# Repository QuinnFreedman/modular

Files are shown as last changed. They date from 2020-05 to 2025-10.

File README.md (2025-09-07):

This project is an attempt to make Eurorack modular synthesis affordable and accessible to everyone.

This repository contains open source software and hardware schematics for Eurorack modules which are designed to be assembled easily and cheaply without any technical knowledge. Every module should be able to be assembled for around $20 in about an hour of work, even with limited experience.

To get started, check out some of the links below. Or get in touch! Send me a message at <a href="mailto:freemodular@gmail.com">freemodular@gmail.com</a>. Follow my <a href="https://www.reddit.com/user/FreeModular/submitted/">reddit</a>, <a href="https://freemodular.etsy.com/">Etsy shop</a>, or <a href="https://github.com/QuinnFreedman/modular">GitHub</a>.

**Happy travels on your modular journey!**




<a style="display:none" href="https://freemodular.org">Go to the website to see more</a>

<h2 style="display:none">Links</h2>
<ul class="fm-index-links-container">
  <li>
    <a href="https://freemodular.org/docs/about-eurorack" class="fm-hidden-link fm-index-link">
      About Eurorack
    </a>
  </li>
  <li>
    <a href="https://freemodular.org/docs/assembly" class="fm-hidden-link fm-index-link">
      Assembly Instructions
    </a>
  </li>
  <li>
    <a href="https://freemodular.org/docs/components" class="fm-hidden-link fm-index-link">
      Get Components
    </a>
  </li>
  <li>
    <a href="https://freemodular.org/docs/peripherals" class="fm-hidden-link fm-index-link">
      Accessories
    </a>
  </li>
  <li>
    <a href="https://freemodular.org/docs/appendixn" class="fm-hidden-link fm-index-link">
      Other Resources
    </a>
  </li>
  <li>
    <a href="https://freemodular.org/docs/license" class="fm-hidden-link fm-index-link">
      License
    </a>
  </li>
</ul>

<h2 style="display:none">Modules</h2>
<ul style="display:none">
  <li><a href="https://freemodular.org/modules/Clock">Clock</a></li>
  <li><a href="https://freemodular.org/modules/Envelope">Envelope</a></li>
  <li><a href="https://freemodular.org/modules/RNG">RNG</a></li>
  <li><a href="https://freemodular.org/modules/OffsetAtten">Offset/Atten</a></li>
  <li><a href="https://freemodular.org/modules/Mixer">Mixer</a></li>
  <li><a href="https://freemodular.org/modules/Output">Output</a></li>
  <li><a href="https://freemodular.org/modules/Drift">Drift</a></li>
  <li><a href="https://freemodular.org/modules/Boost">Boost</a></li>
</ul>

{% include_relative docs/modules.md %}

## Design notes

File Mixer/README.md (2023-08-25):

# Mixer

A simple 5-channel mixer for audio or CV.

mixer faceplate

## Manual

The top 4 channels are passed to the mixer via a mute switch and an attenuator knob. The 5th channel has a mute switch but no volume knob.

The volume knobs go from basically 0v (totally off) to nearly 100% volume (this mixer cannot provide any gain boost). In reality, the inputs are not buffered before they are attenuated so the volume may depend very slightly on the output impedance of the modules feeding into the mixer. Also, some potentiometers can't actually go all the way to zero so if you want the sound to be completely muted just use the switch, which will totally disconnect the signal.

The output *is* buffered, so this is an active (not passive) mixer.

Based on the [1163 Mini Mixer](https://www.lookmumnocomputer.com/projects#/1163-mini-mixer) by Look Mum No Computer.

### Daisy Chaining

Any number of mixer modules can be daisy chained together using the "chain in" and "chain out" connectors on the back. Make sure to keep the orentation (i.e. connect the top output to the top input and the bottom to the bottom). When chained together, the normalled output of one mixer is treated as a 6th input to the other. This means that when no patch cable is connected to the output of the first mixer, it's output is routed to the next mixer. When a jack is plugged into the output of the first mixer, it is removed from the seccond mix.

## Assembly 

### Components

See [components page](https://github.com/QuinnFreedman/modular/wiki/Components) for more info.

| Reference | Part | Value | Comment |
|---|---|---|--|
| R1-R9 | Resitor | 100kΩ | Any value is fine for these, as long as they are all the same. *Technically* R6 should be 99kΩ, but the difference wouldn't be noticable. |
| R10 | Resitor | 1kΩ | Output Impedence |
| R11 | Resitor | 470Ω | This controlls the LED brightness. Higher resistance value will make the LED dimmer. You might want to experement with a wide range of values up to 10k to dial in the right brightness for your LEDs. |
| RV1-RV4 | Potentiometer  | B100kΩ | Any value should work for these |
| J1-J6 | Jack Socket | PJ301M-12 |  |
| J7 | Power header | IDC male 2x8 |  |
| J8, J9 | Jumper headers | | **(Optional)** Chain multiple modules together by connecting OUT to IN. |
| U1 | Op-amp | TL072 |  |
| D1 | LED | 3mm | Optionally, you could use a bi-directional LED here. Using a normal LED as shown in the design, with anode on top, will only illuminate when the mixer is outputting a positive voltage. |
| C1, C2 | Capacitor | 100nf | **(Optional)** Power filtering |
| C3, C4 | Capacitor | 100nf | **(Optional)** Amp stabilization |
| C5, C6 | Capacitor | 10uf | **(Optional)** Power filtering |

### Instructions

See [general assembly instructions](https://github.com/QuinnFreedman/modular/wiki/Assembly).

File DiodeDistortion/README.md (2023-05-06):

# Diode Distortion
Super simple analog voltage-controlled distortion.



## Manual

This module distorts audio by soft-clipping it using a pair of diodes. It can also be used to smoothly clip control voltages if you build it without AC-coupling.

* **A** - Distortion amount
* **B** - CV input. Summed with Distortion knob position but may be non-linear.
* **C** - Signal input
* **D** - Signal output

## Assembly

### Components

See [components page](https://github.com/QuinnFreedman/modular/wiki/Components) for more info.

| Reference | Part | Value | Comment |
|---|---|---|--|
| R1-R3 | Resistor | 100kΩ |  |
| R4-R7 | Resistor | 10kΩ |  |
| R8,R9 | Resistor | 1kΩ |  |
| RV1 | Potentiometer | 100kΩ | If you don't have a 100k pot, just scale R2, R4, and R5 proportionally. |
| C1 | 1uF | Capacitor | Part of the AC-coupling. A lower value is also fine if that's all you have. |
| C2,C3 | 100pF | Capacitor | Stabilizing capacitor for amps. **Optional** |
| C4,C5 | 10uF | Capacitor | Power filtering capacitors. **Optional** |
| C6 | 100nF | Capacitor | Power filtering capacitor. **Optional** |
| D1,D2 | Diode | 1n4148 | Any diode with forward voltage <1v would probably work here, although the effect might be different. |
| U1 | Op-amp | TL074 |  |
| U2 | Opto-isolator | NSL-32 | This allows the control voltage to modify the distortion. If you don't have this exact part, any vactrol should be fine here. Or, you can make one by taping an LED to a light-dependent resistor. If you don't care about CV, you can also just leave this out. |
| J1-J3 | Jack socket | PJ301M-12 |  |
| J4 | Pin header | 2x5 |  |

### Instructions

See [general assembly instructions](https://github.com/QuinnFreedman/modular/wiki/Assembly).

#### AC-coupling 

The default design is AC-coupled, meaning it will ignore any constant offset voltage in an audio signal. But, it means it's not suitable for manipulating CV signals. If you want to use this module to clip CV signals (or if you want to be able to deliberately tweak it by adding an ofset to your audio) just **leave out R1 and replace C1 with a bit of wire**.

#### CV control

If you don't care about CV control, this module can be even simpler. Just leave out R9, R2, U3, and J3.

#### Schematic

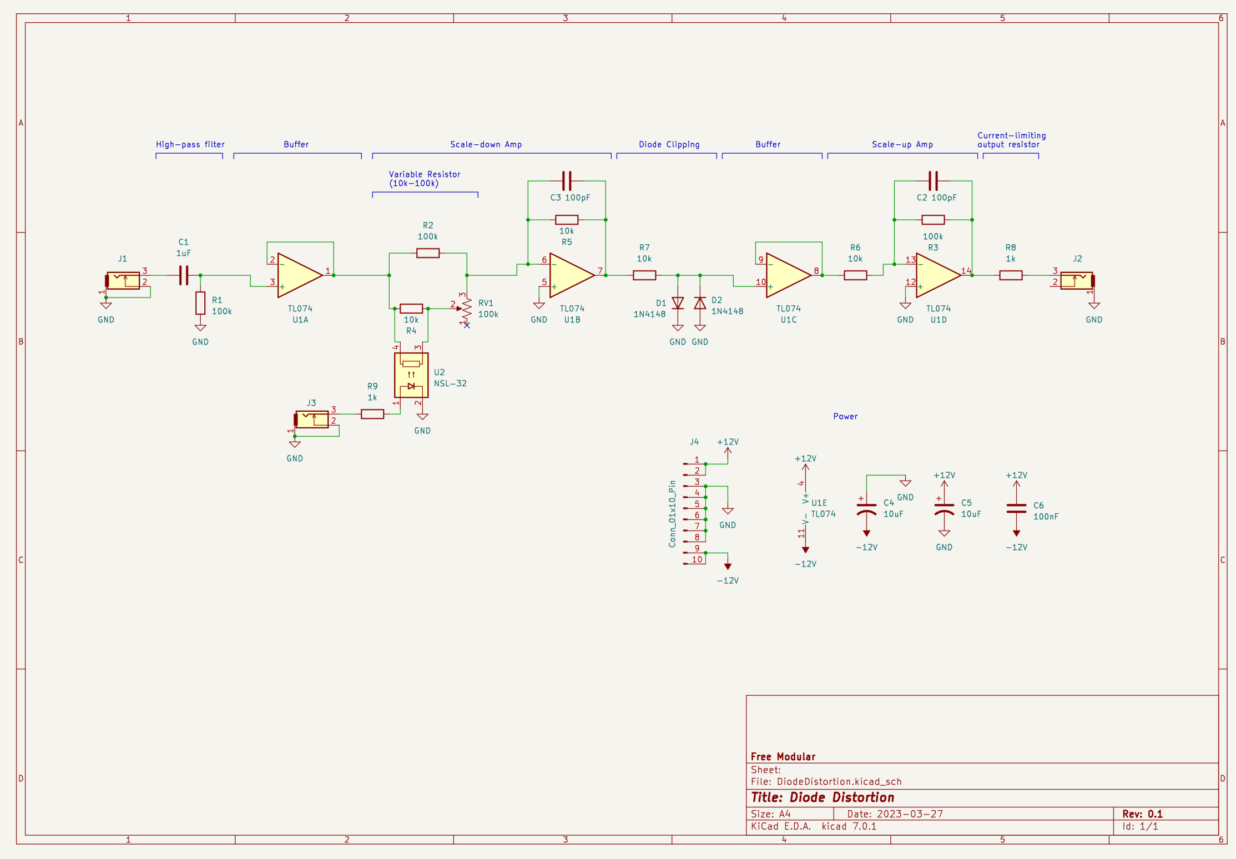
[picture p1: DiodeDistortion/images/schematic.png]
schematic


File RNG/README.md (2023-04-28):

# RNG

RNG stands for Random Number Generator. The ability to generate random control voltages is essential to creating generative music. However, purely random values can be noisy and chaotic. RNG lets you blend between looping old values and mutating them into new, random ones in a probabalistic way. It is inspired by Music Thing Modular's [Turing Machine](https://musicthing.co.uk/pages/turing.html) but with a lot of added functionality. In addition to outputting stepped random and/or looping values, RNG lets you blend between two channels of triggers/gates based on those values.

### Example uses

* Random melodies: Set Chaos to a low value and set the length to a small power of 2. Then, patch the output into a quantizer and use it as a pitch CV to generate looping but randomly generating melodies, synced with a clock.
* Drum multiplexer: Plug a drum trigger into Clock and patch A and B to trigger two different drum sounds. Then, when a drum trigger comes in it will be randomly sent to one channel or the other. This can be totally random or looping.
* Probabilistic sequencer: same as above but leave one output unconnected. This allows a sequencer without built in probability functionality to have some randomness.
* Random clock divider: Patch a steady clock into **Clock** and patch **B** out as the new clock with a high bias. This way, the clock pulses will occasionally not register, allowing two sequences to fall out of phase for syncopated polyrythms.
* Hook multiple RNGs together. Use the probabilistic clock from one of them to advance a random CV sequence from the other.

## Manual

RNG Faceplate

**(A) LEDs**. A row of LEDs across the top show the current sequence being played. Brighter LEDs correspond to higher values. The middle LED is the value currently being played.

**(B) Chaos**: Controls how much randomness in injected into the sequence. At zero (all the way left) the sequence is locked in a loop and no randomness is added. All the way to the right, each value played is completely random. In the middle, values will be played from the saved loop but with a chance of mutating each time they are played.

**(C) Length**: A rotary encoder that allows you to control the length of the sequence. When you turn the knob, the length of the sequence will be displayed in binary on the top row of LEDs. Hold the knob down to quickly skip between powers of twos. If set to a negative number (indicated with a HIGH value on the far left bit) then the sequence will "yoyo," playing alternatingly forward and backward.

### Left Side

Stepped voltage mode. This half of the module outputs a stepped random voltage 

**(D) Range**: The range/spread of the random voltages output. This is a digital scaling that is applied before the signal is output. This means that theoretically if you turned the range way down and then boosted it way back up with a VCA, you could get some digital artifacts. But, it also means that via firmware updates this could be reconfigured to effect the range or distribution of new values that are created instead of scaling the output.

**(E) Bi/unipolar**: Determines whether the values are unipolar (0 to +10v) or bipolar (-10v to +10v)

**(F) Clock** (input): Whenever HIGH, the values are advanced by one, a new value from the loop is played (and maybe mutated).

**(G) CV** (input): Control voltage to control the Chaos parameter. There are two configurable modes. It can either act as a direct CV (i.e. higher values = more randomness) or as a lock gate so it has no effect when LOW and then locks the sequence in place and prevents any mutation when HIGH.

**(H) Out** (output): Stepped random voltage output.

### Right Side

Binary choice mode. This side of the module randomly chooses between two output trigger/gates based on the value of the left side.

**(I) Bias**: The probability of outputting to channel A vs B. In practice, this input is interpreted as a threshold value. Whenever an output would be generated that is above the threshold, channel A is triggered. When it is below, channel B is triggered.

**(J) Trigger/Gate**: Chooses whether the A/B outputs should be triggers (a short voltage spike with every new clock pulse) or gates (remain steadily high until the output channel is changed). THe duration of the triggers is configurable in the firmware.

**(K) Bias** (input): Addative CV control for the Bias knob

**(L/M) A** & **B** (output): Two channels of gate/trigger output. A corresponding LED lights up when each gate is open.

## Assembly

See [general assembly instructions](https://github.com/QuinnFreedman/modular/wiki/Assembly).

### Components

See [components page](https://github.com/QuinnFreedman/modular/wiki/Components) for more info.

| Reference | PCB | Part | Value | Comment |
|---|---|---|---|--|
| R1,R2 | Front | Resistor | 100kΩ |  |
| R3,R4 | Front | Resistor | 1kΩ |  |
| R5-R8 | Front | Resistor | ~1kΩ | These resistors control the brightness of the four bottom LEDs. Their value might depend on which LEDs you use. Increasing their value will decrease the brightness. |
| R9,R11-R13,R16| Back  | Resistor | 100kΩ |  |
| R10 | Back  | Resistor | ~1kΩ | This resistor controls the brightness of all 7 top LEDs. Higher value = dimmer light |
| R14,R15 | Back  | Resistor | 50kΩ |  |
| R17 | Back  | Resistor | 470Ω |  |
| RV1-RV3 | Front | Potentiometer  | 50kΩ Linear| The value of these potentiometers doesn't really matter. `R14` and `R2` just need to be scaled to match `RV2`. So, for example, if `RV2` is 100kΩ, then `R2` should be 200kΩ and `R14` should be 100kΩ. |
| SW1 | Front | Rotary Encoder | CTY1100 or similar |  |
| SW2,SW3 | Front | Switch | TAIWAY 200CWMSP1T3B4M2 | Any SPDT switch would work here. I use [TAIWAY 200-series](https://www.taiway.com/resource/annexes/product_items/74/856052d1ea82867d7e77babb534d1633.pdf) "sub-miniature" switches because they fit behind the faceplate. The pin pitch on the PCB is 0.1in.|
| D1-D11 | Front | LED | 3mm |  |
| J1-J6 | Front | Jack | PJ301M-12  |  |
| J7-J10 | Both  | Stacking pin headers | 1x6, 1x7, 1x8, 2x3 | Cut headers to size. You can just use two rows of headers for the 2x3. You can get matching male/female pairs for a detachable connection (recommended) or just use male headers for a soldered connection. |
| J11 | Back  | Power connector| IDC male 2x8 shrouded | Or, use two rows of male pin headers |
| C1-C4 | Back  | Capacitor | 100nF | C2-C4 are optional noise-reducing bypass capacitors |
| C5-C7 | Back  | Capacitor | 10uF | Optional noise-reduction |
| U1 | Back  | LED controller | TLC5940NT  |  |
| U2 | Back  | DAC | MCP4922 |  |
| U3 | Back  | Op-amp | MCP6002 |  |
| U4 | Back  | Op-amp | TL074 |  |
| U5 | Back  | Voltage regulator | LM4040BCZ-5 (5v) |  |
| A1 | Back  | Arduino nano | v3.0 |  |

## Requirements

Arduino IDE 1.8.10 

|Library | Author | Version |
|---|---|---|
| [SPI][1] | Arduino | |
| [TLC5940][2] | Paul Stoffregen | 1.1.1 |

[1]: https://www.arduino.cc/en/reference/SPI
[2]: https://github.com/PaulStoffregen/Tlc5940

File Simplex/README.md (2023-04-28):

# Simplex

Simplex generates two channels of smooth random voltage based on the simplex noise* algorithm. Simplex noise produces values that are alway in motion but never change abruptly and never repeat. It's great for adding some subtle, organic parameter moodulation to your patch or for generating random melodies and arpeggios.

Simplex Faceplate

## Manual

### (A) Speed

Controls how quickly both channels move through time. This is like the frequency on an LFO except that the output will never repeat. A higher speed value means that the noise will varry more sharply.

### (B) Texture

Controls how "smooth" or "rough" the noise is for both channels. Texture works by adding more layers of noise with higher frequency and lower amplitude -- essentailly like overtones or harmonics in audio. If you just want "basic" smooth noise, put texture all the way to the left. If you want to have some large fluctuations over a very slow time scale while still having some quick organic jitter on top, move it towards the right. Here is a graph of output values with texture low (left) and high (right).

|Simplex noise with texture off | Simplex noise with texture high |
|---|---|
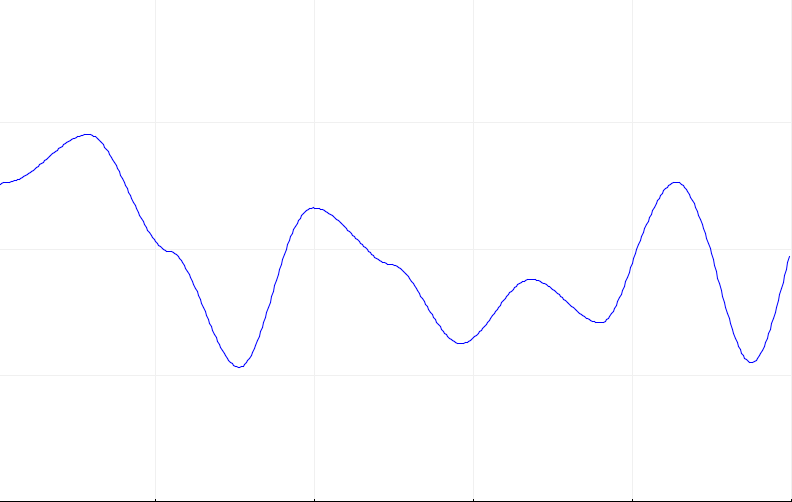
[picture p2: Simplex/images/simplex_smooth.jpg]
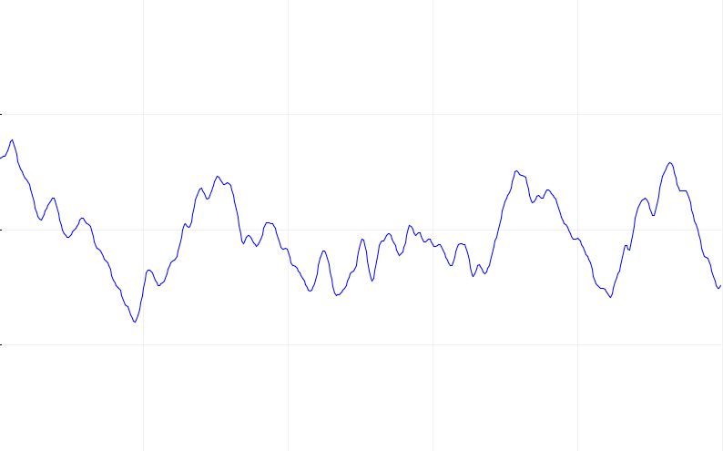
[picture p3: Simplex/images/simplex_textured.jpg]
| | 

### (C) Amplitude

Attenuates the range of output channel A. (Channel B is fixed).

### (D) Speed CV [input]

CV control for speed (both channels). 0-5v. Input is added to the speed potentiomeer value, capped at 5v.

### (E) Texture CV [input]

CV control for texture (both channels). 0-5v. Input is added to the texture potentiomeer value, capped at 5v.

### (F) & (G) Outputs

There are two output channels. Both channels will have the same speed and texture, but will be completely separate from each other.

* **A**: Channel A. -10v - +10v, attenuated by **Amplitude (C)**
* **B**: Channel B. 0-5v

## LFO Mode

This same hardware can be loaded with different firmware to function as a dual LFO. To do so, just open `config.h` and replace the line `#define FIRMWARE_MODE FIRMWARE_MODE_SIMPLEX` with `#define FIRMWARE_MODE FIRMWARE_MODE_LFO`. In LFO mode, the module has two very simple independently rate-controlled triangle LFOs. They DO NOT tract V/Oct and don't have many fancy features like tempo sync, etc. If there is a demand, I might add some of those features. For now, it's a great way to get some extra functionality out of this PCB if you had to buy multiples.

In LFO mode, the controls are as follows:

### (A) Speed A

Control of the speed of the left channel (channel A)

### (B) Speed B

Control of the speed of the right channel (channel B)

### (C) Amplitude

By default, this attenuates the range of output channel A. (Channel B is fixed). If you prefer, this can be configured to control the waveform of channel A instead. See `config.h` for configuration options.

### (D) & (E) Speed CV [input]

CV control for speed for both channels. 0-5v. Input is added to the respective speed potentiomeer value, capped at 5v. These are linear and do not track v/oct.

### (F) & (G) Outputs

There are two triangle LFO output channels, **A**, and **B**. 

* **A**: Channel A. -10v - +10v, attenuated by **Amplitude (C)**
* **B**: Channel B. 0-5v

## Assembly

### Components

See [components page](https://github.com/QuinnFreedman/modular/wiki/Components) for more info.

#### Front PCB

| Reference | Part | Value | Comment |
|---|---|---|--|
| R1,R2 | Resistor | 1kΩ |  |
| R3,R4 | Resistor | 5.1kΩ | Control LED brightness. Higher values makes the lights dimmer |
| RV1-RV3 | Potentiometer  | 50kΩ linear| Value does not matter. Any value is fine here |
| D1,D2 | LED | 3mm |  |
| J1-J4 | Jack | PJ301M-12  |  |
| J5-J6 | Stacking pin headers | 1x7, 1x3 |  |

#### Front PCB

| Reference | Part | Value | Comment |
|---|---|---|--|
| R1-R5 | Resistor | 10kΩ | The value doesn't relaly matter as long as they are all the same |
| U1 | Op-amp | TL072 |  |
| U2 | Op-amp | MCP6002 |  |
| U3 | DAC | MCP4922 |  |
| A1 | Arduino Nano | v3.0 |  |
| J5-J6 | Stacking pin headers | 1x7, 1x3 |  |
| J1 | Power connector| IDC male 2x8 shrouded | Or, use two rows of male pin headers |
| C1,C2 | Capacitor | 100nF | **Optional** noise-reducing power-filtering capacitors |
| C3-C5 | Capacitor | 10uF | **Optional** noise-reducing power-filtering capacitors |

### Instructions

See [general assembly instructions](https://github.com/QuinnFreedman/modular/wiki/Assembly).

The capacitors are intended to remove noise from the power supply. But, with my power supply, I was not able to even measure a difference. You can just leave them out if you want, or put in multiple capacitors of different values in parallel if you want to experement.

The long jumper wire in the PCB design is to connect the signal to the left LED. If you want the 2 LEDs to be identical, connect it with a wire as shown in the Fritzing PCB view, from J1 to J3. If you want to use a bipolar LED for the left channel (so it will be a different color when the output is negative), instead connect the bottom jumper wire terminal with the top of the 1k resistor right next to it (J2 to J3). You will probably also want to replace the adjacent 220Ohm resistor with something approx 2x larger since the voltage will be [-10v,+10v] instead of [0,+5v].

The stacking headers that hold the 3 layers together are not evenly spaced. You may want to additionally use some standoffs in provided the holes to keep the panels from coming apart when you push on them. Make sure the standoffs aren't too tall or they could separate the headers so the don't make a good contact.

## Requirements

Arduino IDE 1.8.10 

|Library | Author | Version |
|---|---|---|
| [SPI][1] | Arduino  | |

[1]: https://www.arduino.cc/en/reference/SPI

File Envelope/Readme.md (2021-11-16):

# Envelope

A simple but powerful envelope generator with 4 modes. Can be used as a linear ADSR or exponential AD, looping or not.



# Manual

### (A) Mode Select Button

This button lets you cycle between the four modes. While pressing the button, the LEDs will illuminate to indicate which mode is selected.

### (B) LEDs

While selecting modes, the LEDs will show the active mode:
1. **(yellow)** ADSR mode
2. **(blue)** AARR mode
3. **(red)** AARR Loop mode
4. **(green)** TRAP mode

Once a mode is selected, the LEDs will show which phase the envelope is in. At any given time, the LEDs are illuminated corrosponding to the knobs/inputs that control the current phase in the current mode.

### (C) Knobs & CV input

There are 4 knobs, each with CV control from 0-5v. They control different parameters of the envelope. Their function changes based on the mode of operation. See the diagrams below for more. They are colored (1) Yellow, (2) Blue, (3) Red, (4) Green.

| Knob | ADSR | AARR | AARR Loop | TRAP Loop |
| --- | --- | --- | --- | --- |
| (1) Yellow | Attack time | Attack time | Attack time | Attack time |
| (2) Blue | Decay time | Attack rate | Attack rate | Sustain *time*  |
| (3) Red | Sustain *value* | Release time | Release time | Release time |
| (4) Green  | Release time | Release rate | Release rate | Delay time |

### (D) Gate [input]

In a non-looping mode, the gate is the the main way you interact with the envelope. When the gate is HIGH, the envelope will start to open up and will stay open (high) until the gate is set LOW. If the gate is only triggered breifly, the attack can be interupted so the envelope may never open fully.

In a looping mode, by default, the gate will stop the envelope looping as long as it is HIGH. The firmware can also be configured to *only* loop while the gate is high instead.

### (E) Ping (aka retrigger) [input]

This is a trigger input. When it recieves a trigger, it will cause the envelope to open. If the gate is closed, sending a trigger will just cause the envelope to fully open and then close again. If the gate is on, sending a trigger to ping will keep the envelope open, but will "re-trigger" it. For example, if the envelope was in a Sustain phase, re-trigger will briefly set the envelope back to 100% and then it will decay back to the Sustain level.

### (F) Out [output]

The main output. Outputs analog values between 0-5v.

### (G) Inv [output]

Outputs an inverted version of the main out, but transposed to also be between 0-5v. I.e. INV will he HIGH when OUT is LOW and LOW when OUT is HIGH. This is useful for sidechaining and other ducking.

# Modes

## ADSR mode

<p align="center" width="100%">
    ADSR graph
</p>

ADSR is a "standard" linear envelope mode with attack, decay, sustain, and release controlled by the 4 inputs, respectively.

## AARR mode

<p align="center" width="100%">
    AARR graph
</p>

AARR (or A,A',R,R') mode gives up control of the decay and sustain. Instead, knobs (2) and (4) are used to control the exponential rate of the attack & release. These controls can go through zero, so both attack and decay can be either exponential or logarithmic.

## AARR Loop mode

<p align="center" width="100%">
    AARR graph
</p>

AARR Loop is exactly like AARR mode except that it loops continuously. It goes back and forth between Attack and Release (no sustain), so it is always rising or falling.

## TRAP Loop mode

<p align="center" width="100%">
    TRAP graph
</p>

This mode could be called ASRD for Attack/Sustain/Release/Delay, but I call it TRAP for "trapezoid" to remove confusion. This mode is another looping mode where you can control how long the envelope stays HIGH and LOW between Attack/Decay in the loop. This lets you create a pulse-width modulated square wave or saw wave, or any other simple waveform.

# Assembly

### Components

See [components page](https://github.com/QuinnFreedman/modular/wiki/Components) for more info.

#### Front PCB

| Reference | Part | Value | Comment |
| --- | ---- | ----- | --- |
| R1-R8 | Resistor | 100kΩ | |
| RV1-RV4 | Potentiometer | B10kΩ | Other values would probably be fine here. |
| D1-D4 | LED | | |
| J1-J8 | Jack socket | PJ301M-12 | |
| S1 | Button | | You can use any panel-mount OFF-(ON) style push button here as long as it fits. There is breakaway section of the PCB to make room for the button. The two pins of the button will need to be soldered two the two holes marked "S1" via a bit of insulated wire. It does not matter which lead of the button connects to which hole as long as the button will connect the two points together when pressed. |
| J9-J10 | Pin headers | | Male/female pin headers to connect the front and back PCB boards |

#### Back PCB

| Reference | Part | Value | Comment |
| --- | ---- | ----- | --- |
| R1-R8 | Resistor | 100kΩ | |
| R9,R10 | Resistor | 1kΩ | Controls output impedance |
| R11-R14 | Resistor | 10kΩ | |
| R15 | Resistor | 470Ω | Goes with the voltage reference shunt. A different value might be more optimal and/or power efficient |
| Q1,Q2 | NPN Transistor | 2N3904 | |
| U1 | Op-amp | MCP6004 | |
| U2 | DAC | MCP4922 | |
| U3 | Shunt voltage ref | LM4040LP-5 | |
| C1-C4 | Capacitor | 10nF | **(Optional)** Help potentially reduce noise & feedback in input CV circuitry |
| C5 | Capacitor | 100nF | Goes with the voltage reference shunt |
| C6 | Capacitor | 100nF | **(Optional)** Bypass capacitor to reduce noise in the power supply |
| C7 | Capacitor | 10nF | **(Optional)** Bypass capacitor to reduce noise in the power supply |
| J9-J10 | Pin headers | | Male/female pin headers to connect the front and back PCB boards |
| J1 | Pin headers | | 2x8 shrouded male Eurorack power connector |
| J2 | Solder points | | Optional points to solder on connections for extra features |

### Instructions

See [general assembly instructions](https://github.com/QuinnFreedman/modular/wiki/Assembly).

### Customization & Hidden Features

There are a lot of configurable options in the `config.h` file. Edit them before uploading the firmware to chenge the behavior of the module. There are also two unused pins on the Arduino (A4 and A5) which can be set to perform other functions like end-of-rise and end-of-fall triggers if you want to make an expander or add some more inputs to the faceplate.

#### `ANALOG_READ_MAX_VALUE` and `ANALOG_READ_MIN_VALUE`

When the Arduino reads an analog value, it will get a number between 0 and 1024. However, the potentiometers might not go all the way from exactly 0 volts to exactly 5 volts. If you want to be able to totally max out a parameter (like setting the sustain at actually 100%) you can set these parameters to adjust what range the Arduino will expect. For example, if you set `ANALOG_READ_MIN_VALUE = 15`, then any raw value &le;15 will be considdered 0 volts.

#### `ATTACK_MAX_DURATION_MICROS`, `ATTACK_MIN_DURATION_MICROS`, etc...

When detecting a maximum or minimum voltage (as given by the parameters above), these parameters dictate what value that should corrospond to in the envelope.

By default, all of the times can be turned down all the way to zero, which means that the envelope will skip that segment entirely. But, this means that if you set all the knobs to zero the envelope will skip every stage and essentially not work. Setting the minimum values to even just 1 microseccond will force the envelope to actually run through that stage as fast as it can, which will probably get you the fastest LFO. Or, set it to a higher minimum if you always want a little slew in your envelope.

#### `EXP_RATE_SCALE`

How extreme the max log/exp curve is. Default: 4 Must be &gt; 0. The formula for the exponential curve is given by:



Where `t` is time, `k` is knob position, and `r` is `EXP_RATE_SCALE`.

#### `LOOP_WHEN_GATE_OFF`

If `true`, then the looping modes will loop when the GATE input is LOW and will pause/not loop when the GATE is HIGH. If `false`, the opposite is ture. Looping on GATE HIGH probably makes more sense in a vacuum, but GATE is normalled LOW (for the non-looping modes) which makes looping on HIGH inconvenient.

#### `LOOP_HARD_SYNC_ON_PING`

If `true`, recieving a "ping"/"retrigger" pulse while in a looping mode will cause a hard sync (i.e. go back to the beginning of the loop). If `false`, this trigger will cause the LFO to go smoothly into attack mode.

### AUX Pins

There are two unused pins on the arduino (A4 and A5) that can be configured to perform a number of features.

#### EOR and EOF triggers

If these modes are enabled, the Arduino will send short triggers to the two aux pins at the end of the rise and fall of the envelope. EOR will always trigger right after the attack phase ends (or would end if attack time is zero). EOF will trigger at the end of the release. in ADSR mode, if sustain is zero, then this means that EOF will trigger when the gate is turned off, which might be after the envelope has gone to zero.

#### Gate passthrough (`GATE_PASSTHROUGH_ENABLED true`)

When enabled, the aux pin will be triggered as long as the input gate is HIGH. This is output after the gate signal has been processed by the computer, so it may be a few milisecconds delayed from the GATE input and is pretty much a totally separate circuit. This can be useful for an LED indicator.

#### LED mode indicator (`LED_MODE_INDICATOR_ENABLED true`)

When enabled, the aux win will be held HIGH whenever the LEDs are displaying the mode (instead of the phase). This could be used to add an indicator LED or light-up button if it is confusing what state the display is in.

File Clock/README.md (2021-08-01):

# Clock

A clock module sends rythmic voltage pulses at different subdevisions or multiples of a given tempo. If you want to have any kind a syncronous tempo to your music, use a clock to drive all your other modules and keep them in sync. You can use a clock output to step a sequencer or plug it directly into gate and trigger inputs.

This clock module is loosly inspired by ALM's [Pamela's NEW Workout](https://busycircuits.com/alm017/) but it is much simpler (and thus super easy to build). It has 8 channels of clocked gates, with per-channel control of clock division, pulse width, phase shift, and swing. The outputs can only be gates (high or low) -- there are no other LFO shapes or patterns available, which cuts down on parts. There are no CV inputs by default, but they could easily be added by an expander.

## Manual


### (A) OLDED Screen

Displays menu with configurable screensaver animation

### (B) Encoder

Navigates the menu. Turn to move up/down. Click to select an item. Long-hold (.5 secconds) to enter or exit a sub-menu.

### (C) Outputs.

8 digital gate output channels (0-5v).

### Menu

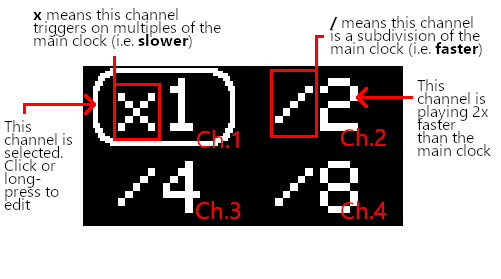
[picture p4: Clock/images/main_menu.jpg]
main menu


Scroll to move between the differnt channels and the global BPM. Click to edit the BPM or clock division. Click again to go back to navigating.

Hold the button down for .5 secconds to get an extended menu for any channel. This menu lets you edit more propperties of the channel. Long press again to get out.

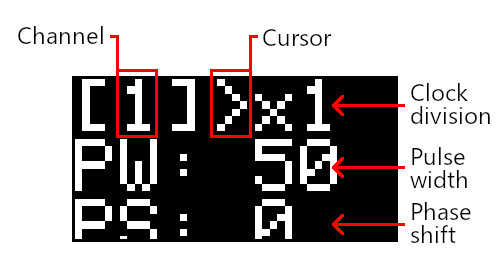
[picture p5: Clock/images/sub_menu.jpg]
sub menu


| Property | Abberviation | Details |
|---|---|---|
| Division | | The clock division sets the frequency of the channel. A value of `xN` will hit on every Nth beat of the refference clock. A value of `/N` will run N times for every cycle of the main clock. If this notation is counterintuitive to you, you can change it in configuration. This value only increments in powers of two in the main menu, but you can set odd values in the details menu.
| Pulse Width | PW | Controls how long the gate will be on. By default, each channel has a pulse width of 50 which means that it will be on for half of each cycle. If you just want a short trigger, lower this value.
| Phase Shift | PS | Controls how in/out of phase the channel is. A value of 0 means that the channel will open its gate on the exact multiple of the master clock. A positive value means it will open a little late, and a negative value will open early. The value is a percentage of *this channel*'s period, so a value of 50 will be fully out of phase or "inverted". This means that two channels with the same PS value but different clock divisions won't be in sync with eachother..
| Swing | SW | Swing is like phase shift but it only effects *every other* cycle of the channel. A channel with swing will be non-uniform. If swing is too high and pulse width isn't reduced the gate opening for the odd beats can run right into the one for the even beats, which might make it look like the clock time was just doubled. Similarly, negative swing can stretch the gate. Negative swing is disabled by default for this reason (enable it in configuration).

## Assembly

Here is a video walking you through the assembly process:

| YouTube video (http://www.youtube.com/watch?v=Xvwd0_08juQ "Video Title") |
|:----------------:|
|**Clock module assembly guide**|

See [general assembly instructions](https://github.com/QuinnFreedman/modular/wiki/Assembly).

### Components

See [components page](https://github.com/QuinnFreedman/modular/wiki/Components) for more info.

* 16 Resistors (see below for values)
* 8 Jacks
* 8 LEDs
* 1 I2C 128x64 OLED display ([Available here](https://www.amazon.com/IZOKEE-Display-SSD1306-Raspberry-White-IIC/dp/B076PDVFQD/))
* 1 Rotary encoder
* 1 Arduino Nano

### Orientation

Position the Arduino with the USB port facing downward (match the square solder pads on the Arduino to the square pad on the PCB).

Insert the LEDs with the short legs (cathodes) facing the flat side of the circles in the PCB silkscreen (aka downward when the module is mounted in the rack).

Put in the screen "upside down" with the pins at the bottom.

Put all the components on the side of each PCB with the sikscreen markings. The copper traces of the two boards should face each other.

### Resistor values

The resistors in this module can be basically any value you want. The vertical resitors (R9-R16) control the brightness of the LEDs. They can be as low as 220 Ohms for a very bright LED to 10k for a very dim one. The best value might depend on the LEDs you have.

The horizontal resistors (R1-R8) control the output imedance. This essentially slows down the flow of electricity out of the Arduino to protect it from getting overloaded if the outputs are ever connected to ground. From what I understand, `1k` is the closest to a "standard" output impedance for Eurorack, but especially for gate signals it really doesn't matter. Feel free to use whatever resistors you used for the LEDs.

### The screen

There are many OLED displays that could work with this module. Just make sure the one you get connects via I²C instead of Serial (4 wires instead of many). The one I got ([here](https://www.amazon.com/IZOKEE-Display-SSD1306-Raspberry-White-IIC/dp/B076PDVFQD/)) is .96" but you could easily fit a larger one if you re-design the faceplate slightly.

Make sure that the pins of your screen are in the same order as the labels printed on the PCB. If not, you may need to attach it with wires instead of a header so you can twist them around to make the right connections.

The screen will need to sit up above the PCB. If you are using a header, it may be easiest to bolt it to the faceplate first and then solder it on to the PCB at the right height.

The screen you buy will also have an I²C address that lets the Arduino communicate with the screen. Mine was `0x3C`. Check the manufacturer info to find your address. Enter it in at the very bottom of the `config.h` file.

## Extra features

There are a lot of configurable options defined in `config.h`. Edit it with Arduino IDE (or any other text editor). They should be self-explanitory based on their comments.

In addition there are a couple features that the hardware and software supports that I couln't find room for in the PCB or faceplate. You could put them in an expander module or put them instead of something else.

These features must be enabled in configuration.

### Pause button

Connecting pin D6 on the Arduino to GROUND will pause or un-pause the clock. Attatch a momentary push button to the output for D6 and attatch the other end to GROUND.

When the module is paused, D7 will be set HIGH (5v). You can use this to turn on an LED, a CV gate output, or both. If you prefer, you can configre it to be HIGH when the module is **not** paused. In either case, make sure to add a resistor to the output.

### Sync (follow mode) input and/or tap tempo

When you connect the D8 pin to 5v multiple times, the clock's tempo will be set to the durration between those triggers. This can be used to make a tap-tempo button and/or an input to follow an external clock (or both!).

In both cases, you will need to tie D8 to GROUND via a pulldown resistor (~10k).

#### Follow mode

If you are attatcing an external input to the module, you will need some mechanism to ensure that the voltage never goes outside of 0-5v. A transistor or opto-isolator (vactrol) should work.

#### Tap tempo

If you are just implementing a tap tempo button and don't want to solder on a pulldown resistor, you can set the pin mode of D8 ot `INPUT_PULLUP` in `setup()` in Clock.ino. Then, use a button to connect the pin to GROUND instead.

## Requirements

Arduino IDE 1.8.10 

|Library | Author | Version |
|---|---|---|
| [Adafruit SSD1306][1] | Adafruit | 2.2.0 |
| [Adafruit GFX][2] | Adafruit | 1.7.5 |

[1]: https://github.com/adafruit/Adafruit_SSD1306
[2]: https://github.com/adafruit/Adafruit-GFX-Library

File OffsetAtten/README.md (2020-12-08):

# Offset/Attenuvert

OA Faceplate

O/A is a small, analog utility module to manipulate the magnitude and level of a CV signal. For example, if you had an LFO going between (-5v - +5v), you could manipulate it to be between (+5v and +7v).

There are two identical halves, each with an offset knob and an attenvert knob.

### (A) Offset

Offset adds or subtracts an amount from the signal, from -10v to +10v.

For a CV signal, this will control the level of the signal.

For an audio signal, this will likely have no effect unless you push it far enough to clip at the edge of Eurorack's +/-10v range. In some cases, you could add a small amount to an audio signal to change how it is processed by an effect, like a wavefolder.

### (B) Attenuvert

"Attenuvert" is a mix of attenuate and invert. All the way right, the signal is passed through unaffected. At 12 o'clock, the signal is completely muted. All the way to the left, the signal is output at full volume but inverted.

### (C) Input

Audio or CV input

### (D) Output

Outputs the attenverted signal. LED indicates the level of the output signal.

## Assembly

### Components

See [components page](https://github.com/QuinnFreedman/modular/wiki/Components) for more info.

* Resistors
  * 10x 10kohm (or any value as long as they all match -- 1k is fine)
  * 2x 1kohm (controls output impedance)
  * 2x 470ohm (controls LED brightness -- I would actually reccomend something more like 1k-1.4k for dimmer LEDs)
* 4 Potentiometers (any value)
* 4 Jacks
* 2 Bi-directional LEDs (or regular LEDs if you can't find any)
* 1 TL074
* 2 10uF capacitors (optional)
* 1 100nf capacitor (optional)
* m/f stacking headers and 1 2x5 shrouded header.
    * You can also use a 2x8 shrouded header and cut off the top 6 pins.
* small standoff screws (optional)

### Instructions

See [general assembly instructions](https://github.com/QuinnFreedman/modular/wiki/Assembly).

The 100nf capacitor is meant to go on the back side of the panel, on the opposite side of the TL074.

Bidirectional or bipolar LEDs will show a different color when the output is negative or positive. If you put in regualr LEDs, they will only light up when the output is positive.

The stacking headers are only one one side of the module, so for stability you might want to use some small standoff screws to connect the other side of the two PCBs together. Their height should be approximately equal to the height of the stacking headers. There are a few hols in the PCB for this. Make sure that the screws don't touch the metal of the potentiometers or anthing else conductive. You could use plastic washers or bend some of the potentometer housings to avoid this, or only use one or two of the holes.

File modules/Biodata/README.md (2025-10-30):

<div class="fm-readme-container">
<div class="fm-row">



<div class="fm-readme-text">

<h1>Biodata</h1>

<p>Listen to plants! Generate pitch CV, gates, and raw waveforms from any biological signal. Using TENS cables (with clips or pads), Biodata listens to plants, fungi, people, or even other electronics. Based on the fluctuating electrical resistance between the probes as the subject moves or photosynthesizes, Biodata will generate quantized pitch CV and gates, as well as a raw waveform and smooth CV.</p>

<h2>Resources</h2>

<ul>
  <li><a href="https://quinnfreedman.github.io/fm-artifacts/Biodata/biodata_manual.pdf">Manual</a></li>
  <li><a href="https://quinnfreedman.github.io/modular/modules/Biodata/docs/assembly_instructions">Assembly instructions and BOM</a></li>
  <li>Interactive BOM: <a href="https://quinnfreedman.github.io/fm-artifacts/Biodata/biodata_front_pcb_interactive_bom.html">front panel</a>, <a href="https://quinnfreedman.github.io/fm-artifacts/Biodata/biodata_back_pcb_interactive_bom.html">back panel</a></li>
  <li><a href="https://quinnfreedman.github.io/fm-artifacts/Biodata/biodata_faceplate.svg">Faceplate stencil SVG</a></li>
  <li>GERBER files:
    <ul>
      <li>Faceplate: <a href="https://quinnfreedman.github.io/fm-artifacts/Biodata/biodata_faceplate_jlcpcb.zip">JLCPCB</a>, <a href="https://quinnfreedman.github.io/fm-artifacts/Biodata/biodata_faceplate_pcbway.zip">PCBway</a></li>
      <li>Front panel: <a href="https://quinnfreedman.github.io/fm-artifacts/Biodata/biodata_pcb_front_jlcpcb.zip">JLCPCB</a>, <a href="https://quinnfreedman.github.io/fm-artifacts/Biodata/biodata_pcb_front_pcbway.zip">PCBway</a></li>
      <li>Back panel: <a href="https://quinnfreedman.github.io/fm-artifacts/Biodata/biodata_pcb_back_jlcpcb.zip">JLCPCB</a>, <a href="https://quinnfreedman.github.io/fm-artifacts/Biodata/biodata_pcb_back_pcbway.zip">PCBway</a></li>
    </ul>
  </li>
  <li><a href="https://freemodular.org/modules/Biodata/fm_biodata_tayda_bom.csv">Tayda quick-order CSV</a> (incomplete)</li>
  <li><a href="https://quinnfreedman.github.io/fm-artifacts/Biodata/fm-biodata.hex">Firmware HEX</a></li>
  <li><a href="https://github.com/QuinnFreedman/modular/tree/main/modules/Biodata">Source code</a></li>
  <li><a href="https://quinnfreedman.github.io/fm-artifacts/Biodata/biodata_schematic.pdf">Schematic</a></li>
</ul>

</div>
</div>

<h2>Details</h2>

<b>DIY difficulty:</b> Easy<br>
<b>HP:</b> 6<br>
<b>Power usage:</b>
<table class="fm-current-table">
  <tr>
    <th></th>
    <th>Typical current</th>
    <th>Absolute maximum current</th>
  </tr>
  <tr>
    <td>+5V</td>
    <td>65mA</td>
    <td>75mA</td>
  </tr>
  <tr>
    <td>+12V</td>
    <td>4mA</td>
    <td>24mA</td>
  </tr>
  <tr>
    <td>-12V</td>
    <td>4mA</td>
    <td>5mA</td>
  </tr>
</table>

</div>

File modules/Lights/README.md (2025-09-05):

<div class="fm-readme-container">
<div class="fm-row">



<div class="fm-readme-text">

<h1>Lights</h1>

<p>Lights allows you to control almost any kind of LED strip or smart LED matrix from your Eurorack case (WS2811, WS2812B, or PWM). Lights has 2 LED outputs: one for addressable LED strips that can plat various animations and visualizations, and one for solid-color RGB strips, like room lighting.</p>

<p>Lights lets you power those strips from an external power supply, so you don't overload your Eurorack power supply, while keeping the signals <b>totally electrically isolated</b> so there is no risk of groud loops, or adding digital noise to your power bus.</p>

<h2>Coming soon</h2>

<p>This module will be available in the next few months. Want to get notified when it releases? <a href="https://mailchi.mp/7a63ae8831d2/get-updated">sign up here</a>. You will get one email when a new module goes live <b>and no other emails.</b></p>

</div>
</div>

</div>

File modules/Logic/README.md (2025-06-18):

<div class="fm-readme-container">
<div class="fm-row">



<div class="fm-readme-text">

<h1>ALU</h1>

<p>A multi-purpose utility module for performing various mathematical functions with voltage.</p>

<p>ALU (named for the <b>arithmetic logic unit</b> of a CPU) has two independent parts: a logic section capable of computing AND, OR, NOR, and XOR on two input gates, and an arithmetic section that can compute the sum, difference, maximum, and absolute value of two analog input signals.</p>

<h2>Resources</h2>

<ul>
  <li><a href="https://quinnfreedman.github.io/fm-artifacts/Logic/logic_manual.pdf">Manual</a></li>
  <li><a href="https://quinnfreedman.github.io/modular/modules/Logic/docs/assembly_instructions">Assembly instructions and BOM</a></li>
  <li>Interactive BOM: <a href="https://quinnfreedman.github.io/fm-artifacts/Logic/logic_pcb_front_interactive_bom.html">front panel</a>, <a href="https://quinnfreedman.github.io/fm-artifacts/Logic/logic_pcb_back_interactive_bom.html">back panel</a></li>
  <li><a href="https://quinnfreedman.github.io/fm-artifacts/Logic/logic_faceplate.svg">Faceplate stencil SVG</a></li>
  <li>GERBER files:
    <ul>
      <li>Faceplate: <a href="https://quinnfreedman.github.io/fm-artifacts/Logic/logic_faceplate_jlcpcb.zip">JLCPCB</a>, <a href="https://quinnfreedman.github.io/fm-artifacts/Logic/logic_faceplate_pcbway.zip">PCBway</a></li>
      <li>Front panel: <a href="https://quinnfreedman.github.io/fm-artifacts/Logic/logic_pcb_front_jlcpcb.zip">JLCPCB</a>, <a href="https://quinnfreedman.github.io/fm-artifacts/Logic/logic_pcb_front_pcbway.zip">PCBway</a></li>
      <li>Back panel: <a href="https://quinnfreedman.github.io/fm-artifacts/Logic/logic_pcb_back_jlcpcb.zip">JLCPCB</a>, <a href="https://quinnfreedman.github.io/fm-artifacts/Logic/logic_pcb_back_pcbway.zip">PCBway</a></li>
    </ul>
  </li>
  <li><a href="https://github.com/QuinnFreedman/modular/tree/main/modules/Logic">Source files</a></li>
  <li><a href="https://quinnfreedman.github.io/fm-artifacts/Logic/logic_schematic.pdf">Schematic</a></li>
</ul>

</div>
</div>

<h2>Details</h2>

<b>DIY difficulty:</b> Hard (many surface mount components, but not too small)<br>
<b>HP:</b> 4<br>
<b>Power usage:</b>
<table class="fm-current-table">
  <tr>
    <th></th>
    <th>Typical current</th>
    <th>Maximum current</th>
  </tr>
  <tr>
    <td>+5V</td>
    <td>NC</td>
    <td>-</td>
  </tr>
  <tr>
    <td>+12V</td>
    <td>&lt;10mA</td>
    <td>20mA</td>
  </tr>
  <tr>
    <td>-12V</td>
    <td>&lt;10mA</td>
    <td>20mA</td>
  </tr>
</table>

<a class="fm-etsy-link" href="https://www.etsy.com/listing/4321705342">
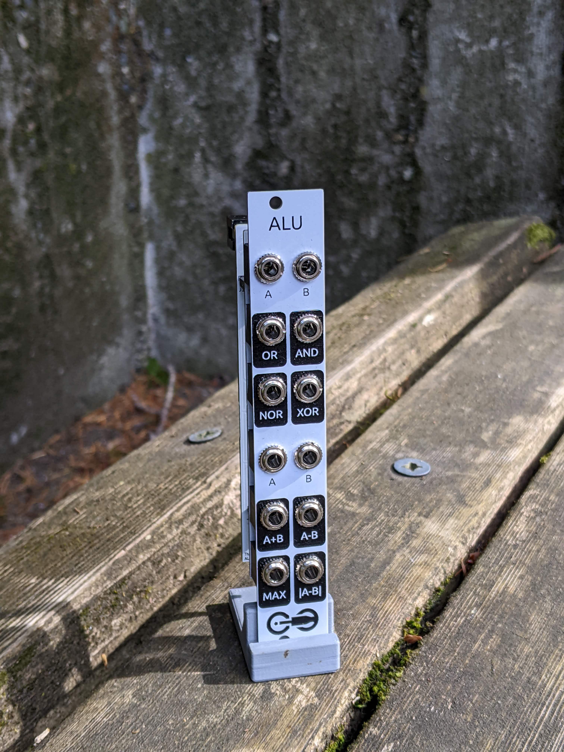
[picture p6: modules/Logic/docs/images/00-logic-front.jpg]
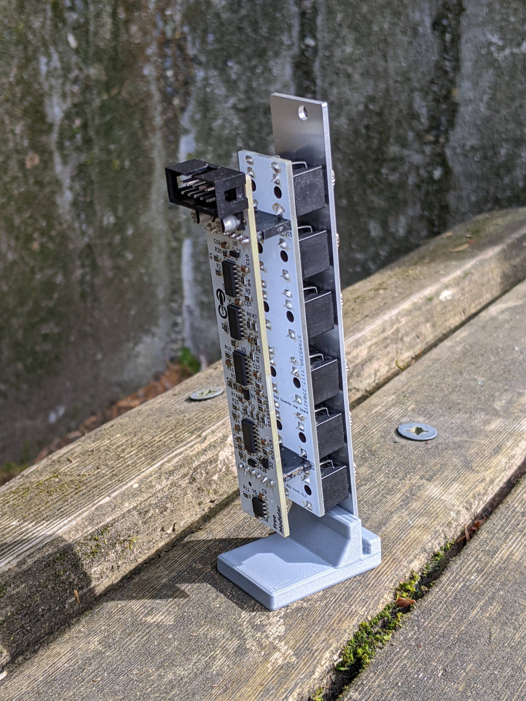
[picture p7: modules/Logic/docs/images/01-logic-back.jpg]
  
  <h3>Available on Etsy</h3>
  <p>You can buy PCBs, full kits, or hand-assembled modules directly from me on Etsy</p>
</a>

</div>

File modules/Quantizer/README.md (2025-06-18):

<div class="fm-readme-container">
<div class="fm-row">



<div class="fm-readme-text">

<h1>Quantizer</h1>

<p>A 2-channel quantizer to round v/oct pitch signals to a musical scale.</p>

<p>The two channels can be totally independent or linked together. Each channel has adjustable transposition, delay, and portamento, with sample-and-hold, track-and-hold, or continuous quantization. Quantization scales can be set note-by-note, and also saved and recalled from persistent storage.</p>

<h2>Resources</h2>

<ul>
  <li><a href="https://quinnfreedman.github.io/fm-artifacts/Quantizer/quantizer_manual.pdf">Manual</a></li>
  <li><a href="https://quinnfreedman.github.io/modular/modules/Quantizer/docs/assembly_instructions">Assembly instructions and BOM</a></li>
  <li>Interactive BOM: <a href="https://quinnfreedman.github.io/fm-artifacts/Quantizer/quantizer_front_pcb_interactive_bom.html">front panel</a>, <a href="https://quinnfreedman.github.io/fm-artifacts/Quantizer/quantizer_back_pcb_interactive_bom.html">back panel</a></li>
  <li><a href="https://quinnfreedman.github.io/fm-artifacts/Quantizer/quantizer_faceplate.svg">Faceplate stencil SVG</a></li>
  <li>GERBER files:
    <ul>
      <li>Faceplate: <a href="https://quinnfreedman.github.io/fm-artifacts/Quantizer/quantizer_faceplate_jlcpcb.zip">JLCPCB</a>, <a href="https://quinnfreedman.github.io/fm-artifacts/Quantizer/quantizer_faceplate_pcbway.zip">PCBway</a></li>
      <li>Front panel: <a href="https://quinnfreedman.github.io/fm-artifacts/Quantizer/quantizer_pcb_front_jlcpcb.zip">JLCPCB</a>, <a href="https://quinnfreedman.github.io/fm-artifacts/Quantizer/quantizer_pcb_front_pcbway.zip">PCBway</a></li>
      <li>Back panel: <a href="https://quinnfreedman.github.io/fm-artifacts/Quantizer/quantizer_pcb_back_jlcpcb.zip">JLCPCB</a>, <a href="https://quinnfreedman.github.io/fm-artifacts/Quantizer/quantizer_pcb_back_pcbway.zip">PCBway</a></li>
    </ul>
  </li>
  <li><a href="https://freemodular.org/modules/Quantizer/fm_quantizer_tayda_bom.csv">Tayda quick-order CSV</a> (incomplete)</li>
  <li><a href="https://quinnfreedman.github.io/fm-artifacts/Quantizer/fm-quantizer.hex">Firmware HEX</a></li>
  <li><a href="https://github.com/QuinnFreedman/modular/tree/main/modules/Quantizer">Source code</a></li>
  <li><a href="https://quinnfreedman.github.io/fm-artifacts/Quantizer/quantizer_schematic.pdf">Schematic</a></li>
</ul>

</div>
</div>

<h2>Details</h2>

<b>DIY difficulty:</b> Hard (One HTSSOP surface-mount part w/ ~.5mm pin pitch; everything else is easy)<br>
<b>HP:</b> 10<br>
<b>Power usage:</b>
<table class="fm-current-table">
  <tr>
    <th></th>
    <th>Maximum current</th>
  </tr>
  <tr>
    <td>+5V</td>
    <td>90mA</td>
  </tr>
  <tr>
    <td>+12V</td>
    <td>20mA</td>
  </tr>
  <tr>
    <td>-12V</td>
    <td>20mA</td>
  </tr>
</table>

<a class="fm-etsy-link" href="https://www.etsy.com/listing/4321694908">
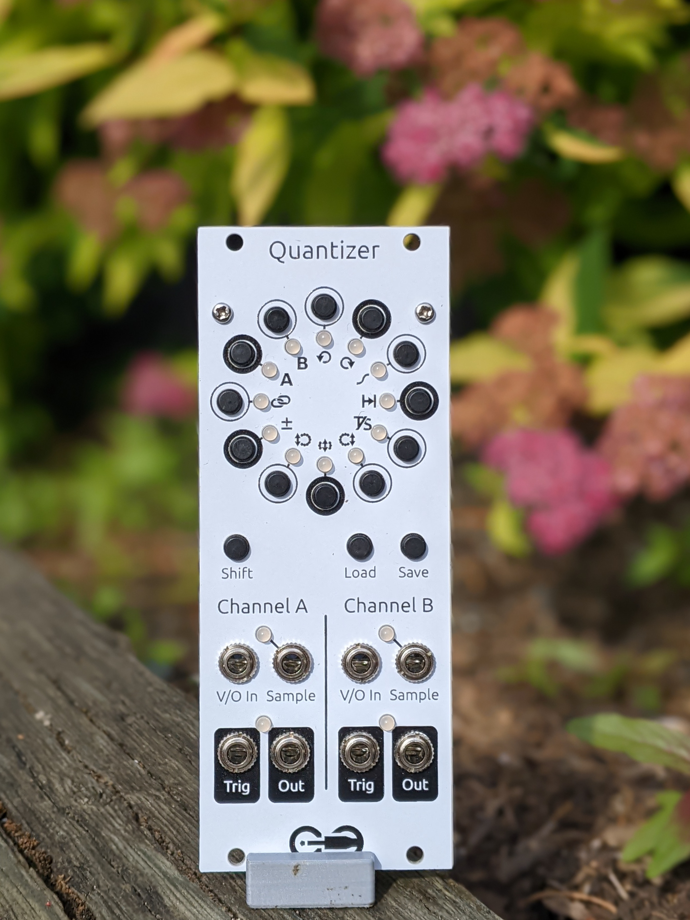
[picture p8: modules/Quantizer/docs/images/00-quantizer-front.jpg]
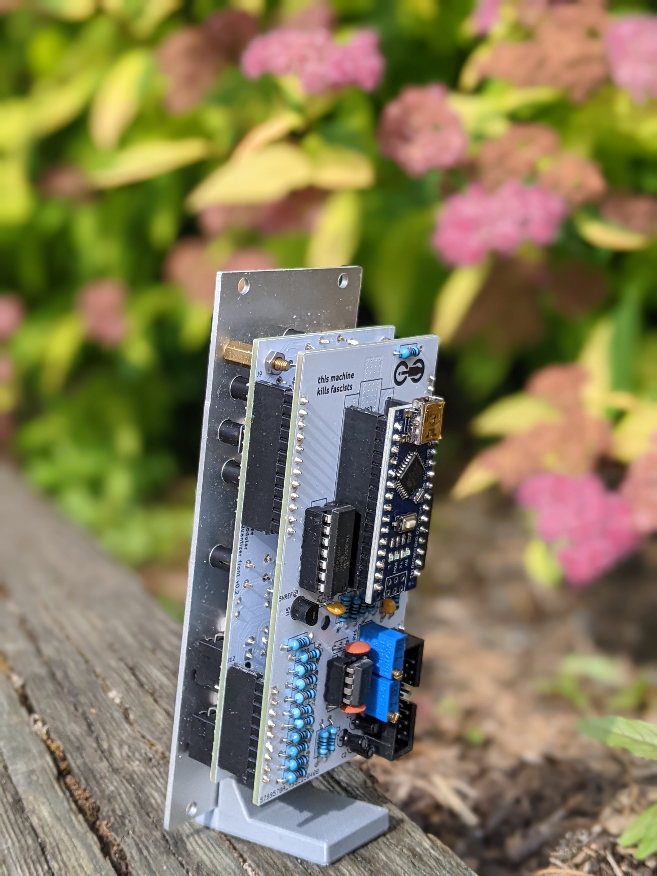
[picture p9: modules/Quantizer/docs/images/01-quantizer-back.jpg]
  
  <h3>Available on Etsy</h3>
  <p>You can buy PCBs, full kits, or hand-assembled modules directly from me on Etsy</p>
</a>

</div>

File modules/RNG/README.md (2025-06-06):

<div class="fm-readme-container">
<div class="fm-row">



<div class="fm-readme-text">

<h1>RNG</h1>

<p>If you want to make any kind of generative music, you probably want some source of randomness to keep the sound fresh and evolving. But, pure random noise can sound too chaotic and unmusical.</p>

<p>The RNG (Random Number Generator) solves this problem. It keeps a buffer of CV values that it steps through in a loop. But, every time it outputs a value, it has a change to replace that value with a new random one.</p>

<p>This module is clearly inspired by the MTM Turing Machine, but it works differently. Using a digital instead of all-hardware design allows the RNG to be more flexible with more buffer lengths and a discrete analog value for each step instead of constructing the value out of shift registers.</p>

<h2>Resources</h2>

<ul>
  <li><a href="https://quinnfreedman.github.io/fm-artifacts/RNG/rng_manual.pdf">Manual</a></li>
  <li><a href="https://quinnfreedman.github.io/modular/modules/RNG/docs/assembly_instructions">Assembly instructions and BOM</a></li>
  <li>Interactive BOM: <a href="https://quinnfreedman.github.io/fm-artifacts/RNG/rng_pcb_front_interactive_bom.html">front panel</a>, <a href="https://quinnfreedman.github.io/fm-artifacts/RNG/rng_pcb_back_interactive_bom.html">back panel</a></li>
  <li><a href="https://quinnfreedman.github.io/fm-artifacts/RNG/rng_faceplate.svg">Faceplate stencil SVG</a></li>
  <li>GERBER files:
    <ul>
      <li>Faceplate: <a href="https://quinnfreedman.github.io/fm-artifacts/RNG/rng_faceplate_jlcpcb.zip">JLCPCB</a>, <a href="https://quinnfreedman.github.io/fm-artifacts/RNG/rng_faceplate_pcbway.zip">PCBway</a></li>
      <li>Front panel: <a href="https://quinnfreedman.github.io/fm-artifacts/RNG/rng_pcb_front_jlcpcb.zip">JLCPCB</a>, <a href="https://quinnfreedman.github.io/fm-artifacts/RNG/rng_pcb_front_pcbway.zip">PCBway</a></li>
      <li>Back panel: <a href="https://quinnfreedman.github.io/fm-artifacts/RNG/rng_pcb_back_jlcpcb.zip">JLCPCB</a>, <a href="https://quinnfreedman.github.io/fm-artifacts/RNG/rng_pcb_back_pcbway.zip">PCBway</a></li>
    </ul>
  </li>
  <li>(Most) parts on Tayda: <a href="https://www.taydaelectronics.com/savecartpro/index/savenewquote/qid/02840666568">cart link</a>, <a href="https://freemodular.org/modules/RNG/fm_rng_tayda_bom.csv">quick-order CSV</a></li>
  <li><a href="https://quinnfreedman.github.io/fm-artifacts/RNG/fm-rng.hex">Firmware HEX</a></li>
  <li><a href="https://github.com/QuinnFreedman/modular/tree/main/modules/RNG">Source code</a></li>
  <li>Schematic: <a href="https://quinnfreedman.github.io/fm-artifacts/RNG/rng_pcb_front_schematic.pdf">front panel</a>, <a href="https://quinnfreedman.github.io/fm-artifacts/RNG/rng_pcb_back_schematic.pdf">back panel</a></li>
</ul>

</div>
</div>

<h2>Details</h2>

<b>DIY difficulty:</b> Hard (this module requires a little bit of surface-mount soldering, unless you pay more for a discontinued part. See <a href="docs/assembly_instructions">assembly instructions</a>)<br>
<b>HP:</b> 10<br>
<b>Power usage:</b>
<table class="fm-current-table">
  <tr>
    <th></th>
    <th>Typical</th>
    <th>Maximum</th>
  </tr>
  <tr>
    <td>+5V</td>
    <td>28mA</td>
    <td>33mA</td>
  </tr>
  <tr>
    <td>+12V</td>
    <td>4mA</td>
    <td>8mA</td>
  </tr>
  <tr>
    <td>-12V</td>
    <td>4mA</td>
    <td>8mA</td>
  </tr>
</table>

<a class="fm-etsy-link" href="https://www.etsy.com/listing/1804953907">
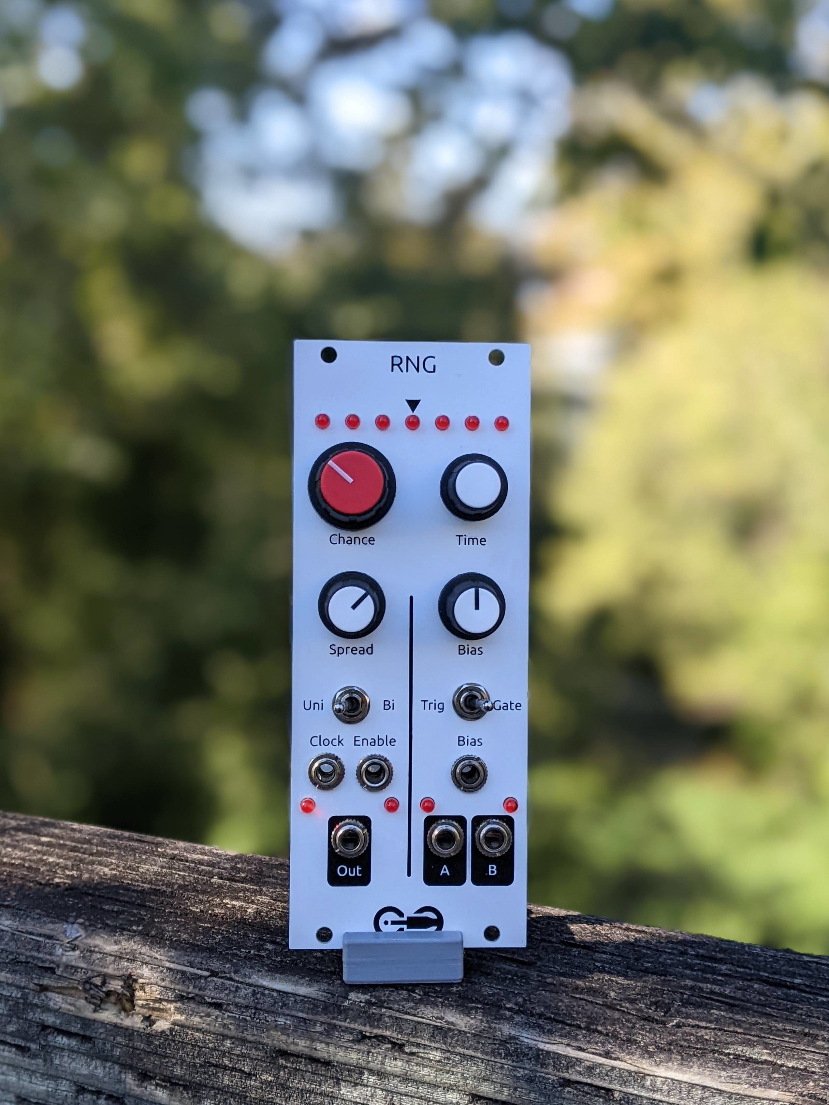
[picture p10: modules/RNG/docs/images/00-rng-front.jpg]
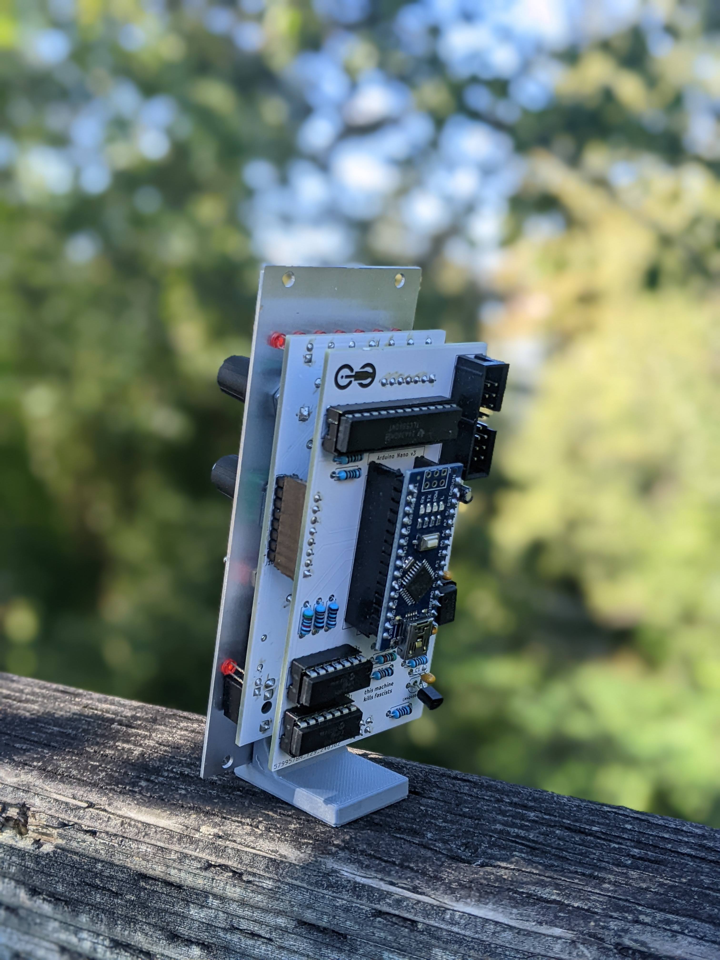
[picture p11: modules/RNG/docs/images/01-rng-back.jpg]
  
  <h3>Available on Etsy</h3>
  <p>You can buy PCBs, full kits, or hand-assembled modules directly from me on Etsy</p>
</a>

</div>

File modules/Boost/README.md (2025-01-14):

<div class="fm-readme-container">
<div class="fm-row">



<div class="fm-readme-text">

<h1>Boost</h1>

<p>A distorting, overdriving analog amplifier. Can be used to boost line-level or microphone signals with gentle overdrive, or to heavily distort Eurorack audio. Boost gives up to 26dB of gain, diode clipping, and active tone control to shape the flavor of the distortion.</p>

<h2>Resources</h2>

<ul>
  <li><a href="https://quinnfreedman.github.io/fm-artifacts/Boost/boost_manual.pdf">Manual</a></li>
  <li><a href="https://quinnfreedman.github.io/modular/modules/Boost/docs/assembly_instructions">Assembly instructions and BOM</a></li>
  <li><a href="https://quinnfreedman.github.io/fm-artifacts/Boost/boost_pcb_interactive_bom.html">Interactive BOM</a></li>
  <li><a href="https://quinnfreedman.github.io/fm-artifacts/Boost/boost_faceplate.svg">Faceplate stencil SVG</a></li>
  <li>GERBER files:
    <ul>
      <li>Faceplate: <a href="https://quinnfreedman.github.io/fm-artifacts/Boost/boost_faceplate_jlcpcb.zip">JLCPCB</a>, <a href="https://quinnfreedman.github.io/fm-artifacts/Boost/boost_faceplate_pcbway.zip">PCBway</a></li>
      <li>PCB: <a href="https://quinnfreedman.github.io/fm-artifacts/Boost/boost_jlcpcb.zip">JLCPCB</a>, <a href="https://quinnfreedman.github.io/fm-artifacts/Boost/boost_pcbway.zip">PCBway</a></li>
    </ul>
  </li>
  <li>Parts on Tayda <a href="https://www.taydaelectronics.com/savecartpro/index/savenewquote/qid/19841852897">cart link</a>, <a href="https://freemodular.org/modules/Boost/fm_boost_tayda_bom.csv">quick-order CSV</a></li>
  <li><a href="https://github.com/QuinnFreedman/modular/tree/main/modules/Boost">Source files</a></li>
  <li><a href="https://quinnfreedman.github.io/fm-artifacts/Boost/boost_schematic.pdf">Schematic PDF</a></li>
</ul>

</div>
</div>

<h2>Details</h2>

<b>DIY difficulty:</b> Very easy<br>
<b>HP:</b> 4<br>
<b>Power usage:</b> not tested yet (but probably quite low)

<a class="fm-etsy-link" href="https://www.etsy.com/listing/1858893361">
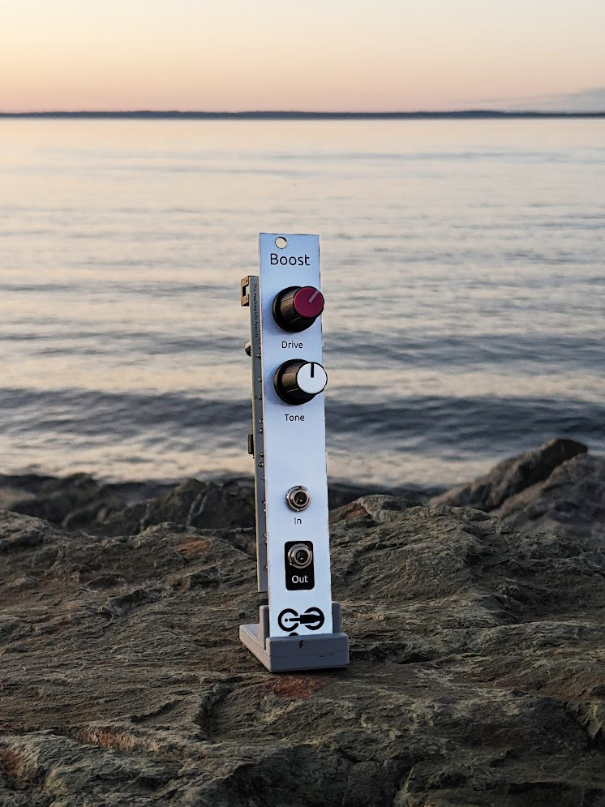
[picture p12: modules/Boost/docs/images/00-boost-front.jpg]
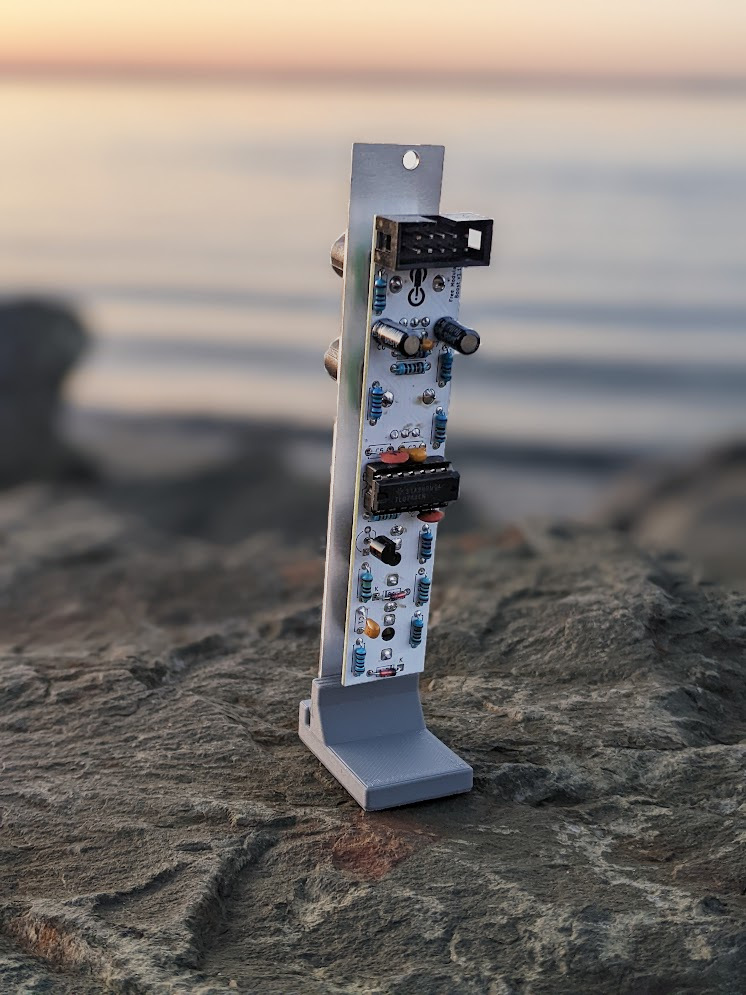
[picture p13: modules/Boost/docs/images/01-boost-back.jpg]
  
  <h3>Available on Etsy</h3>
  <p>You can buy PCBs, full kits, or hand-assembled modules directly from me on Etsy</p>
</a>

</div>

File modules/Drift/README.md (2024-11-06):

<div class="fm-readme-container">
<div class="fm-row">



<div class="fm-readme-text">

<h1>Drift</h1>

<p>A modulation source for creating organic, always changing, never repeating control voltages. The main algorithm is based on Perlin noise, but there are three other algorithms to choose from if you want a different flavor.</p>

<h2>Resources</h2>

<ul>
  <li><a href="https://quinnfreedman.github.io/fm-artifacts/Drift/drift_manual.pdf">Manual</a></li>
  <li><a href="https://quinnfreedman.github.io/modular/modules/Drift/docs/assembly_instructions">Assembly instructions and BOM</a></li>
  <li>Interactive BOM: <a href="https://quinnfreedman.github.io/fm-artifacts/Drift/drift_pcb_front_interactive_bom.html">front panel</a>, <a href="https://quinnfreedman.github.io/fm-artifacts/Drift/drift_pcb_back_interactive_bom.html">back panel</a></li>
  <li><a href="https://quinnfreedman.github.io/fm-artifacts/Drift/drift_faceplate.svg">Faceplate stencil SVG</a></li>
  <li>GERBER files:
    <ul>
      <li>Faceplate: <a href="https://quinnfreedman.github.io/fm-artifacts/Drift/drift_faceplate_jlcpcb.zip">JLCPCB</a>, <a href="https://quinnfreedman.github.io/fm-artifacts/Drift/drift_faceplate_pcbway.zip">PCBway</a></li>
      <li>Front panel: <a href="https://quinnfreedman.github.io/fm-artifacts/Drift/drift_pcb_front_jlcpcb.zip">JLCPCB</a>, <a href="https://quinnfreedman.github.io/fm-artifacts/Drift/drift_pcb_front_pcbway.zip">PCBway</a></li>
      <li>Back panel: <a href="https://quinnfreedman.github.io/fm-artifacts/Drift/drift_pcb_back_jlcpcb.zip">JLCPCB</a>, <a href="https://quinnfreedman.github.io/fm-artifacts/Drift/drift_pcb_back_pcbway.zip">PCBway</a></li>
    </ul>
  </li>
  <li>(Most) parts on Tayda: <a href="https://freemodular.org/modules/Drift/fm_drift_tayda_bom.csv">quick-order CSV</a></li>
  <li><a href="https://quinnfreedman.github.io/fm-artifacts/Drift/fm-drift.hex">Firmware HEX</a></li>
  <li><a href="https://github.com/QuinnFreedman/modular/tree/main/modules/Drift">Source code</a></li>
  <li><a href="https://quinnfreedman.github.io/fm-artifacts/Drift/drift_schematic.pdf">Schematic</a></li>
</ul>

</div>
</div>

<h2>Details</h2>

<b>DIY difficulty:</b> Very easy<br>
<b>HP:</b> 4<br>
<b>Power usage:</b>
<table class="fm-current-table">
  <tr>
    <th></th>
    <th>Maximum</th>
  </tr>
  <tr>
    <td>+5V</td>
    <td>25mA</td>
  </tr>
  <tr>
    <td>+12V</td>
    <td>5mA</td>
  </tr>
  <tr>
    <td>-12V</td>
    <td>5mA</td>
  </tr>
</table>

<a class="fm-etsy-link" href="https://www.etsy.com/listing/1788664634">
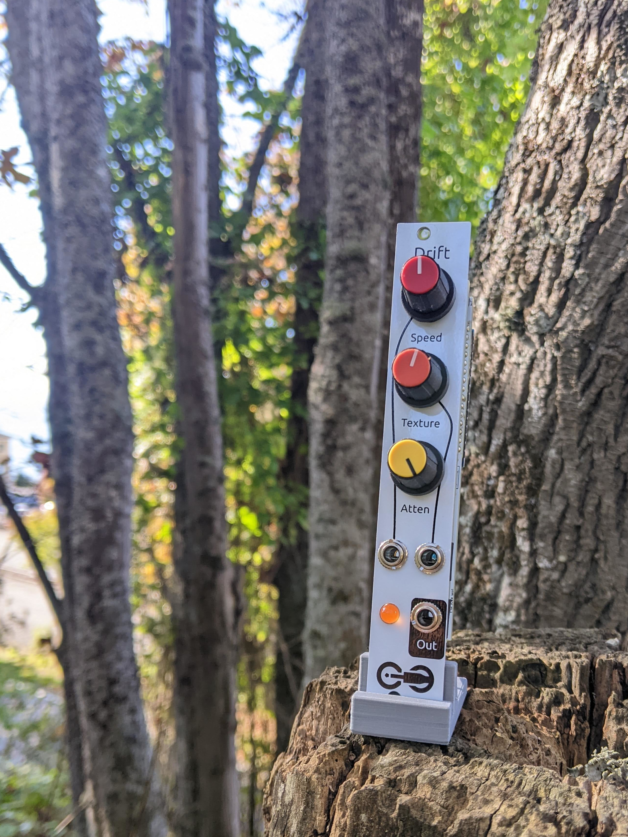
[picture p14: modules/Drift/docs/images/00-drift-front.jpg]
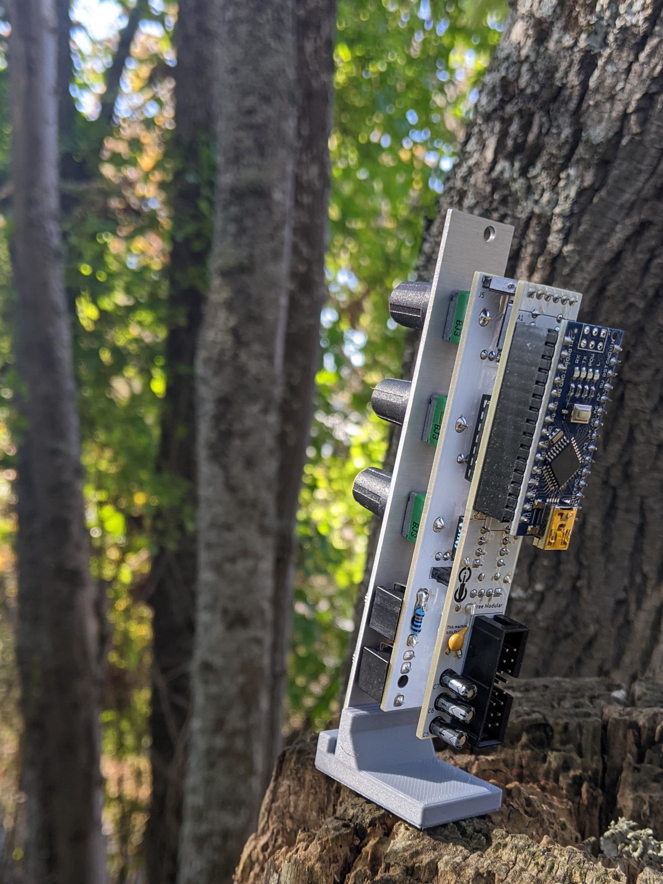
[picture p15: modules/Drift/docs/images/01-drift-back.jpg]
  
  <h3>Available on Etsy</h3>
  <p>You can buy PCBs, full kits, or hand-assembled modules directly from me on Etsy</p>
</a>

</div>

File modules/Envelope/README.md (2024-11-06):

<div class="fm-readme-container">
<div class="fm-row">



<div class="fm-readme-text">

<h1>Envelope</h1>

<p>A simple but powerful envelope generator that can cycle between 4 separate modes: traditional ADSR, AR with tunable curves, and two looping modes.</p>

<h2>Resources</h2>

<ul>
  <li><a href="https://quinnfreedman.github.io/fm-artifacts/Envelope/envelope_manual.pdf">Manual</a></li>
  <li><a href="https://quinnfreedman.github.io/modular/modules/Envelope/docs/assembly_instructions">Assembly instructions and BOM</a></li>
  <li>Interactive BOM: <a href="https://quinnfreedman.github.io/fm-artifacts/Envelope/envelope_pcb_front_interactive_bom.html">front panel</a>, <a href="https://quinnfreedman.github.io/fm-artifacts/Envelope/envelope_pcb_back_interactive_bom.html">back panel</a></li>
  <li><a href="https://quinnfreedman.github.io/fm-artifacts/Envelope/envelope_faceplate.svg">Faceplate stencil SVG</a></li>
  <li>GERBER files:
    <ul>
      <li>Faceplate: <a href="https://quinnfreedman.github.io/fm-artifacts/Envelope/envelope_faceplate_jlcpcb.zip">JLCPCB</a>, <a href="https://quinnfreedman.github.io/fm-artifacts/Envelope/envelope_faceplate_pcbway.zip">PCBway</a></li>
      <li>Front panel: <a href="https://quinnfreedman.github.io/fm-artifacts/Envelope/envelope_pcb_front_jlcpcb.zip">JLCPCB</a>, <a href="https://quinnfreedman.github.io/fm-artifacts/Envelope/envelope_pcb_front_pcbway.zip">PCBway</a></li>
      <li>Back panel: <a href="https://quinnfreedman.github.io/fm-artifacts/Envelope/envelope_pcb_back_jlcpcb.zip">JLCPCB</a>, <a href="https://quinnfreedman.github.io/fm-artifacts/Envelope/envelope_pcb_back_pcbway.zip">PCBway</a></li>
    </ul>
  </li>
  <li>(Most) parts on Tayda: <a href="https://www.taydaelectronics.com/savecartpro/index/savenewquote/qid/36140668403">cart link</a>, <a href="https://freemodular.org/modules/Envelope/fm_envelope_tayda_bom.csv">quick-order CSV</a></li>
  <li><a href="https://quinnfreedman.github.io/fm-artifacts/Envelope/fm-envelope.hex">Firmware HEX</a></li>
  <li><a href="https://github.com/QuinnFreedman/modular/tree/main/modules/Envelope">Source code</a></li>
  <li><a href="https://quinnfreedman.github.io/fm-artifacts/Envelope/envelope_schematic.pdf">Schematic</a></li>
</ul>

</div>
</div>

<h2>Details</h2>

<b>DIY difficulty:</b> Easy (adding a flying ground buss to the bottom 4 jacks is slightly finicky)<br>
<b>HP:</b> 8<br>
<b>Power usage:</b>
<table class="fm-current-table">
  <tr>
    <th></th>
    <th>Typical</th>
    <th>Maximum</th>
  </tr>
  <tr>
    <td>+5V</td>
    <td>21mA</td>
    <td>28mA</td>
  </tr>
  <tr>
    <td>+12V</td>
    <td>NC</td>
    <td>-</td>
  </tr>
  <tr>
    <td>-12V</td>
    <td>NC</td>
    <td>-</td>
  </tr>
</table>

<a class="fm-etsy-link" href="https://www.etsy.com/listing/1788676580">
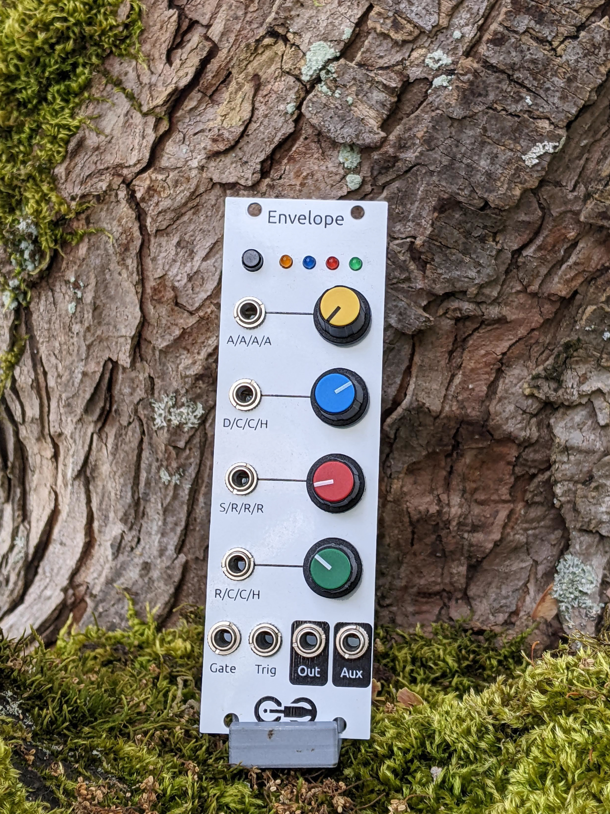
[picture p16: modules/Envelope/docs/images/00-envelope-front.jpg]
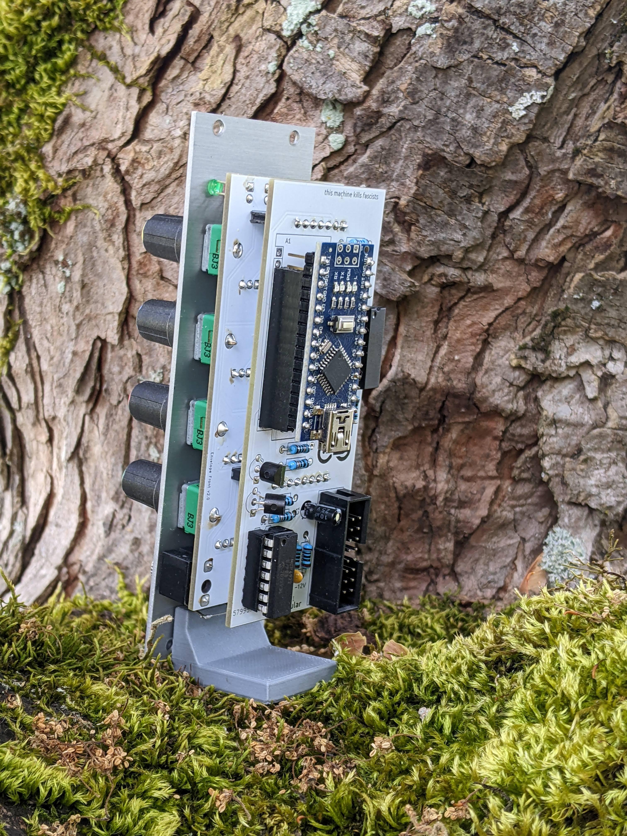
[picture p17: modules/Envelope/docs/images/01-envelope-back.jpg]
  
  <h3>Available on Etsy</h3>
  <p>You can buy PCBs, full kits, or hand-assembled modules directly from me on Etsy</p>
</a>

</div>

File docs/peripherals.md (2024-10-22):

In addition to the modules in this repository, you will need a few extra components to make a working synth. If you are new to Eurorack, you will need a case, power supply, and cables. Additionally, there aren't enough modules in this project to make a fully working synth **(yet)** so you will probably want to supplement with a few commercial modules.

## Cases

Modules on their own are just a faceplate with some circuit boards on the back. To make them usable, you will probably want a case to mount them in.

Cases are one of the most common parts to DIY. A case can really be anything as long as it has mounting rails the right distance apart. You should be able to find a bunch of examples of cool, home-built cases online. If you want to build a case yourself, you can find everything you need (rails, threaded inserts, brackets, screws, etc.) from [Modular Synth Lab](https://modularsynthlab.com/product-category/diy-eurorack-case/).

If you want to buy a case, here are some ideas:

1. [TipTop Happy Ending](http://tiptopaudio.com/happyendingkit/) is pretty much the cheapest "case" in the game. It's what I personally used when I first started out. For the price (80% of which is just the power supply) you can't really complain, but it's not the nicest looking option. It also doesn't come with any bonus features like a built-in midi input or audio output that some other small cases have.
2. [TipTop Mantis](http://tiptopaudio.com/mantis) may be the best HP-per-dollar value out there. But, again, I'm not a huge fan of the plastic-y look of this case and the lack of features.
3. [Intellijel's cases](https://intellijel.com/shop/cases/) are a little pricier but very popular. They have some I/O, power, and other cool features built into the case itself, plus you get to use Intellijel's 1U tiles.
4. The [Nifty Case](https://www.cre8audio.com/niftycase) is another option that is popular with beginners. Again, there is some stuff built in to the case (power, audio out and midi in). I haven't used it personally, but is probably what I would recommend for someone starting out. When you take into account the price of a power supply, audio interface and midi input, it's the best deal I have found. One thing to keep in mind: all my designs are skiff-friendly, meaning they will fit in this case, but most other DIY projects mount their PCBs sideways and so might not fit in this case.
5. The [Befaco Jumpskiff](https://shop.befaco.org/en/power-solutions/506-jumpskiff-diy-kit.html) is a pretty cool-looking DIY kit.
6. [4MS Pods](https://4mscompany.com/pods.php) are super tiny cases that can be chained together as your collection grows.
7. [Ikocase](https://www.etsy.com/shop/Ikocase) is a hand manufacturer of wooden cases with built-in power supplies on Etsy at pretty competitive costs.

## Power Supplies

Modules need power. Some cases come with power supplies builtin while others require you to buy dedicated power modules. 
I personally use [Synthrotek's Case Power (Green)](https://www.synthrotek.com/products/modular-circuits/case-power/) for my larger case and this much cheaper [Frequency Central DIY kit](https://frequencycentral.co.uk/product/fc-power/) for my test bench. Both work excellently for me, but do a little research to find a power supply that meets your needs. Here is a much more in-depth guide from [Perfect Circuit](https://www.perfectcircuit.com/signal/eurorack-modular-power-basics).

Make sure your power supply can output enough current to power all your modules, plus a little headroom since some modules occasionally draw an extra spike of power above their rated draw.

Many DIY modules/power supplies only have +/-12V power rails, but my digital modules also make use of the 5V rail, so make sure whatever you choose has a decent 5V supply.

## Power Cables

You will need to plug your modules into your power supply using ribbon cables like [this](https://www.sweetwater.com/store/detail/4msMultPwr16P--4ms-multi-power-cable-16-pin). They will all be 16 pins (2x8) on the side that plugs into the power supply, but they may be 16 or 10 pins ([like this](https://www.sweetwater.com/store/detail/EuroPC10-16--tiptop-audio-10-to-16-pin-eurorack-module-power-cable)) on the module side depending on if the module requires 5v power or not. You can buy them in bulk for not too much money but you can also very easily make your own. You can buy spools of ribbon cable (probably 20 wires wide), cut it into lengths, strip it down to 10 or 16 wide, and then crimp some "IDC" connectors on the end. You can crimp them with a hammer or pair of pliers but a $15 "IDC crimp tool" makes the process much easier.

**Note: Make sure you orient your cables correctly! For Eurorack cables, the red wire (carrying -12v) always faces DOWN, and the bump on the connector always faces RIGHT when you plug it in (no matter which side you are plugging in).**

[Here is a very detailed video](https://www.youtube.com/watch?v=tok3l28D55k) outlining the whole process of making or salvaging ribbon cables.

## Patch Cables

You will need a large collection of 3.5mm mono audio cables to patch your modules together. You can get a bundle from pretty much any synth seller and they are all of similar quality. The [Stackcables](https://tiptopaudio.com/stackcable/) from TipTop Audio are especially nice, but a bit pricey.

If you have some spare "Aux" cables lying around, you might be able to use those as well. Standard audio cables are stereo rather than mono, so they might not fit correctly in a Eurorack socket. But, if you find some that work for you that is probably the cheapest option.

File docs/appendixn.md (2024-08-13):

# Appendix N

The Eurorack module design community is a pretty small niche, and even fewer people are posting resources about designing modules with digital microprocessors. Here are a few resources that I have found useful when working on modules:

### YouTube
* **[Look Mum No Computer](https://www.youtube.com/lookmumnocomputer)**. Sam is a musician who makes almost all his own modules for his synthesizer. Many of the schematics for these modules are available on [his website](https://www.lookmumnocomputer.com/projects). His modules are **not** Eurorack (they are his own format which he calls Kosmo), but they are close enough that you could probably adapt them.
* **[Moritz Klein](https://www.youtube.com/@MoritzKlein0)** is another great YouTube channel that takes you through the process of designing analog modules from scratch.
* **[Aaron Lanterman](https://www.youtube.com/playlist?list=PLOunECWxELQS5bMdWo9VhmZtsCjhjYNcV)** teaches a class on Analog Circuits for Music Synthesis at Georgia Tech, and the lectures are all available online.
* **[MeeBilt](https://www.youtube.com/@MeeBilt)** has a collection of modules with original PCB designs.
* **[Benjie Jiao](https://www.youtube.com/BenjieJiao)** is another YouTube channel with a mix of original and adapted designs

### Analog module designs
* **[Dintree](http://www.dintree.com/)** is a small collection of DIY schematics for simple, analog utility modules.
* **[Skull & Circuits](https://www.skullandcircuits.com/projects/)** has the schematics for all their modules available online.
* **[Hagiwo](https://note.com/solder_state)** has a collection of budget-focused DIY designs including both analog and some digital.
* **[Kosmodular Grid](https://www.kosmodulargrid.com/)** has a bunch of modules for the Kosmo fromat (including those designed by LMNC and others) and they are mostly open source/DIY.
* **[Music From Outer Space](http://musicfromouterspace.com/index.php)** is an archive of the work of the late Ray Wilson -- a titan in the early days of DIY modular synths.
* **[Yusynth](https://yusynth.net/index_en.php)** seems to have a lot of amazing designs for oldschool 5U modules. The website is largely inscrutable to me, but some day I plan to try to decipher it and maybe translate some of the modules into Eurorack.

### Open-source digital modules
* **[Mutable Instruments](https://mutable-instruments.net)** is one of the biggest commercial Eurorack manufacturers, but Émilie Gillet makes all the code and hardware for their modules open source. These are not primarily intended as a learning resource, but having access to any open source modules as a reference was extremely helpful for me.
* **[Music Thing Modular](https://musicthing.co.uk/)** is another module manufacturer that open-sources all their modules. It's hard to understate how helpful it its to see the way real commercial modules are built to give yourself confidence that what you are doing is ok. My RNG module is also directly inspired by the MTM Turing Machine (in function, at least, if not in design).
* **[Winterbloom](https://winterbloom.com/shop)** open sources their modules, which are made with Circuit Python. A large part of their mission is education.
* **[Ornament & Crime](https://ornament-and-cri.me/)** is an open-source Eurorack module that has spawned its own community of firmware hacking.

### Other resources
* **[Otto's DIY](https://ottosdiy.com/)** makes the power adapters I use for development. They also have a few Arduino-based (and non-arduino) "recipes" although I haven't actually looked at them.
* **[Electro Smith's Daisy project](https://www.electro-smith.com/daisy/)** is a microcontroller board designed specifically for Eurorack. They sell a pre-built generic module for prototyping and a daughter board that can be used to make custom digital modules.
* **[DU-INO](http://detroitunderground.net/modular/du-ino/)** is a Detroit Underground module that can be controlled by an Arduino. I haven't played with one but for someone who wants to start making modules with an Arduino without any soldering, it might be a good place to start.
* **[Cascadence](https://github.com/cctvfm/cascadence)** is an Arduino-compatible multi-function programmable Eurorack module. It is open source but discontinued and very poorly documented.
* **[r/modular](https://www.reddit.com/r/modular/)** and **[r/synthdiy](https://www.reddit.com/r/synthdiy/)** for help with DIY assembly questions and other information.

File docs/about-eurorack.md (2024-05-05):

# What is Eurorack?

A **synthesizer** is a digital or analog device for creating electric signals which will be interpreted as audio by a speaker or recording device. You are probably used to seeing synthesizers that look a little bit like pianos, with a row of keys mapped to different notes, but this does not have to be the case.

A ***modular* synthesizer** is a kind of synthesizer made up of modules. Each module performs a specific function (like creating a sound, filtering a sound, sequencing notes, etc.) and modules can be connected together with wires called patch cables.

At its most basic level, this lets you make your ideal traditional synthesizer -- combining the oscillators, filters, and effects that you like with your favorite keyboard. But, the real magic of modular synthesis comes from the idea of **modulation**. Modules don't just input and output audio signals, but also control signals called **control voltage**. Every knob or button on a module -- like the cutoff of a filter or the attack of an envelope -- can be controlled by other modules in the system, using the same patch cables that carry audio signals. This gives you the power to create any kind of instrument you can imagine just by patching modules together in different configurations.

Your modular synth can be a traditional keyboard-driven voice, or a generative instrument that creates its own non-repeating melodies. It can be a dedicated effects unit that just processes external sound, or a drum machine that plays back samples according to a sequencer. And, it can be all these things by just re-arranging some cables.

**Eurorack** is just a standard format for modules. All these modules need to fit into a the same case, get their power from the same power supply, and output the same range of voltages so they can talk to each other. There are many different form factors for modular synthesizers, but Eurorack is by far the most popular. Eurorack modules are about 5 inches tall, work off of 12 volt power, and output +/-10v signals. All the modules in this repository are designed for Eurorack, but it shouldn't be too hard to adapt them to the standard of your choice.

Here are some quick videos that explain modular better than I can:

<div style="display:flex;flex-direction:row;gap:12px">
<iframe width="560" height="315" src="https://www.youtube-nocookie.com/embed/ex36kK8YpQo?si=qAptWIWbT7-cPVfM" title="YouTube video player" frameborder="0" allow="accelerometer; autoplay; clipboard-write; encrypted-media; gyroscope; picture-in-picture; web-share" allowfullscreen></iframe>
<iframe width="560" height="315" src="https://www.youtube-nocookie.com/embed/cWslSTTkiFU?si=1_GV7D0I4P9l7Hv7" title="YouTube video player" frameborder="0" allow="accelerometer; autoplay; clipboard-write; encrypted-media; gyroscope; picture-in-picture; web-share" allowfullscreen></iframe>
</div>

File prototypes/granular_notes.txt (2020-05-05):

1. position
2. size
3. density
  * -1 = no grains
  *  0 = (mean spacing = grain size) (if the output stdev == 0, this will recreate the original signal
  *  1 = double density (mean spacing = 1/2 grain size)
4. randomness
  * std dev of position in input (around *position*) or output or both
  * would change how freeze works
    * if randomness in where to sample from input, then freeze will have some random sounds
    * if randomness only in where to place sample, freeze will all be the same grain but with randomness in placing (i.e. 
    * if randomness in output position, positions could be calculated ahead (before audio sample comes in) so that a grain never needs to be placed in the past
    * if randomness in input sample position, then it could sample past the edges of the buffer
      * could just fold the distribution at buffer end
5. texture
  * shape of grain envelope
  * -1 = square
  *  1 = equal length attack/decay (max length)

6. pitch shift
  * V/O

7. feedback
  * -1 : no feedback
  * volume of output signal that is summed with the input and added to the front of the buffer

8. dry/wet blend

9. freeze
 * bool
 * if yes, stop recording (read cursor will stay at same point in buffer, adjustable by *position*)

/*
* density
  * 0 = no grains
  * negative = sewn regularly
  * positive = sewn randomly
*/

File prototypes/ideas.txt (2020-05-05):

1. Basic Oscillator
    * V/O CV
    * Wave shape select
    * octave select
2. Test keyboard
3. Passive attenuator
4. Passive mixer
5. ADSR Envelope (2HP?)
6. Bitcrusher
    * Switch between crushing horizontally (time) and vertically (amp)
    * Horizontal crush -> lowpass (Niquist theorem)
    * Dry/wet, crush amount controls
7. Lowpass filter 
    * Spring-damper physics based?
8. Fancy Oscillator
    * Shape/bend waveforms
    * 3 voices
9. Multivoice/detune osilator
    * Many digital voices that can be detuned from eachother
    * control voice number, detune amount, detune volume
    * Could this be done as a filter?
10. Granular synth
    * Controls:
        * Sample buffer position
        * Grain density (Negative = more random intervals b/t seeds)
            * + trig cv to seed a grain
        * Grain spread (i.e. how likely thte grain is to be sampled from far away)
        * Relative grain pitch
        * Grain length
11. Random function generator
    * Looping buffer of random values 
    * Adjustable chance for each value to be re-generated as it is played.
    * Gate to freeze loop.
    * Adjustable loop length 
12. Quantizer 
    * Scale presets (or select individual notes)

## Cases
1. Cre8Audio NiftyCASE
2. Tiptop Mantis
3. Tiptop Happy Ending

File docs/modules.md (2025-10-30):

<div class="fm-container">
  <a href="https://freemodular.org/modules/Clock" class="fm-hidden-link">
    <div class="fm-module-box">
      
      <div>
        <h2>Clock</h2>
        <p>An 8-channel clock source with adjustable pulse width, phase shift, and swing</p>
      </div>
    </div>
  </a>
  <a href="https://freemodular.org/modules/Envelope" class="fm-hidden-link">
    <div class="fm-module-box">
      
      <div>
        <h2>Envelope</h2>
        <p>A simple but powerful envelope generator/LFO with 4 modes</p>
      </div>
    </div>
  </a>
  <a href="https://freemodular.org/modules/RNG" class="fm-hidden-link">
    <div class="fm-module-box">
      
      <div>
        <h2>RNG</h2>
        <p>The Random Number Generator -- A module for creating semi-looping, randomized CV and gates. Inspired by the Turing Machine</p>
      </div>
    </div>
  </a>
  <a href="https://freemodular.org/modules/Drift" class="fm-hidden-link">
    <div class="fm-module-box">
      
      <div>
        <h2>Drift</h2>
        <p>An organically moving, never repeating modulation source with 4 different algorithms</p>
      </div>
    </div>
  </a>
  <a href="https://freemodular.org/modules/Quantizer" class="fm-hidden-link">
    <div class="fm-module-box">
      
      <div>
        <h2>Quantizer</h2>
        <p>Constrain random 1V/oct control voltages to any musical scale</p>
      </div>
    </div>
  </a>
  <a href="https://freemodular.org/modules/Logic" class="fm-hidden-link">
    <div class="fm-module-box">
      
      <div>
        <h2>ALU</h2>
        <p>A utility module for performing various math/logic functions on CV</p>
      </div>
    </div>
  </a>
  <a href="https://freemodular.org/modules/OffsetAtten" class="fm-hidden-link">
    <div class="fm-module-box">
      
      <div>
        <h2>Offset/Atten</h2>
        <p>A utility module to scale, shift, and invert signals</p>
      </div>
    </div>
  </a>
  <a href="https://freemodular.org/modules/Mixer" class="fm-hidden-link">
    <div class="fm-module-box">
      
      <div>
        <h2>Mixer</h2>
        <p>A 5-channel active mixer for audio or CV. Can be daisy-chained together for larger mixes</p>
      </div>
    </div>
  </a>
  <a href="https://freemodular.org/modules/Output" class="fm-hidden-link">
    <div class="fm-module-box">
      
      <div>
        <h2>Output</h2>
        <p>A stereo line out and headphone amp with VU meter</p>
      </div>
    </div>
  </a>
  <a href="https://freemodular.org/modules/Boost" class="fm-hidden-link">
    <div class="fm-module-box">
      
      <div>
        <h2>Boost</h2>
        <p>26db of overdriving, tone-controlled gain to boost outboard gear to synth levels or Eurorack audio into distortion</p>
      </div>
    </div>
  </a>
  <a href="https://freemodular.org/modules/Biodata" class="fm-hidden-link">
    <div class="fm-module-box">
        
        <div>
          <h2>Biodata</h2>
          <p>Listen to plants! Generate pitch CV, gates, and raw waveforms from any biological signal</p>
        </div>
    </div>
  </a>
  <a href="https://freemodular.org/modules/Lights" class="fm-hidden-link">
    <div class="fm-module-box">
        
        <div>
          <h2>Lights</h2>
          <p>Control almost any kind of LED strips with audio or CV. Turn any RGB LED strip into a spectrum analyzer, VU meter, or reactive display</p>
          <p><b>Coming soon...</b></p>
        </div>
  </div>
  </a>
</div>

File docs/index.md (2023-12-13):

<div class="fm-index-links-container">
  <a href="https://quinnfreedman.github.io/modular/docs/about-eurorack" class="fm-hidden-link fm-index-link">
    About Eurorack
  </a>
  <a href="https://quinnfreedman.github.io/modular/docs/assembly" class="fm-hidden-link fm-index-link">
    Assembly Instructions
  </a>
  <a href="https://quinnfreedman.github.io/modular/docs/components" class="fm-hidden-link fm-index-link">
    Get Components
  </a>
  <a href="https://quinnfreedman.github.io/modular/docs/peripherals" class="fm-hidden-link fm-index-link">
    Accessories
  </a>
  <a href="https://quinnfreedman.github.io/modular/docs/appendixn" class="fm-hidden-link fm-index-link">
    Other Resources
  </a>
  <a href="https://quinnfreedman.github.io/modular/docs/license" class="fm-hidden-link fm-index-link">
    License
  </a>
</div>

<div class="fm-container">
  <a href="https://quinnfreedman.github.io/modular/modules/Clock" class="fm-hidden-link">
    <div class="fm-module-box">
      
      <div>
        <h2>Clock</h2>
        <p>An 8-channel clock source with adjustable pulse width, phase shift, and swing</p>
      </div>
    </div>
  </a>
  <a href="https://quinnfreedman.github.io/modular/modules/Mixer" class="fm-hidden-link">
    <div class="fm-module-box">
      
      <div>
        <h2>Mixer</h2>
        <p>A 5-channel active mixer for audio or CV. Can be daisy-chained together for larger mixes</p>
      </div>
    </div>
  </a>
  <div class="fm-module-box">
  Coming soon...
  </div>
  <div class="fm-module-box">
  Coming soon...
  </div>
</div>l

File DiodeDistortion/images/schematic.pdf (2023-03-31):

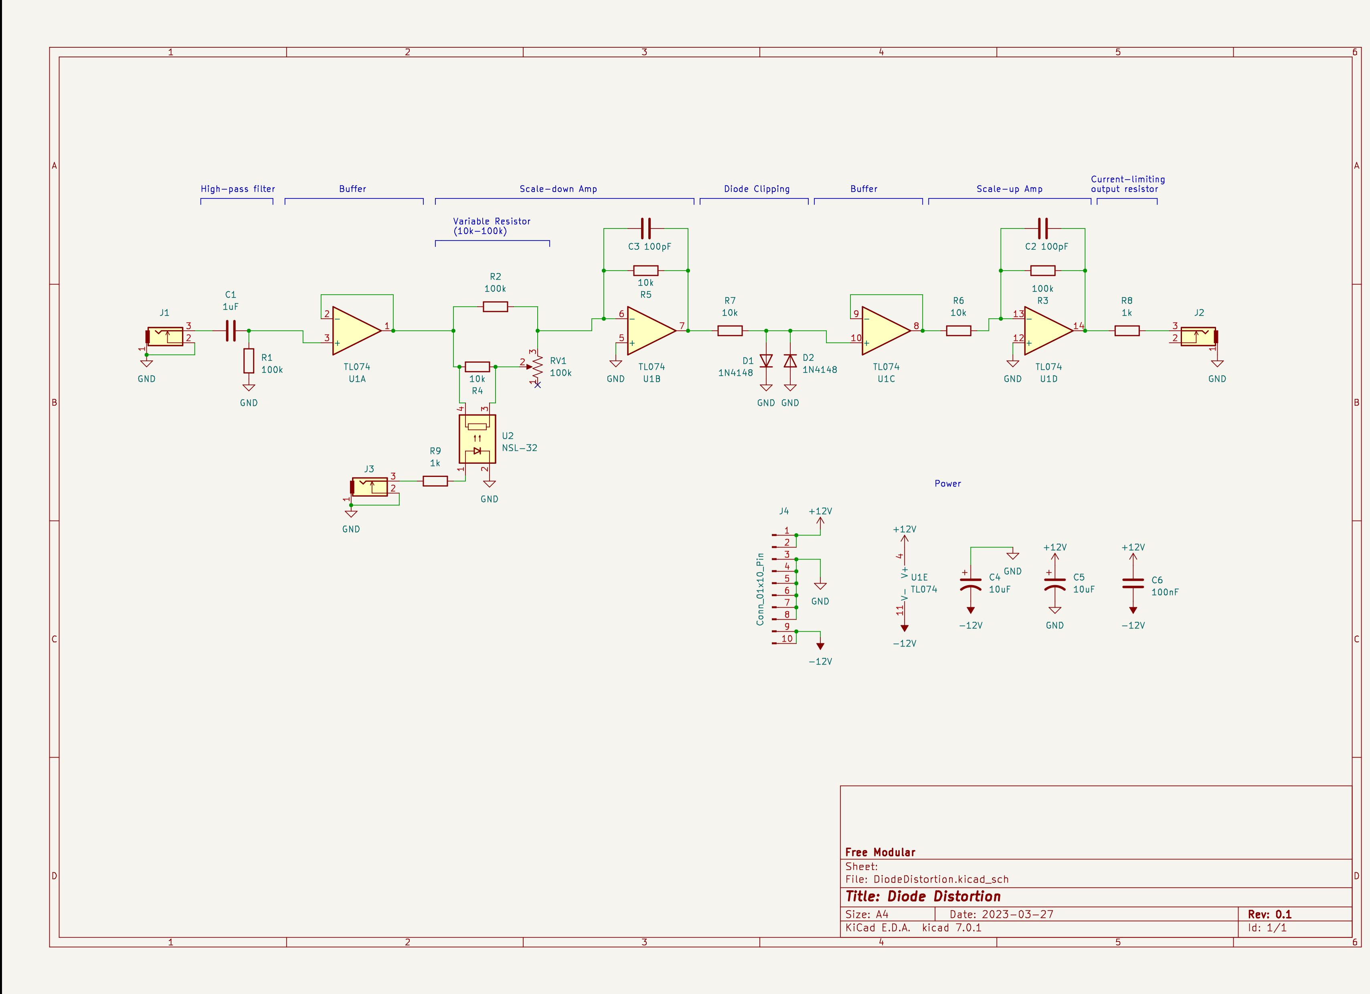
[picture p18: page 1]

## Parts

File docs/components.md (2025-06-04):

# Components

Each module will list the specific components required to build it in a **bill of materials**, which is in the **assembly instructions** for that module.

Most components can be bought from [Tayda Electronics](https://www.taydaelectronics.com/). Where specific components are missing from Tayda, they can usually be found on [Mouser](https://www.mouser.com/) or [DigiKey](https://www.digikey.com/). [Thonk](https://www.thonk.co.uk/) also carries a lot of DIY-synth specific parts, like knobs. Some generic components like capacitors and resistors can also be bought in bulk kits. Depending on how many modules you want to make, or if you want to customize them, this may be a better value.

Each module will have a Tayda quick-order CSV BoM, which you can [upload to Tayda](https://www.taydaelectronics.com/quick-order/). That will contain **most** of the parts needed. Parts not included in that list are marked in the **assembly instructions** for that module, and will need to be purchased elsewhere.

If you want to source components yourself, here are some notes on what to buy:

## Microcontrollers

The brain at the center of each digital module is a tiny computer called a microcontroller. I have used a [Arduino Nano v3](https://store.arduino.cc/usa/arduino-nano) in all my designs so far, although some future modules will probably require a more powerful controller.

You can buy first-party Arduino Nanos from the Arduino company for about $20 each, but you can also get cheep clones from third-party manufacturers for as little as $3, especially if you can buy a few at a time. Just check Amazon/Ebay/AliExpress for lots of 5 or 10.

Make sure the boards you buy have ATmega328 processors (the same processor on the genuine Nano v3) and operate at 16Mhz and 5 volts. Some cheap boards you find might use the weaker 168p processor or could be clocked at 8Mhz or 3.3 volts. In general, though, any board advertized as Nano v3 compatible should be equivalent and work fine. I have not personally found any 3rd party boards that didn't meet those criteria. The only other difference is that some third party boards may use a different USB chip which may require you to [install a driver](https://learn.sparkfun.com/tutorials/how-to-install-ch340-drivers/all) before you can flash them.

## Generic components

The exact model of these components doesn't matter. They can be bought on AliExpress, Amazon, or wherever is cheapest.

### Resistors

All my modules use 1/4 Watt THT resistors. These are the standard resistors that you will find in any DIY kit. The specific specs and tolerances do not matter.

Smaller 1/8 Watt resistors would be fine too. None of my modules use nearly enough current to push any standard resistors near their tolerances.

### Capacitors

My modules use some larger electrolytic capacitors as well as smaller ceramic disc capacitors. Again, the exact characteristics of the capacitors do not matter much here -- just make sure the capacitance value matches.

### LEDs

All my modules use 3mm lead-type/lamp-type LEDs. Again, you can buy a cheap kit with a variety of colors. All LEDs should be interchangeable, although some might be brighter than others, so you may need to adjust some resistor values to achieve the desired brightness. The specific resistors to adjust are noted in the bill of materials for each module.

Some modules also use 2-leg bipolar LEDs or 3-leg 2-color LEDs.

### Headers

Male/female pin headers allow you to connect stacked circuit boards to each other and to make removable sockets for Arduinos. Just buy a bunch and cut them down to size with wire cutters. E.g. from [here](https://www.amazon.com/gp/product/B01MQ48T2V).

2x8 male headers (or 2x5 in some cases) let you connect to the eurorack power supply. You could make these out of two rows of basic male pin headers but I highly recommend you just buy some shrouded headers so no one accidentally plugs in your module upside down and fries everything. I don't build in any reverse-current protection into my modules.

## Human interface parts: Potentiometers, Knobs, Jacks, and Switches

You can get these from [Thonk](https://www.thonk.co.uk/product-category/parts/) as well as most of them from Tayda.

### Pots

I use 15mm-shaft Alpha-style pots. You can get them from [Thonk](https://www.thonk.co.uk/shop/alpha-9mm-pots-dshaft/) or [Tayda](https://www.taydaelectronics.com/50k-ohm-linear-taper-potentiometer-d-shaft-pcb-9mm.html). Make sure you get a shaft type (D, spline, or smooth) that matches the knobs you want to use. The knobs I use are D-shaft only, so that's what I list in my BoM's.

Also, pay attention to the difference between **linear** (B type) and **logarithmic** (A type) potentiometers. Most modules want linear pots, unless they are controlling audio levels. Confusingly, [some manufacturers use "A" and "B" to mean literally the opposite](https://en.wikipedia.org/wiki/Potentiometer#Resistance%E2%80%93position_relationship:_%22taper%22) of what they usually mean. But, Alpha pots, which I primarily use, seem to stick with "B" = linear.

If they don't have the potentiometer values you need in stock, most designs are very flexible. You should be able to use any value you have as long as you adjust some corresponding resistors to match. See notes in the module's bill of materials for more info.

### Knobs

I personally use [black Sifam/Selco skirted knobs (small skirted and large skirted)](https://www.thonk.co.uk/shop/intellijel-black-knobs/) for everything and design my modules with those in mind. For these knobs, you need to buy the [colored end caps](https://www.thonk.co.uk/shop/sifam-caps/) separately and press them in. I use the colors Red, Orange, Yellow, Green, Bright Aqua, Magenta, and White.

If you want to customize the look of your modules, just look at any DIY supply store like [Thonk](https://www.thonk.co.uk/product-category/parts/knobs/), [Modular Addict](https://modularaddict.com/parts/synth-diy-parts/knob), [Amplified Parts](https://www.amplifiedparts.com/products/knobs), or [Love My Switches](https://lovemyswitches.com/knobs/), or [Tayda](https://www.taydaelectronics.com/potentiometer-variable-resistors/knobs.html). Or, get cheap lots on amazon or ebay (like [this](https://www.amazon.com/gp/product/B073BCR8T6), or [this](https://www.amazon.com/gp/product/B073BCR8T6)) Any knobs should be compatible as long as you match the shaft type to the potentiometers you are using.

### Jacks

I use the THONKICONN style jacks from Thonk (a.k.a PJ301M-12 or PJ398SM). Buy them on [Tayda](https://www.taydaelectronics.com/pj-3001f-3-5-mm-mono-phone-jack.html), [Reverb](https://reverb.com/item/16036916-thonk-50-pack-3-5mm-jack-sockets-thonkiconn-with-knurled-nuts) or [Thonk](https://www.thonk.co.uk/shop/thonkiconn/).

### Rotary encoders

A few of my modules use rotary encoders in addition to potentiometers. I have not been able to find a model of encoder that I am totally happy with. I either use the Alpha [RE111F-41B3-15F-20P](https://www.taydaelectronics.com/rotary-encoder-11mm-20-detents-d-shaft-with-switch-vertical.html), which has a very clicky action and is frustratingly a little shorter than the alpha potentiometers, or I use EC11M D-type encoders, which have a much smoother feeling click and are a bit too tall.
I have had trouble finding the EC11M from suppliers, but you can get them on amazon [here](https://www.amazon.com/DIYhz-Rotary-Encoder-Digital-Potentiometer/dp/B07D3DF8TK/).

In my experience, any rotary encoders you can buy online in the same rough form factor are totally interchangeable. The only thing you need to look out for is the number of pulses per detent. My firmware expects a 1:1 relationship (i.e. 20 pulses and 20 detents per rotation) but some encoders use a half-time encoding.

### Switches

When I use switches in my projects, I use the Taiway Sub-Mini SPDT's -- both the ON/ON's (two position) and the ON/OFF/ON's (three position). You can get them from [Love My Switches](https://lovemyswitches.com/taiway-sub-mini-spdt-on-on-switch-pcb-mount-long-shaft/), [Thonk](https://www.thonk.co.uk/shop/sub-mini-toggle-switches/), or [Amplified Parts](https://www.amplifiedparts.com/products/switch-carling-submini-toggle-spdt-2-position-pc-pins). I use Sub-mini switches, which are smaller than the "mini" switches in many DIY modules. Make sure you get the "PCB mount" version so they can solder directly into the PCB.

These switches are sold under a lot of different brands but all seem to be identical and made in the same factory.

## IC chips

All other components (integrated circuit chips, transistors, diodes, etc.) should have a specific part number specified in the module's bill of materials. You can get them from a supplier like [DigiKey](https://digikey.com/) or [Mouser](https://mouser.com).

In some cases there will be multiple skews of a single chip, specified by additional letters after the part number. For example, if you look up the TL072 op-amp on DigiKey, you will see TL072CP, TL072IP, TL072BPC, etc. Usually, these just indicate different grades (different heat tolerance, precision, etc). In general, you can just get whatever is cheap and available. But, look out for different packages. My modules use through-hole (aka large, breadboard-sized) parts wherever possible because they are easier to solder, but most chips also come in various smaller versions. Filter for `Mounting Type: Through Hole/THT` or `Package: DIP` when searching for parts.

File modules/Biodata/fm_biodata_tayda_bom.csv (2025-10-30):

sku | qty
A-2200 | 8
A-2277 | 2
A-2248 | 2
A-2203 | 3
A-2329 | 2
A-1078 | 1
A-4111 | 1
A-5459 | 5
A-531 | 1
A-3931 | 2
A-2563 | 6
A-2956 | 1
A-197 | 1
A-196 | 2
A-111 | 2
A-5590 | 1
A-7792 | 2
A-1553 | 1
A-032 | 1
A-037 | 1
A-999 | 1
A-2864 | 1

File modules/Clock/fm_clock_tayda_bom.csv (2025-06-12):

sku | qty
A-6331 | 1
A-2200 | 8
A-2203 | 8
A-7064 | 8
A-2563 | 8
A-3931 | 1
A-2956 | 1
A-196 | 2
A-197 | 1
A-2864 | 1

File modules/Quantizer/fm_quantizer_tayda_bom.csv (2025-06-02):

sku | qty
A-2200 | 18
A-2275 | 9
A-2248 | 7
A-585 | 2
A-553 | 6
A-4170 | 2
A-3931 | 3
A-2563 | 8
A-197 | 1
A-196 | 2
A-2956 | 1
A-2864 | 1
A-037 | 1
A-6163 | 1
A-001 | 2
A-004 | 1

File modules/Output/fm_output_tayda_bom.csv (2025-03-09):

sku | qty
A-2248 | 2
A-2339 | 6
A-2203 | 22
A-2198 | 8
A-2245 | 4
A-2290 | 1
A-2341 | 1
A-2202 | 1
A-2606 | 1
A-2323 | 1
A-2247 | 1
A-4009 | 2
A-553 | 24
A-531 | 4
A-3931 | 4
A-157 | 2
A-261 | 1
A-264 | 1
A-262 | 1
A-2563 | 2
A-2939 | 1
A-037 | 1
A-1138 | 5
A-031 | 4
A-1053 | 2

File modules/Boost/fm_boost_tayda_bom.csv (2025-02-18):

sku | qty
A-2203 | 2
A-2771 | 1
A-2606 | 1
A-2307 | 1
A-2207 | 1
A-2633 | 1
A-2332 | 1
A-2182 | 1
A-2248 | 2
A-2200 | 1
A-5590 | 2
A-2563 | 2
A-2939 | 1
A-157 | 2
A-111 | 1
A-5555 | 1
A-550 | 1
A-525 | 1
A-553 | 2
A-3931 | 2
A-1138 | 1

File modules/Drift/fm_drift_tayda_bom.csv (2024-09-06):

sku | qty
A-2200 | 2
A-2771 | 3
A-2248 | 2
A-553 | 4
A-3931 | 3
A-546 | 1
A-1555 | 1
A-2563 | 3
A-197 | 1
A-196 | 2
A-2956 | 1
A-5590 | 3
A-7001 | 1
A-037 | 1
A-6162 | 1
A-001 | 2
A-004 | 1
A-6504 | 1

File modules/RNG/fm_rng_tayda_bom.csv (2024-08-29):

sku | qty
A-2248 | 8
A-2200 | 3
A-2203 | 4
A-2182 | 2
A-2775 | 3
A-5590 | 3
A-261 | 11
A-6331 | 1
A-6087 | 2
A-2563 | 6
A-197 | 1
A-196 | 2
A-2956 | 1
A-553 | 5
A-3931 | 2
A-7001 | 1
A-6163 | 1
A-037 | 1

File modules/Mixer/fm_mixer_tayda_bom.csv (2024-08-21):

sku | qty
A-2248 | 9
A-2200 | 1
A-2310 | 1
A-553 | 2
A-525 | 2
A-3931 | 2
A-6486 | 4
A-6087 | 5
A-2563 | 6
A-2939 | 1
A-261 | 1
A-037 | 1

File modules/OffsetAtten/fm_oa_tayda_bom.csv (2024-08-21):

sku | qty
A-2334 | 4
A-2248 | 8
A-2203 | 2
A-2200 | 2
A-5591 | 4
A-2563 | 4
A-1076 | 2
A-3931 | 2
A-553 | 5
A-525 | 2
A-046 | 1
A-197 | 1
A-196 | 2
A-2939 | 1
A-3954 | 2
A-1247 | 2
A-1250 | 2

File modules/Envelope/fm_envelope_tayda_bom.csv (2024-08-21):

sku | qty
A-2200 | 2
A-2203 | 9
A-2248 | 12
A-2630 | 4
A-5590 | 4
A-2563 | 8
A-6163 | 1
A-004 | 1
A-111 | 2
A-196 | 2
A-197 | 1
A-7064 | 1
A-264 | 1
A-262 | 1
A-261 | 1
A-553 | 2
A-3931 | 1
A-7001 | 1
A-2956 | 1

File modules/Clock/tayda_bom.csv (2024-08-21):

sku | qty
A-6331 | 1
A-2200 | 8
A-2203 | 8
A-7064 | 8
A-2563 | 8
A-3931 | 1
A-4239 | 1
A-196 | 2
A-197 | 1
A-7001 | 1

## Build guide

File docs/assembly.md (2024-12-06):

# Assembly

The general assembly process is more or less the same for all modules:

1. Acquire PCBs/Faceplate
    - Download the GERBER files from each module's page
    - Upload the files to a PCB manufacturer like JLCPCB
    - **OR** buy boards from my [Etsy shop](https://www.etsy.com/shop/freemodular/)
2. Acquire components
    - Download the Tayda bill of materials CSV from each module's page
    - Upload them to [Tayda quick order](https://www.taydaelectronics.com/quick-order/)
    - Get any parts Tayda doesn't carry from [Mouser](https://www.mouser.com/) or [DigiKey](https://www.digikey.com/)
    - **OR** buy complete kits from my [Etsy shop](https://www.etsy.com/shop/freemodular/)
4. **Solder** everything together
    - See the notes in each module's bill of materials for specific instructions for some components
5. **Flash** the firmware onto the Arduino by USB (if applicable)

 Specific information for each module can found in the documentation for that module.

## What you will need

For information about the components you will need and where to get them, see the [components](https://quinnfreedman.github.io/modular/docs/components) page. Module-specific components may also be listed in the module's documentation.

In addition to the electrical components required for the module, you will need a soldering iron and some solder. It may also be useful to have a multimeter to check your work and a solder wick to fix your mistakes.

## Soldering

All the components of the module will be held together with solder. If you have never soldered before, don't worry! It's very easy and you will learn quickly. There are numerous videos on YouTube showing you how to do it. At first, your solder joints might look a little ugly but they should still work fine and it is very unlikely that you will damage any components in the process.

Make sure that your space is well ventilated (or use a fume extractor) and make sure to wash your hands and table afterward if you are using led solder.

## PCB

I highly recommend using printed circuit boards to make these modules. Each module has links to GERBER files which describe the PCB layout. Upload these to a manufacturing service like [PCBWay](https://www.pcbway.com/) or [JLCPCB](https://jlcpcb.com/order) to get them printed. 

Most modules are built out of a sandwich of two PCBs, so you will need to print them both.

When filling out an order, you can leave all the settings default. These PCBs do not require any special features or materials. I also try to keep all my PCBs under 100mmx100mm, which means you should get a super cheap flat rate with most manufacturers.

Some manufacturers require files in slightly different formats. GERBERs for JLCPCB and PCBWay are pre-generated for each board. If you want to use another service, try the PCBWay files. If that doesn't work, open the source files in KiCad and re-export the files you need following your manufacturers instructions.

If you want to make the modules on stripboard, a schematic PDF for each module should be linked in the module's documentation, but you will need to do the stripboard layout yourself.

## Faceplate

There is an SVG image file linked in each module's documentation with my design for the faceplate. You can print this out and use it as a stencil for marking and drilling a sheet of aluminum. If you print a stencil, make sure that it is 128.5mm tall. If not, that is an indication that the scale was messed up in the printing.

Alternatively, you can use the same service that you used for the PCBs to print a faceplate. Each module also has GERBER files for the faceplate, which can be printed as if it was a PCB. JLCPCB also offers aluminum-backed PCBs, which I highly recommend for this.

## Assembly

Each module should have a file with assembly instructions and materials. Read the comments for module-specific instructions. Additionally, each PCB has an interactive BOM, linked in the module docs, which helps you keep track of which components you need to place and where they go.

Other than that, there is no special trick to this. Put each component into the PCB in the location indicated by the silkscreen, and then solder them in place. It's general recommend to start will the smallest pieces (like resistors) and work up to the tallest components (like potentiometers). This makes it easier to lay the board flat on its back for soldering. Before soldering any panel components (like jacks, potentiometers, and switches) I recommend assembling the whole module and screwing them firmly onto the faceplate in order to make sure everything is properly aligned.

I use single row pin headers to attach boards to each other in a way that is removable. When soldering these, it is best to assemble both sides together before soldering so that you can make sure they line up. This will also help hold the headers in place. Similarly, when you solder on the headers that will hold the Arduino, it is easiest to put the Arduino in them and then solder them on as one unit.

## Checking for errors

If you want to check your module for errors before plugging it in for the first time, you can use a multimeter. Set the meter to continuity or resistance mode and touch the probes to each combination of the power pins (ground, +5v, -12v and +12v). None of these pins should be shorted to each other. Also, none of the audio/CV inputs/outputs should be shorted directly to ground (or power) when a cable is plugged in (although some of them may be connected to ground through a resistor, and some may be "normalled" to ground when a cable is disconnected). Plug in a cable to each jack and check for shorts between the shank of the cable (aka the collar or ring) and the tip, or between the tip and the power pins.

## Firmware

If the project you are assembling involves an Arduino, then you will need to load the right program onto that Arduino in order for the module to work.

Each module's documentation should link to a HEX file. That file is the program that needs to be uploaded to the Arduino. There are multiple ways to do that and none of them are as user friendly as I would like. Until I find a better tool, I recommend using [avrdudess](https://github.com/ZakKemble/AVRDUDESS). If you are on Windows, you can download the latest release from the [releases page](https://github.com/ZakKemble/AVRDUDESS/releases) and it should just work. If you are on Mac or Linux, refer to the documentation.

Make sure your module is not connected to your Eurorack case (or remove the Arduino completely from the module) before plugging it into your computer via USB.

AVRDUDESS instructions

If your Arduino does not show up when you plug it in (or if AVRDUDE is unable to write to it), you may need to [install a driver](https://learn.sparkfun.com/tutorials/how-to-install-ch340-drivers/all) (some 3rd-party clone boards use a different USB chip).

Note that most firmware will work on any Arduino Nano, but if a module's firmware uses all of the available space (like the Clock firmware), then it will only work properly with an Arduino running the newer Arduino bootloader. If your Arduino is running the old bootloader, you will need to burn a new one. This is a little more involved than uploading firmware and requires a second Arduino (of any type) to use as a programmer. See [this article](https://support.arduino.cc/hc/en-us/articles/4841602539164-Burn-the-bootloader-on-UNO-Mega-and-classic-Nano-using-another-Arduino) for detailed instructions. If your Arduino isn't working for any reason or seems bricked, re-burning the bootloader will often fix whatever is going on.

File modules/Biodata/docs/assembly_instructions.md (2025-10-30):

# Biodata Assembly Instructions

## Components

**Most** parts are available on Tayda ([quick-order CSV](https://freemodular.org/modules/Biodata/fm_biodata_tayda_bom.csv)).

See [general components notes](https://quinnfreedman.github.io/modular/docs/components) for more info about sourcing parts.

Interactive BOM: [front](https://quinnfreedman.github.io/fm-artifacts/Biodata/biodata_pcb_front_interactive_bom.html), [back](https://quinnfreedman.github.io/fm-artifacts/Biodata/biodata_pcb_back_interactive_bom.html)

| | Board | Reference | Part | Value | Source  | Comment |
| -- | ----- | --- | --- | --- | --- | --- |
| | Back  | R1, R6-R7, R13-R15 | Resistor | 1kΩ | [Tayda](https://www.taydaelectronics.com/resistors/1-4w-metal-film-resistors/10-x-resistor-1k-ohm-1-4w-1-metal-film-pkg-of-10.html) | |
| | Front | R16-R17 | Resistor | 1kΩ | - | |
| | Back  | R2, R3 | Resistor | 1MΩ | [Tayda](https://www.taydaelectronics.com/resistors/1-4w-metal-film-resistors/10-x-resistor-1m-ohm-1-4w-1-metal-film-pkg-of-10.html) | |
| | Back  | R4-R5 | Resistor | 100kΩ | [Tayda](https://www.taydaelectronics.com/resistors/1-4w-metal-film-resistors/10-x-resistor-100k-ohm-1-4w-1-metal-film-pkg-of-10.html) |  |
| | Back  | R8, R11-R12 | Resistor | 10kΩ | [Tayda](https://www.taydaelectronics.com/resistors/1-4w-metal-film-resistors/10-x-resistor-10k-ohm-1-4w-1-metal-film-pkg-of-10.html) | |
| | Back  | R9-R10 | Resistor | 220kΩ | [Tayda](https://www.taydaelectronics.com/resistor-220k-ohm-1-4w-1-metal-film-pkg-of-10.html) | |
| | Back  | C1 | Capacitor | 10nF | [Tayda](https://www.taydaelectronics.com/10nf-0-01uf-100v-5-jfa-mylar-film-capacitors.html) | |
| | Back  | C2 | Capacitor | 1nF | [Tayda](https://www.taydaelectronics.com/capacitors/polyester-mylar-film-capacitors/1nf-0-001uf-100v-5-mylar-film-capacitors.html) | |
| | Back  | C3-C4, C7-C9 | Capacitor | 100nF | [Tayda](https://www.taydaelectronics.com/100nf-50v-multilayer-monolithic-ceramic-capacitor-2-54mm-vishay.html) | |
| | Back  | C10 | Capacitor | 100pF | [Tayda](https://www.taydaelectronics.com/10-x-100pf-50v-ceramic-disc-capacitor-pkg-of-10.html) | |
| | Back  | C6-C12 | Capacitor | 10uF | [Tayda](https://www.taydaelectronics.com/10uf-16v-85c-radial-electrolytic-capacitor.html) | |
| | Front | RV1 | Potentiometer | B50k | [Tayda](https://www.taydaelectronics.com/potentiometer-variable-resistors/rotary-potentiometer/linear/50k-ohm-linear-taper-potentiometer-d-shaft-pcb-9mm.html) | Any value 1k-100k is fine |
| | Front | RV2-RV3 | Potentiometer | B50k | [Tayda](https://www.taydaelectronics.com/potentiometer-variable-resistors/rotary-potentiometer/linear/tayda-10k-ohm-linear-taper-potentiometer-spline-shaft-pcb-mount-25mm.ht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) | No-knob splined-shaft potentiometers. Any value 1k-100k is fine |
| | Front | J1-J6 | 3.5mm Jack | PJ398SM or PJ301M-12 | [Tayda](https://www.taydaelectronics.com/pj-3001f-3-5-mm-mono-phone-jack.html) | |
| | Back  | J7 | IDC connector | 2x8 | [Tayda](https://www.taydaelectronics.com/16-pin-box-header-connector-2-54mm.html) | Eurorack power header |
| | Both  | J14-J19 | Pin headers | 1x6, 1x7 | Tayda ([Male](https://www.taydaelectronics.com/40-pin-2-54-mm-single-row-pin-header-strip.html), [Female](https://www.taydaelectronics.com/40-pin-2-54-mm-single-row-female-pin-header.html)), [Amazon](https://www.amazon.com/gp/product/B074HVBTZ4) | Cut headers down to size. Attach the boards together using a male/female header pair for each connection. |
| | Back  | Q1-Q2 | NPN Transistor | 2N3904 | [Tayda](https://www.taydaelectronics.com/2n3904-npn-general-propose-transistor.html) | |
| | Front | D1 | LED | 5mm | [Tayda](https://www.taydaelectronics.com/led-5mm-green.html) | |
| | Back  | U1 | Timer/oscillator | NE555P | [Tayda](https://www.taydaelectronics.com/ne555-ic-555-texas-timer.html) | |
| | Back  | U2 | Op-amp | TL072 | [Tayda](https://www.taydaelectronics.com/tl072-low-noise-j-fet-dual-op-amp-ic.html) | TL082 is probably fine too |
| 🔴 | Back  | U3 | Power isolator | TEA 1-0505 | [DigiKey](https://www.digikey.com/short/4jjrfr39), [Mouser](https://mou.sr/3PANyDz) | This electrically isolates the power sent over the probes from the rest of the Eurorack case. This is intended to reduce 60Hz hum or other electrical interference form being picked up as part of the signal. If you don't feel this is necessary, you can short pins 1 and 3 and pins 2 and 4 to bypass this component. |
| | Back  | U4 | Signal opto-isolator | PC817X1NSZ9F | [Tayda](https://www.taydaelectronics.com/pc817a-pc817-photocoupler-phototransistor-1-channel-output-ic.html) | Electrically isolates the 555 galvanometer signal from the main power supply (see above). Again, could be omitted and bypassed by shorting pins 1 and 4. Omit R15 as well in this case. |
| 🔴 | Back  | U5 | DAC | MCP4922-E/P | [DigiKey](https://www.digikey.com/en/products/detail/microchip-technology/MCP4922-E-P/716251), [Mouser](https://mou.sr/4cwtePf) | |
| | Back  | A1 | Arduino Nano | v3.0 | [Tayda](https://www.taydaelectronics.com/type-c-nano-3-0-controller-compatible-with-arduino-nano.html) | |
| 🔴 | Both  | - | Mounting screw | M2.5x11mm standoff or bolt |  | Holds the two PCBs together. |

🔴 = Missing from Tayda BOM

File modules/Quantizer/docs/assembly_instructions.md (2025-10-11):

# Quantizer Assembly Instructions

## Components

**Most** parts are available on Tayda ([quick-order CSV](https://freemodular.org/modules/Quantizer/fm_quantizer_tayda_bom.csv)).

See [general components notes](https://quinnfreedman.github.io/modular/docs/components) for more info about sourcing parts.

Interactive BOM: [front](https://quinnfreedman.github.io/fm-artifacts/Quantizer/quantizer_pcb_front_interactive_bom.html), [back](https://quinnfreedman.github.io/fm-artifacts/Quantizer/quantizer_pcb_back_interactive_bom.html)

| | Board | Reference | Part | Value | Source  | Comment |
| -- | ----- | --- | --- | --- | --- | --- |
| | Front | R1 | Resistor | 10kΩ | [Tayda](https://www.taydaelectronics.com/resistors/1-4w-metal-film-resistors/10-x-resistor-10k-ohm-1-4w-1-metal-film-pkg-of-10.html) | |
| | Front | R2-R13 | Resistor | 1kΩ | [Tayda](https://www.taydaelectronics.com/10-x-resistor-1k-ohm-1-4w-1-metal-film-pkg-of-10.html) |  |
| | Back  | R16-R19, R31, R32 | Resistor | 1kΩ | | R14-R17 control the brightness of the four bottom IO LEDs. In the dual-color lamps I bought, the red LED was significantly dimmer than the green LED, so I used 1/10th the resistance to get approximately consistent visual brightness. If you sourced your own LEDs, you might want to set up a simple breadboard circuit to dial in these values. The remaining 15 LEDs are PWM controlled, so the brightness is compensated for in software (can also be changed, but requires the code to be recompiled). |
| | Back  | R14-R15, R20-R23, R30, R33 | Resistor | 10kΩ | | R20-R21 and R22-R23 are matched pairs. Ideally, they would be hand-picked to match each other or they would be lower-tolerance resistors. But, RV1 and RV2 optionally let you compensate for any mismatches. |
| | Back  | R24-R29, R34 | Resistor | 100kΩ | [Tayda](https://www.taydaelectronics.com/resistors/1-4w-metal-film-resistors/10-x-resistor-100k-ohm-1-4w-1-metal-film-pkg-of-10.html) | R24-R25 and R26-R27 are also matched pairs, but they are less important since they only effect the input before quantization. |
| | Back  | RV1, RV2 | Potentiometer | B1kΩ trim | [Tayda](https://www.taydaelectronics.com/potentiometer-variable-resistors/cermet-potentiometers/1k-ohm-trimmer-potentiometer-cermet-25-turns-3296w-jb.html) | **Optional.** These trim pots let you tune the output to compensate for any imperfections in the hardware. If you match R20-R21 and R22-R23 to each other, tuning shouldn't be necessary. If you don't want to bother with these, you can just short all three legs together for each potentiometer. Otherwise, you will have to adjust them by hand. |
| | Back  | C1-C3 | Capacitor | 10uF | [Tayda](https://www.taydaelectronics.com/10uf-16v-85c-radial-electrolytic-capacitor.html) | **Optional.** Power supply noise filtering capacitor |
| | Back  | C4-C8, C11 | Capacitor | 100nF | [Tayda](https://www.taydaelectronics.com/capacitors/ceramic-disc-capacitors/a-553-0-1uf-50v-ceramic-disc-capacitor-pkg-of-10.html) | **Optional.** Power filtering and decoupling |
| | Back  | C9, C10 | Capacitor | 100pF | [Tayda](https://www.taydaelectronics.com/10-x-100pf-50v-ceramic-disc-capacitor-pkg-of-10.html) | **Optional.** Amp stabilizing caps |
| | Front | J1-J8 | 3.5mm Jack | THONKICONN (a.k.a PJ398SM or PJ301M-12) | [Tayda](https://www.taydaelectronics.com/pj-3001f-3-5-mm-mono-phone-jack.html) | |
| | Both  | J9-J14, J16-J17 | Pin headers | 1x12, 1x12, 1x9, 1x10 | Tayda ([Male](https://www.taydaelectronics.com/40-pin-2-54-mm-single-row-pin-header-strip.html), [Female](https://www.taydaelectronics.com/40-pin-2-54-mm-single-row-female-pin-header.html)), [Amazon](https://www.amazon.com/gp/product/B074HVBTZ4) | Cut headers down to size. Solder the two boards directly together using the male headers or make them detachable using a male/female pair. |
| | Back  | J15 | IDC connector | 2x8 | [Tayda](https://www.taydaelectronics.com/16-pin-box-header-connector-2-54mm.html) | Eurorack power header |
| 🔴 | Front | D1-D16 | LED | 3mm red-green bi-color common anode | [Amazon](https://www.amazon.com/EDGELEC-Bi-Color-Diffused-Resistors-Included/dp/B077XG5NSC) | Make sure to get 3-pin bi-color LEDs with a shared (common) anode in a KAK-configuration (anode in the middle). When assembling, orient the LEDs so that the **red** cathode is in the **square hole**. In the LEDs I have seen, this means orienting them "normally" so that the flat edge of the bulb is aligned with the square pad, but red and green may be reversed on your LEDs. It may be worth double-checking your LEDs on a breadboard first. |
| | Back  | A1 | Arduino Nano | v3.0 | [Tayda](https://www.taydaelectronics.com/type-c-nano-3-0-controller-compatible-with-arduino-nano.html) | |
| 🔴 | Back  | U1 | DAC | MCP4922-E/P | [DigiKey](https://www.digikey.com/en/products/detail/microchip-technology/MCP4922-E-P/716251), [Mouser](https://mou.sr/4cwtePf) | |
| | Back  | U2 | Op-amp | TL072 | [Tayda](https://www.taydaelectronics.com/tl072-low-noise-j-fet-dual-op-amp-ic.html) | TL082 is probably fine too |
| | Back  | U3 | Op-amp | MCP6004 | [Tayda](https://www.taydaelectronics.com/mcp6004-single-supply-cmos-ic.html) | |
| 🔴 | Back  | U4 | LED driver | TLC5947DAP | [DigiKey](https://www.digikey.com/short/0tw1wwd2), [Mouser](https://www.mouser.com/ProductDetail/595-TLC5947DAP) | This is the only surface mount part. It is relatively small (HTSSOP). |
| 🔴 | Back  | U5 | Voltage Regulator| LM4040*IZ-5 | [DigiKey](https://www.digikey.com/en/products/detail/texas-instruments/LM4040DIZ-5-0-NOPB/212719), [Mouser](https://www.mouser.com/c/semiconductors/power-management-ics/voltage-references/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) | This is used as a reference voltage for digital <> analog conversions. If you don't care as much about accuracy or if you have a very stable 5V power rail, you can leave this out and use the 5V power rail as the reference voltage. If you do, just jump the hole labelled "5V" to the hole labelled "5VREF". In that case, leave out R33. This chip comes in "A" through "E" skews that correspond to different tolerances (and costs). |
| 🔴 | Front | SW1-SW15 | Button | TL1105SP (e.g. TL1105SPF250Q) + 1RBLK | DigiKey: [switch](https://www.digikey.com/en/products/detail/e-switch/TL1105SPF250Q/271559), [cap](https://www.digikey.com/en/products/detail/e-switch/1RBLK/271579), Mouser: [switch](https://mou.sr/3B53F7X), [cap](https://mou.sr/43x9ABF) | The caps for these switches need to be purchased separately. The caps I use are `#1RBLK`. The switches are available in different actuation forces and materials, so the last part of the part number might be a little different. Sometimes, the switches and caps will be sold together and the cap number is appended to the end of the part number. If you don't want to use these specific switches, any "6mm tactile switch" with a standard 4.5mm x 6.5mm mounting pattern like [this one](https://www.taydaelectronics.com/tact-switch-6-6mm-13mm-through-hole-spst-no.html) should work here. Those are a bit narrower, though, so you might want to adjust the faceplate accordingly. |
| 🔴 | Both  | - | Mounting screw | 2 M3x10mm standoff, 1 M3x11mm standoff or bolt |  | Two standoffs hold the front PCB to the faceplate, since the buttons don't attach to the faceplate. Optionally, you can also use one more standoff or bolt to hold the two PCBs together. |

🔴 = Missing from Tayda BOM

## Build Guide

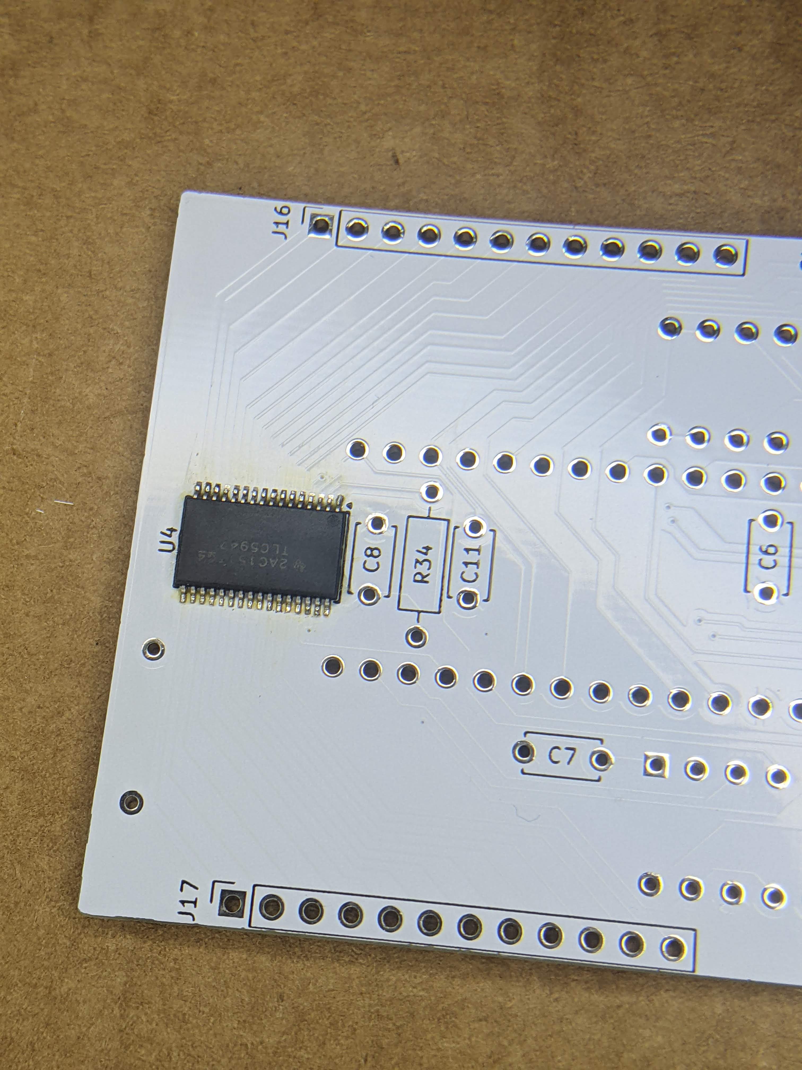
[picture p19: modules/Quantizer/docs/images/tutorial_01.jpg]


Start by soldering the TLC5947DAP. The pins are quite fine and it is very easy to accidentally short together or not connect fully. Double check that it is connected correctly before continuing.

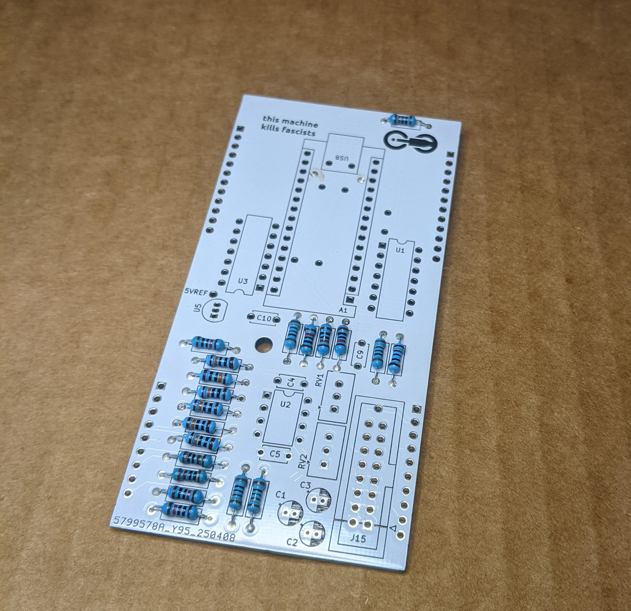
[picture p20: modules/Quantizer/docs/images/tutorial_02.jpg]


Starting on the rear board, add the resistors. Refer the interactive BOM to see which values go where.

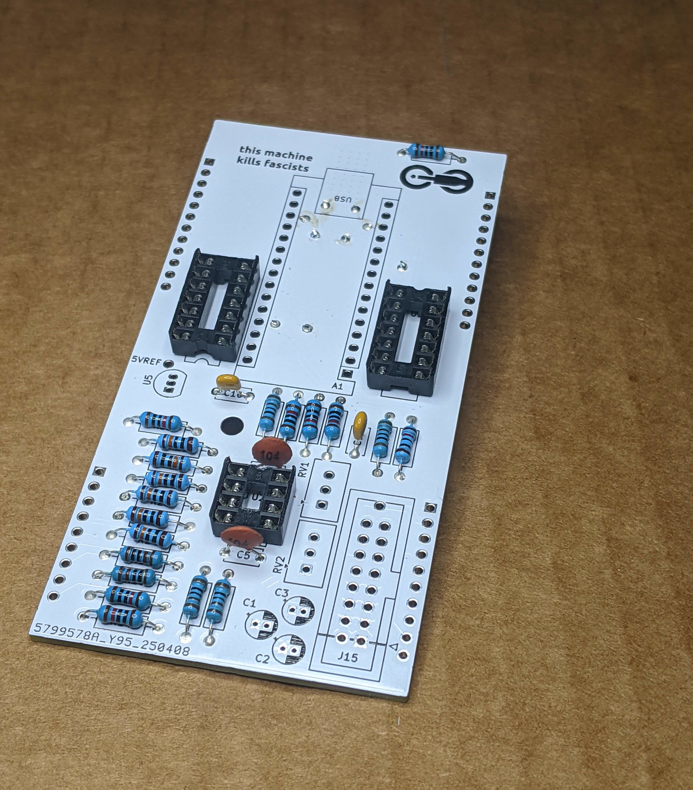
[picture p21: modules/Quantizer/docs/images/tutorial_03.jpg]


Add the IC sockets and small capacitors.

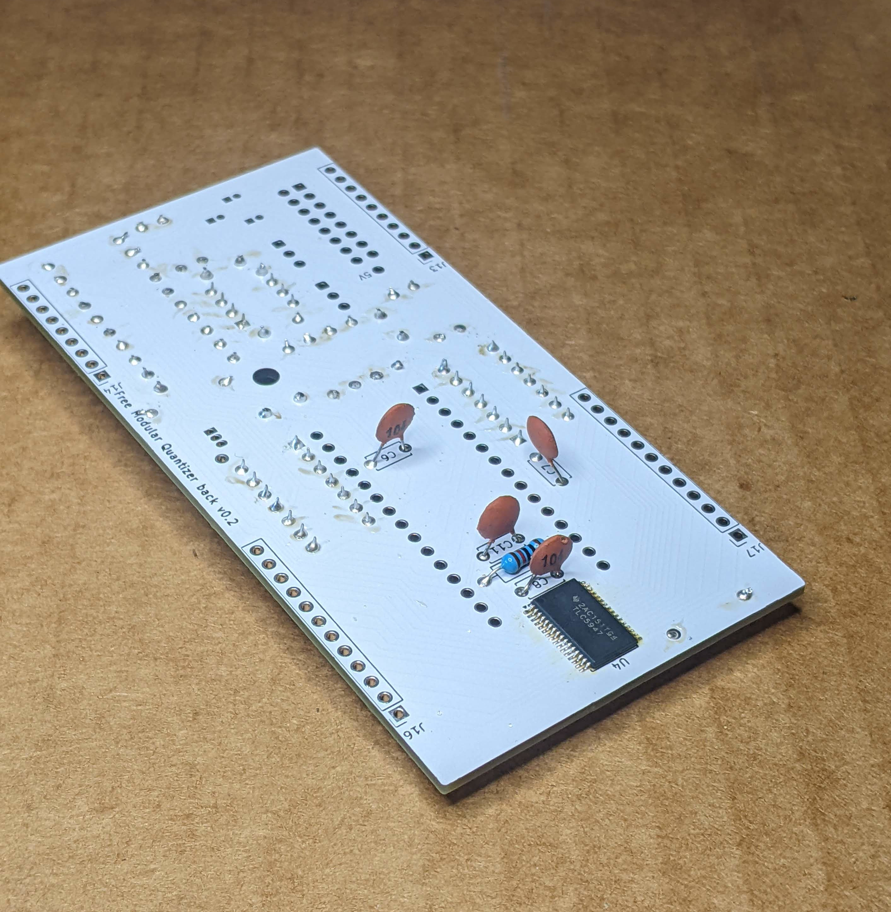
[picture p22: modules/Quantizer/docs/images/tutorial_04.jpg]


Flip the board over and add the resistor and capacitors on the back side.

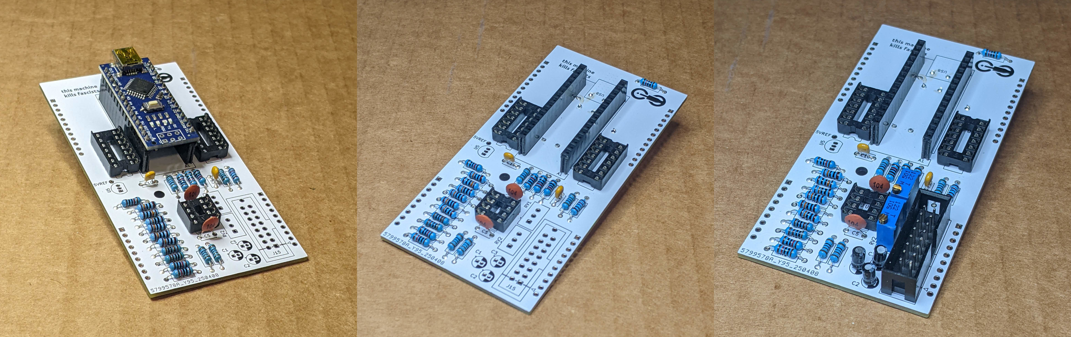
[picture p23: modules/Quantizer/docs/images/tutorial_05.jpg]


Attach the Arduino using female pin headers, then remove it to make it easier to add the power header and electrolytic capacitors. Optionally, you can add the two trim pots for tuning. If you don't want to bother with fine-tuning, just short all three holes for each trim pot together using a cut off leg of a resistor.

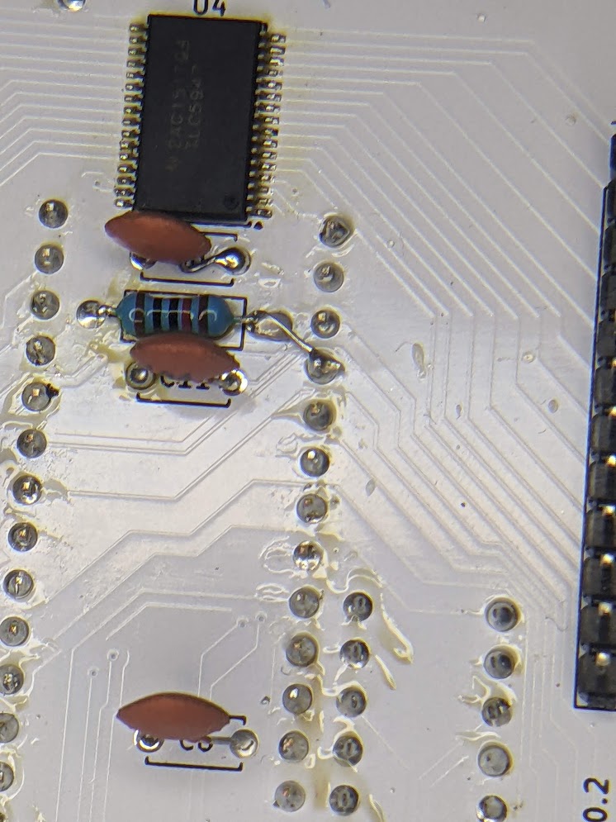
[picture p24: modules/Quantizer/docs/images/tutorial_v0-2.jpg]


If you have version `v0.2` of the rear PCB, you also need to bridge the right leg of R34 to the 4th pin down on the back of the Arduino, as shown. After the jumper is added, the left leg of R34 should be connected directly to +5V and the right leg should be connected to the A0 pin of the Arduino. Use a cutoff leg of one of the resistors and just hook it around R34 with a dab of solder. If you have version 1.0 of the PCB, you can ignore this step.

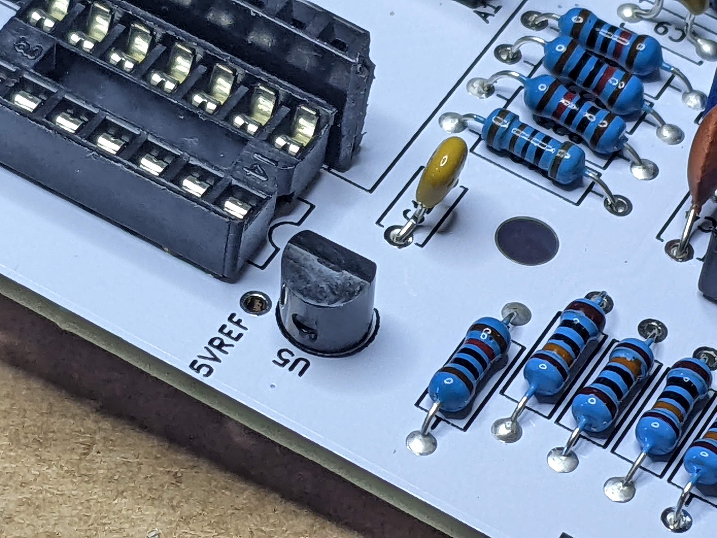
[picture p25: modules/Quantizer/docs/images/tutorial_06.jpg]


Optionally, add the 5V regulator. This is used as a precision reference voltage to make sure the output of the module is accurate. If you don't want to use it, you can just use the 5V power rail instead. Just connect the pad labelled "5V" to the one labelled "5VREF" using som insulated wire.

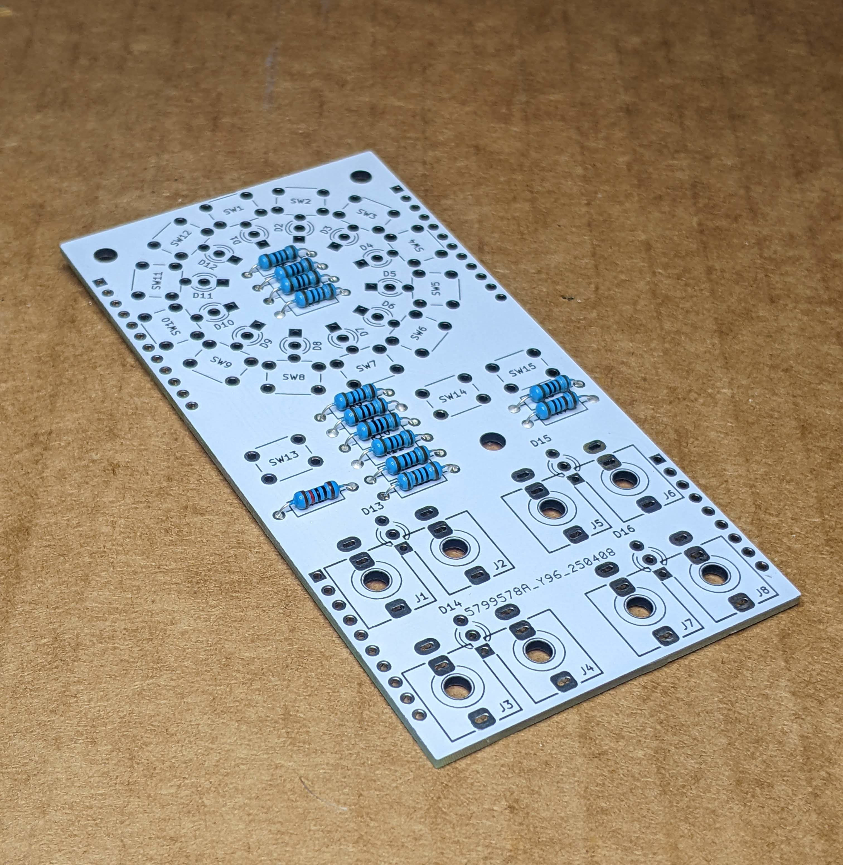
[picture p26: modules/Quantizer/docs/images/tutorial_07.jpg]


On the front PCB, add in the resistors just as on the rear board.

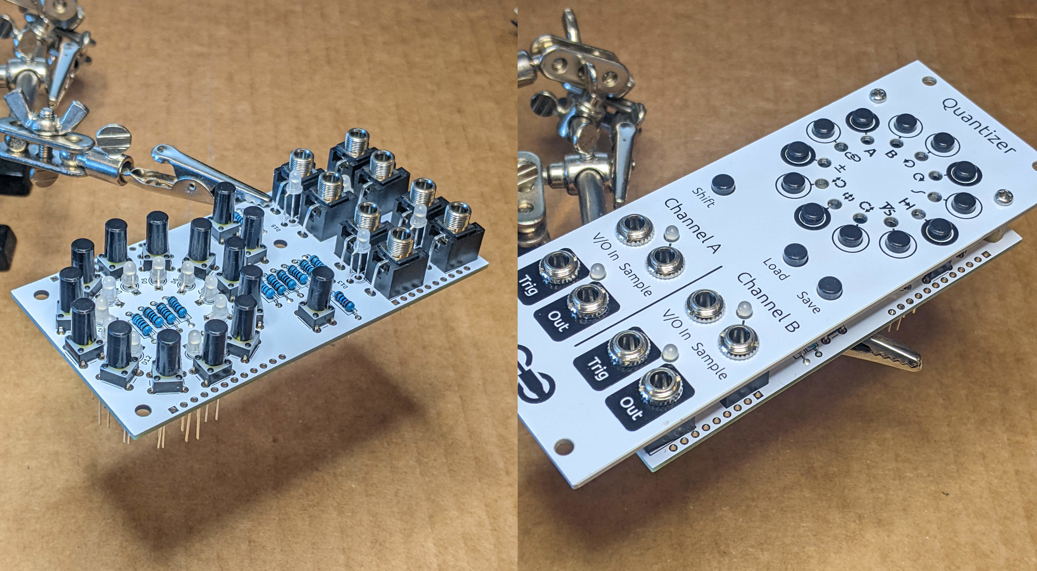
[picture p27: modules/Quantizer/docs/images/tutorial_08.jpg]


Put in all the interface components. Double-check the orientation of the LEDs. The red cathode goes in the square hole. The bulbs of the bottom LEDs will sit slightly on top of the jack sockets. Bolt down the faceplate using the 10-mm standoffs and tighten everything in place before soldering.

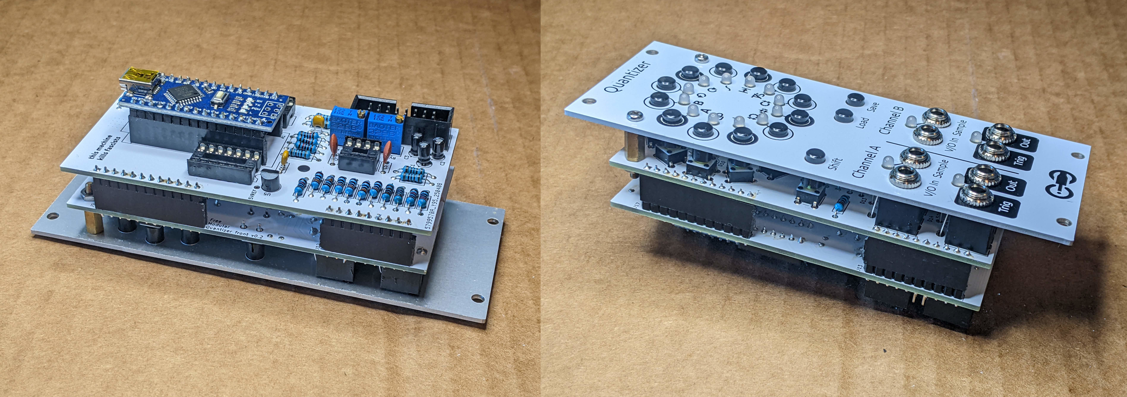
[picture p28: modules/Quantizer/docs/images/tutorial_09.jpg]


Solder the two boards together using pin headers. You can take the faceplate back off if it makes it easier to reach. Then put the ICs and the Arduino back in their sockets.

Lastly, [upload the firmware](https://freemodular.org/docs/assembly#firmware).

## Tuning

Tuning is probably not necessary since the oscillator you are driving with this module likely already has less precise tracking than the quantizer. But, if you want to fine-tune the output scale, you can use the trim pots on the back. Plug in the module and power it on. Enable the top note (C) and send a known integer voltage <10V into the V/O input of channel 1. 5V works well. It doesn't have to be exact, since the module will round it. Then hook up a multimeter in Volts DC mode to the output of channel 1. Use a screwdriver to adjust the top potentiometer on the back of the module until the reading is exactly 5V (or whatever voltage you are expecting). Then do the same with the other potentiometer for channel 2.

The trim potentiometers allow you to dial in the 1 Volt / octave rate. If you want to shift the whole scale up or down (i.e. set the "zero" note), just use the pre- and/or post-shift setting on each channel, or tune your oscillator.

## Troubleshooting

My LED's aren't working! What do I do?

When the module turns on with default configuration, the "Sample" LED's for both channels should be on.

- If ALL LED's are off, including the "Sample" and "Trig" LED's, then it is likely a problem with the Arduino firmware or with power delivery.
  1. Is the Arduino getting power? Check for the status LED's on the back of the Arduino board.
  2. Is the module getting power? Use a multimeter to probe the +5V, +12V, and -12V rails at the input.
  3. Is the correct firmware uploaded to the Arduino? Double check by re-flashing.
- If all 12 note LED's aren't working (but the other LEDs are working), it is probably an issue around the LED driver chip.
  1. With the module powered on, probe R30. It should have about 1.2V across it. If it has no voltage on either side, that's an indication that the TLC5947DAP LED driver is not powered on or working correctly.
  2. Check your PCB version. The version number will be printed on the back. If you have a pre-1.0 version, you will need to solder an extra jumper wire. See instructions above.
  3. If the LED driver is pulling current but not turning on any LED's, it is probably a problem with the signal on one of the bottom 8 pins of the driver. Because they are so small, they are easy to not connect properly. Refer to the PCB files and use a continuity meter make sure that the GND, +5V, BLANK/XLAT, and SDI pins are connected to where they should be.
- If just a few LEDs are not working (or are the wrong color) it is probably just an issue with the connections between the LED driver and the LED's themselves.
  1. The problem is probably at the LED driver side. The pins are small and can be difficult to get a solid solder joint with. Double-check all the solder joints.
  2. Using a continuity meter, check for continuity between the pins on the chip and the pin headers on the board. The top 12 pins on each side of the chip should connect to the top 12 pins on each side of the module. Check that neighboring pins are not shorted together.
  3. In a rare case, there could be a broken trace on the PCB. You could try bridging a broken trace with a bit of wire.

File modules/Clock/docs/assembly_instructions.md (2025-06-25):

# Clock Assembly Instructions

See [general assembly instructions](https://quinnfreedman.github.io/modular/docs/assembly)

## Components

**Most** parts are available on Tayda ([cart link](https://www.taydaelectronics.com/savecartpro/index/savenewquote/qid/82040858402), [quick-order CSV](https://freemodular.org/modules/Clock/fm_clock_tayda_bom.csv)).

See [general components notes](https://quinnfreedman.github.io/modular/docs/components) for more info about acquiring parts.

Interactive BOM: [front](https://quinnfreedman.github.io/fm-artifacts/Clock/clock_front_pcb_interactive_bom.html), [back](https://quinnfreedman.github.io/fm-artifacts/Clock/clock_back_pcb_interactive_bom.html)

| | Board | Reference | Part | Value | Source  | Comment |
| -- | ----- | --- | --- | --- | --- | --- |
| | Front | R1-R8 | Resistor | 1kΩ | [Tayda](https://www.taydaelectronics.com/10-x-resistor-1k-ohm-1-4w-1-metal-film-pkg-of-10.html) | Determines output impedance. Any value is fine. |
| | Front | R9-R16 | Resistor | 5kΩ-10kΩ | [Tayda](https://www.taydaelectronics.com/10-x-resistor-10k-ohm-1-4w-1-metal-film-pkg-of-10.html) | Determines LED brightness. You may want to use a different value if you have different LEDs. A lower value means less resistance and brighter LEDs |
| | Front | D1-D8 | LED | 3mm | [Tayda](https://www.taydaelectronics.com/36705-dup-led-3mm-blue-diffuse-lens.html) | Any standard 3mm LED will work here. |
| | Front | SW1 | Rotary Encoder | EC11 series | [Tayda](https://www.taydaelectronics.com/rotary-encoder-11mm-20-detents-d-shaft-with-switch-vertical.html), [Amazon](https://www.amazon.com/dp/B07D3DF8TK) | |
| 🔴 | Front | SW2 | Push button | D6R30 F1 LFS | [DigiKey](https://www.digikey.com/en/products/detail/c-k/D6R30-F1-LFS/1466331) | Make sure to line up the flat side of the button with the silkscreen on the PCB. This button could be replaced by a simple "6mm tactile switch" like [this](https://www.taydaelectronics.com/tact-switch-6-6mm-13mm-through-hole-spst-no.html) with a [cap](https://www.taydaelectronics.com/electromechanical/switches-key-pad/tact-switch/34189-dup-tactile-switch-caps-yellow-color.html) on it, but you may need to adjust the faceplate hole size. |
| 🔴 | Front | Screen | OLED display | SSD1306 SPI | [ebay](https://www.ebay.com/itm/373647815247) | The underlying display controller is the SSD1306. There are many ebay/amazon sellers that make modules based on it. Make sure to get one that uses the SPI protocol (6 or 7 total pins) instead of the I2C protocol (4 pins). The pins may be labelled differently or be in a different order on different modules. Just connect them to the corresponding holes on the PCB. The module also may or may not contain a 7th RESET pin. Either way should be fine. Different modules may also vary in the layout of their mounting holes. The faceplate is designed for a 23.5mmx24mm bolt pattern, which seems to be common, but it could be easily modified to fit a different screen. |
| | Front | J1-J8 | 3.5mm Jack | THONKICONN (a.k.a PJ398SM or PJ301M-12) | [Tayda](https://www.taydaelectronics.com/pj-3001f-3-5-mm-mono-phone-jack.html), [Thonk](https://www.thonk.co.uk/shop/thonkiconn/) | |
| | Front | J9-J11 | Pin headers | 1x4, 1x4, 1x11 | Tayda ([Male](https://www.taydaelectronics.com/40-pin-2-54-mm-single-row-pin-header-strip.html), [Female](https://www.taydaelectronics.com/40-pin-2-54-mm-single-row-female-pin-header.html)), [Amazon](https://www.amazon.com/gp/product/B074HVBTZ4) | Solder the two boards directly together using the male headers or make them detachable using a male/female pair. |
| | Back  | C1 | Capacitor | - | | **Optional** additional power supply noise filtering capacitor |
| | Back  | C2 | Capacitor | 10uF | [Tayda](https://www.taydaelectronics.com/10uf-16v-85c-radial-electrolytic-capacitor.html) | Power supply noise filtering capacitor |
| | Back  | A1 | Arduino Nano | v3.0 | [Tayda](https://www.taydaelectronics.com/type-c-nano-3-0-controller-compatible-with-arduino-nano.html), [ebay](https://www.ebay.com/itm/226078083873)| |
| | Back  | J9-J11 | Pin headers | 1x4, 1x4, 1x11 | | Match corresponding headers on front PCB |
| | Back  | J12 | IDC connector | 2x8 | [Tayda](https://www.taydaelectronics.com/2x8-pin-2-54-mm-double-row-pin-header-strip.html) | Eurorack power header. Can use two rows of male pin headers or a shrouded connector (recommended). |
| | Back  | J13 | - | - | | Not used. Expansion points for future features |
| 🔴 | Front | - | Mounting bolts | 2 M2x8mm, 2 M2x16mm, 6 nuts | [McMaster-Carr](https://www.mcmaster.com/products/screws/socket-head-screws~/system-of-measurement~metric/thread-size~m2/) | Used to attatch the screen to the faceplate. The two longer bolts can pass through to the PCB using additional nuts to hold everything together more firmly. |

🔴 = Missing from Tayda BOM

## Build Guide

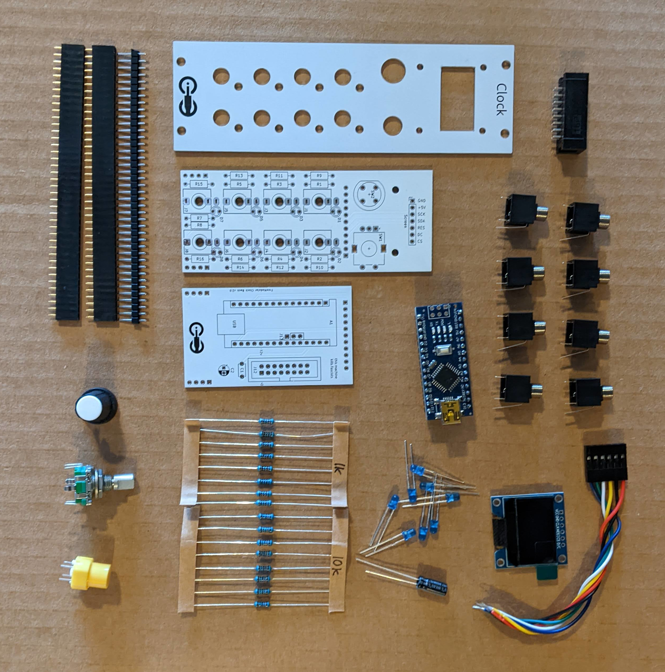
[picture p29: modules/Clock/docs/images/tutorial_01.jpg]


Once you have gathered all the components and the PCBs, I recommend starting with the resistors.

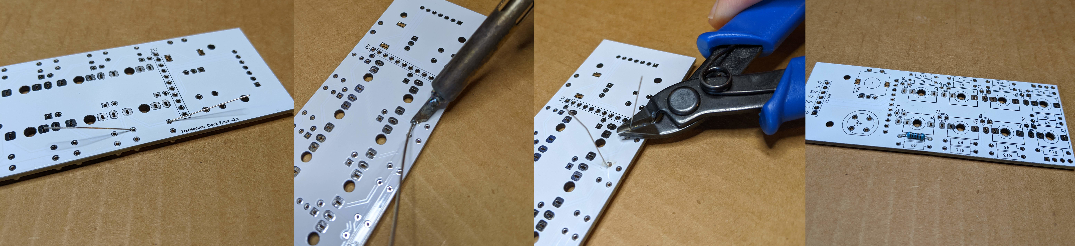
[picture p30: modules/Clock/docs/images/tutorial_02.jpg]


Bend the resistor legs back to hold them in place while you solder, then snip off the extra wire.

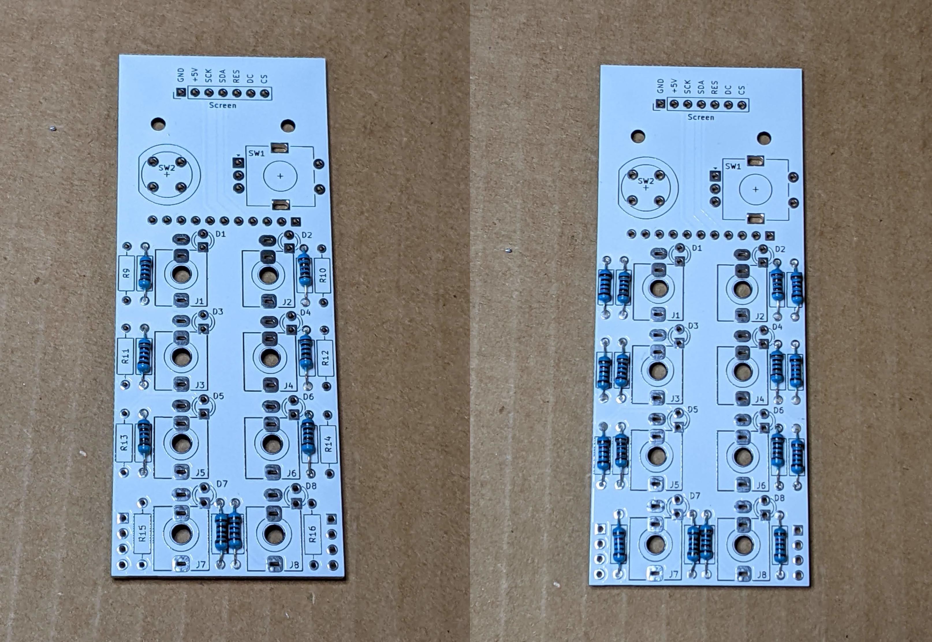
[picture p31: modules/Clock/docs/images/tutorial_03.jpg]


Repeat for all resistors. 



Cut the pin headers to length. Cut between the pins on the male headers but cut over the top of the pins on the female headers.

Stack the boards together and ballance them so that everything sits perpendicular. Solder the joints, then take the boards back apart.

If you prefer, you can solder the boards together permanently using only the male headers. If you do, save this to the very last step so you can still access the solder joints between the boards.

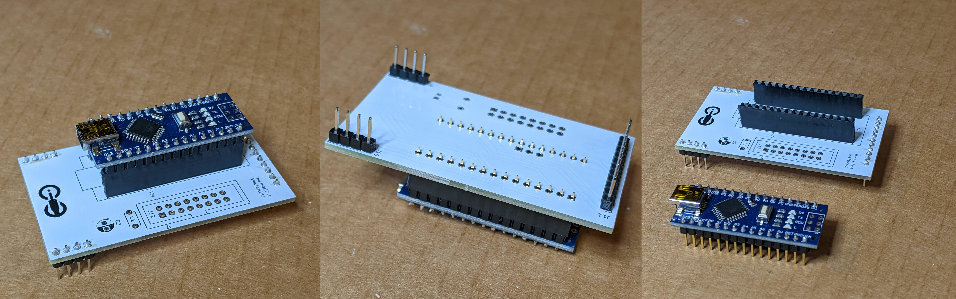
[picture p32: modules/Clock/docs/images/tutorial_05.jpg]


Repeat the same process for attaching the Arduino to the rear board.

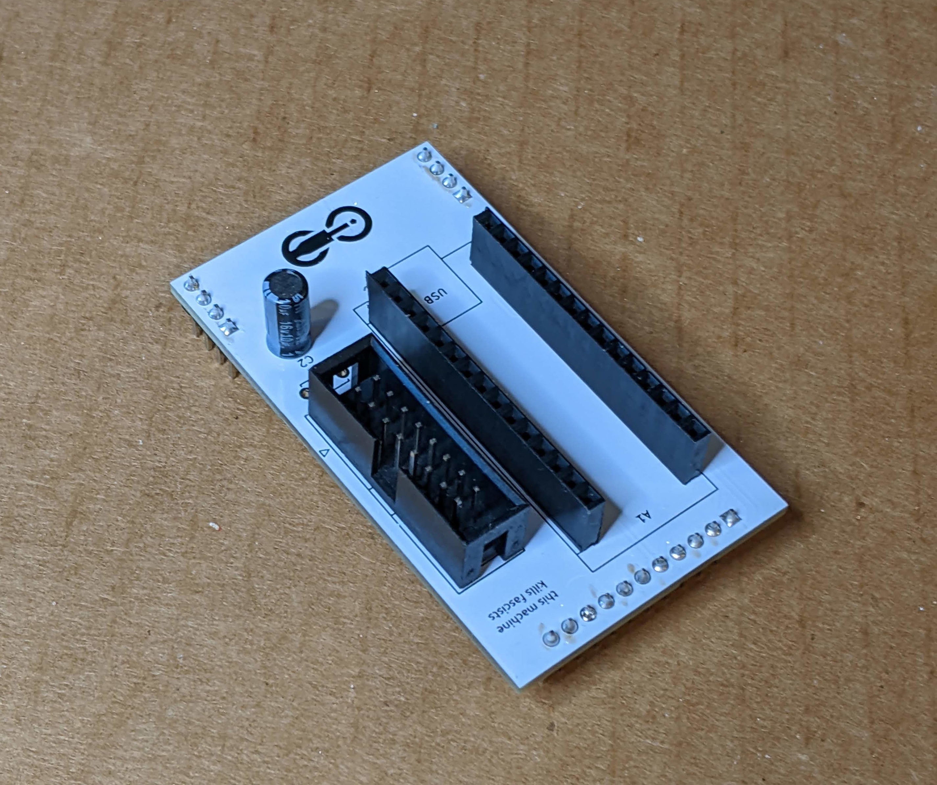
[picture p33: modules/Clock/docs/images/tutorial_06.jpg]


Attach the power header and capacitor to the rear board. Make sure to align the notch in the power header with the silkscreen. Looking from the back of the module, the notch should be on the right when the module is upright.

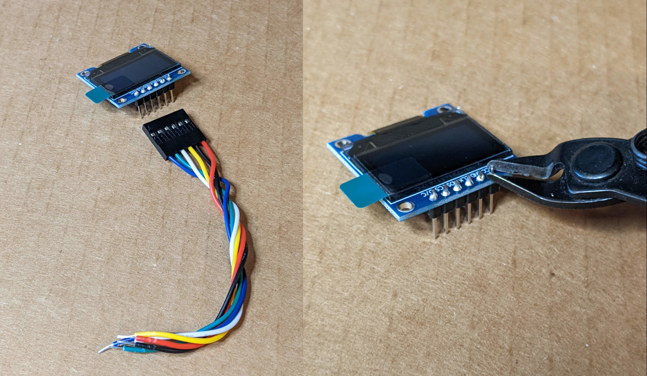
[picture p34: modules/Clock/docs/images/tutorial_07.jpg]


Attach the wires to the screen. If you want, you can use a DuPont connector or a JST XH-2.54 connector to make the screen detachable. Or just solder the wires straight to the screen.

Make sure to trim the tips extra flush so they don't short out against the faceplate when the screen is attached.

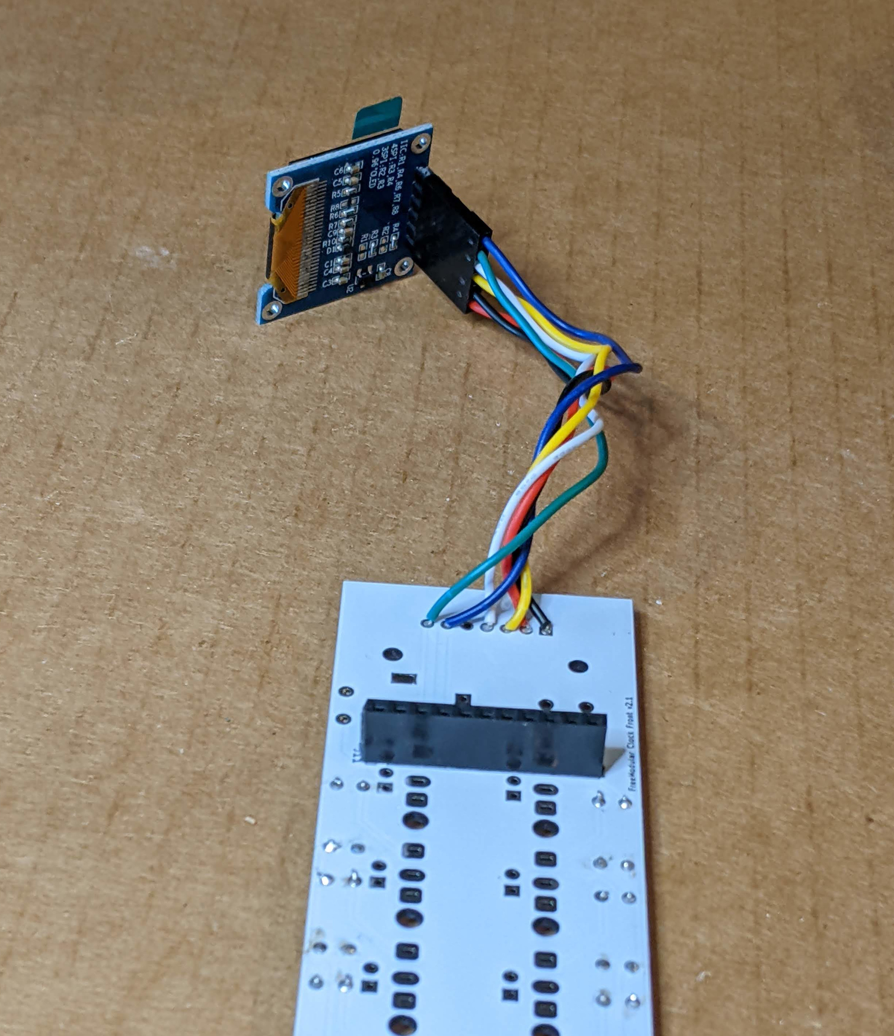
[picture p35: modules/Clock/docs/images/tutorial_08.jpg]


**Be careful connecting the screen to the PCB**. The pins on the screen may not be in the same order or labelled with the same names as they are on the PCB. This display uses the [SPI](https://en.wikipedia.org/wiki/Serial_Peripheral_Interface) protocol, which has very inconsistent naming conventions and every order of the display sub-module I get has a slightly different pinout or labels. There should be 6 (or 7) pins on the screen. Connect each one to the matching connection on the module PCB according to the following table:

| PCB marking | Other abbreviations | Function |
| --- | --- | --- |
| GND | 0V, Vss | ground |
| +5V | 5V, PWR, Vcc | power |
| SCK | CLK, SCLK, CK, SLK  | serial clock |
| SDA | MOSI, PICO, DATA | serial data |
| RES | RESET | reset (optional*) |
| DC | D/C, MODE, DATA | data/command toggle |
| CS | SS, /SS, /CS | chip select (optional*) |

\* The reset and/or CS pins may not exist on the screen sub-module. If not, just leave them unconnected. If they are present then you need to connect them.

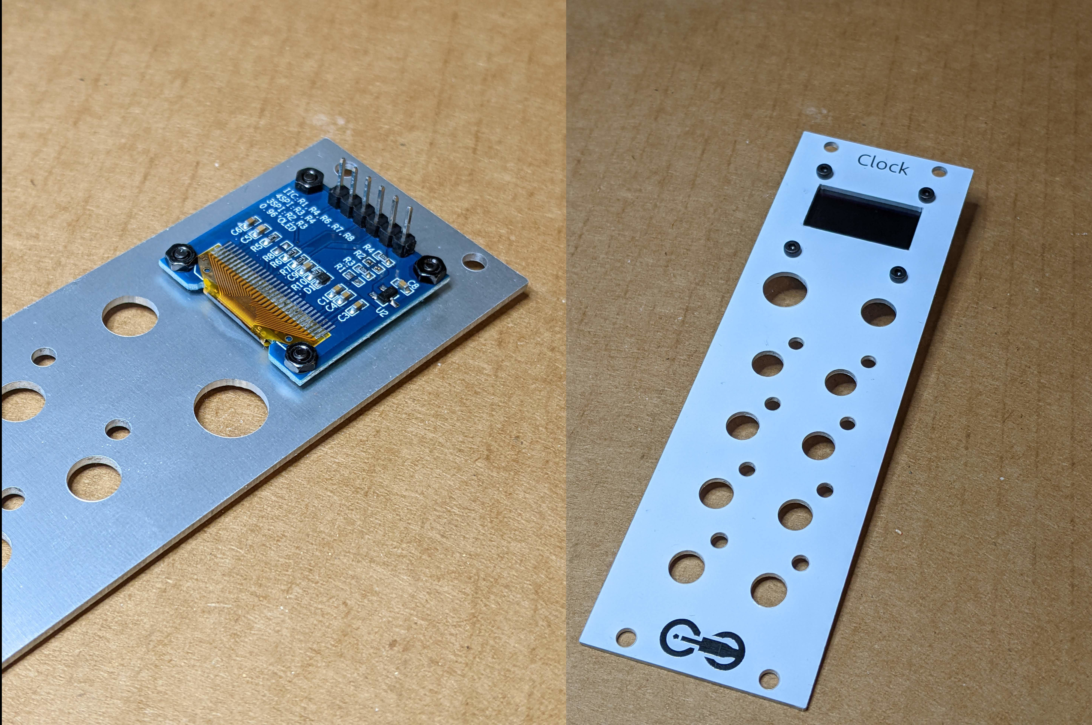
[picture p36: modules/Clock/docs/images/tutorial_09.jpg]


Attach the screen to the faceplate with M2 bolts. Don't tighten them enough to bend the PCB, just get them gently snug all around.

The connections should be at the top of the module.

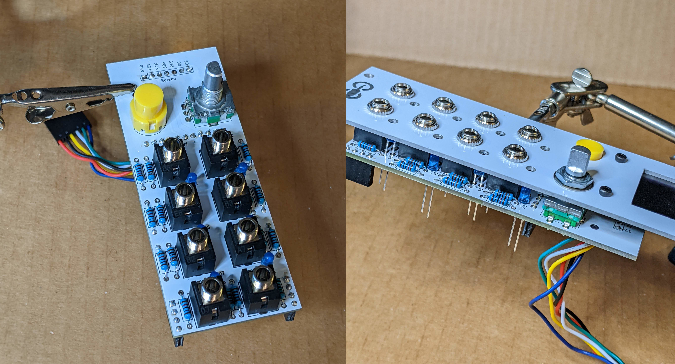
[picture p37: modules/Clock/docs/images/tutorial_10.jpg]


Place all the UI components in the PCB. Make sure to align the flat edge of the button with the silkscreen. The short leg of the LEDs should go in the square holes (toward the bottom of the module).

Add the faceplate before soldering to make sure everything is aligned properly. Screw the jack sockets down tightly. The rotary encoder will not have a surface to tighten the nut against, so don't screw it on tightly or it will pull the boards out of alignment.

Then flip the whole board over and solder. The button might fall out of place since it isn't attached. Make sure to hold it flush while you solder.

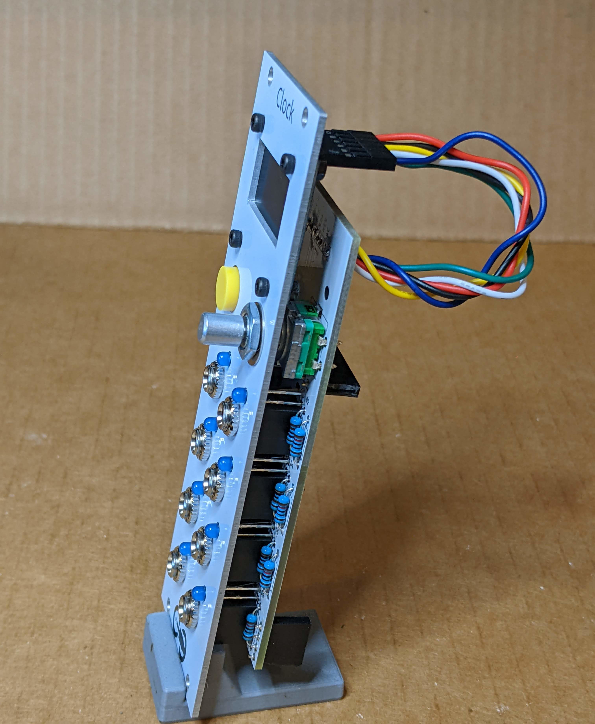
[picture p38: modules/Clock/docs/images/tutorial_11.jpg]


Push the LEDs through so they stick out the desired amount, then solder them too.

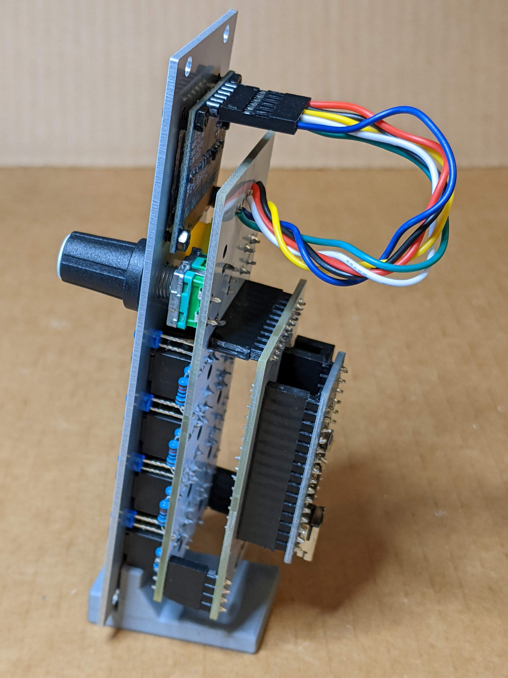
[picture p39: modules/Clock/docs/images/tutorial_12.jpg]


Put the two PCBs back together. Add the knob and the Arduino.

Then flash the bootloader and firmware onto the Arduino, if needed. See the [assembly instructions](https://freemodular.org/docs/assembly) for more details.

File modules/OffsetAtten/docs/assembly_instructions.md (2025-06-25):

# Offset/Atten Assembly Instructions

See [general assembly instructions](https://quinnfreedman.github.io/modular/docs/assembly)

## Components

All parts are available on Tayda ([cart link](https://www.taydaelectronics.com/savecartpro/index/savenewquote/qid/87940674120), [quick-order CSV](https://freemodular.org/modules/OffsetAtten/fm_oa_tayda_bom.csv)).

See [general components notes](https://quinnfreedman.github.io/modular/docs/components) for more info about acquiring parts.

Interactive BOM: [front](https://quinnfreedman.github.io/fm-artifacts/OffsetAtten/offset_atten_pcb_front_interactive_bom.html), [back](https://quinnfreedman.github.io/fm-artifacts/OffsetAtten/offset_atten_pcb_back_interactive_bom.html)

| Board | Reference | Part | Value | Source  | Comment |
| ----- | --- | --- | --- | --- | --- |
| Front | R1-R4 | Resistor | 33kΩ | [Tayda](https://www.taydaelectronics.com/resistors/1-4w-metal-film-resistors/resistor-33k-ohm-1-4w-1-metal-film-pkg-of-10.html) | Should be ~5/7 times the resistance of RV2 & RV4. |
| Front | RV1-RV4 | Potentiometer | B50kΩ | [Tayda](https://www.taydaelectronics.com/50k-ohm-linear-taper-potentiometer-d-shaft-pcb-9mm.html), [Thonk](https://www.thonk.co.uk/shop/alpha-9mm-pots-dshaft/) | Linear. Any value is fine, just adjust R1-R4 to match. |
| Front | J1-J4 | 3.5mm Jack | THONKICONN (a.k.a PJ398SM or PJ301M-12) | [Tayda](https://www.taydaelectronics.com/pj-3001f-3-5-mm-mono-phone-jack.html), [Thonk](https://www.thonk.co.uk/shop/thonkiconn/) | |
| Front | D1, D2 | LED | 3mm bipolar | [Tayda](https://www.taydaelectronics.com/leds/round-leds/3mm-leds/bi-color-led-3mm-red-green.html), [ebay](https://www.ebay.com/itm/133972966618) | This is a bipolar/bi-color LED. That means it is essentially two LEDs wired in opposite directions in the same package. Reversing the connection reverses the colors. When the module is outputting a positive voltage, the current will flow "forwards" through the LED, i.e. the square "cathode" hole towards the top of the module will be negative and the round "anode" hole towards the bottom of the module will be positive. When the module is outputting a negative voltage, the current will be reversed. The LEDs I bought were red in their "forward" direction and green in reverse, so I put them in backwards to get a green light for positive voltages. If you only have normal unipolar LEDs, just solder another led or any diode in reverse across the legs to protect the LED from the reverse current. |
| Back  | R5-R8, R11-R14 | Resistor | 100kΩ | [Tayda](https://www.taydaelectronics.com/10-x-resistor-100k-ohm-1-4w-1-metal-film-pkg-of-10.html) | Any value 10k-100k is probably fine as long as they all match. |
| Back  | R9, R16 | Resistor | 10kΩ | [Tayda](https://www.taydaelectronics.com/resistors/1-4w-metal-film-resistors/10-x-resistor-10k-ohm-1-4w-1-metal-film-pkg-of-10.html) | Determines LED brightness. Any value between 220Ω-10kΩ might be appropriate depending on which LEDs you have and how bright you want them. |
| Back  | R10, R15  | Resistor | 1kΩ | [Tayda](https://www.taydaelectronics.com/resistors/1-4w-metal-film-resistors/10-x-resistor-1k-ohm-1-4w-1-metal-film-pkg-of-10.html) | Determines output impedance |
| Back  | C1-C2 | Capacitor | 10uF | [Tayda](https://www.taydaelectronics.com/10uf-16v-85c-radial-electrolytic-capacitor.html) | Power supply noise filtering capacitors |
| Back  | C3-C6 | Capacitor | 100nF | [Tayda](https://www.taydaelectronics.com/a-553-0-1uf-50v-ceramic-disc-capacitor-pkg-of-10.html) | Power supply noise filtering capacitors |
| Back  | C7-C10 | Capacitor | 33pF | [Tayda](https://www.taydaelectronics.com/capacitors/ceramic-disc-capacitors/10-x-33pf-50v-ceramic-disc-capacitor-pkg-of-10.html) | Stabilizing cap for op-amps. Depending on the model of op-amps used, these probably aren't strictly necessary. Should be proportionally larger if using smaller resistors for R5-R8. |
| Back  | U1, U2 | Op-amp | LM324N | [Tayda](https://www.taydaelectronics.com/lm324n-lm324-324-low-power-quad-op-amp-ic.html), [DigiKey](https://www.digikey.com/en/products/detail/texas-instruments/LM324N/277627) | Any quad op-amp would probably work here, as long as it follows the standard pinout and can handle 24V power supply. A TL074 would work fine, but it can't handle rail-to-rail inputs, so it might give unexpected behavior if the input or output approaches 12V. To avoid this, use a rail-to-rail-capable op-amp like the LM324. |
| Both  | J5-J8 | Pin headers | 1x7, 1x8 | Tayda ([Male](https://www.taydaelectronics.com/40-pin-2-54-mm-single-row-pin-header-strip.html), [Female](https://www.taydaelectronics.com/40-pin-2-54-mm-single-row-female-pin-header.html)), [Amazon](https://www.amazon.com/gp/product/B074HVBTZ4) | Solder the two boards directly together using the male headers or make them detachable using a male/female pair. |
| Back  | J12 | IDC connector | 2x5 | [Tayda](https://www.taydaelectronics.com/10-pin-box-header-connector-2-54mm.html) | Eurorack power header. Can use two rows of male pin headers or a shrouded "box" connector (recommended). |
| Both  | - | Standoffs | 2 M3x11mm standoffs with screws and nuts | Tayda: [Offset](https://www.taydaelectronics.com/4844-dup-brass-standoff-spacer-screw-hex-male-m3x12mm-silver.html), [Nut](https://www.taydaelectronics.com/nut-3mm-for-screw-m3.html), [Screw](https://www.taydaelectronics.com/m3-steel-screw-cross-round-head-m3x6mm.html) | Holds the 2 PCBs together. Alternatively, use a long M3 bolt with some nuts on it. Obviously, if you are soldering the boards together the length would be different and could be omitted entirely. |

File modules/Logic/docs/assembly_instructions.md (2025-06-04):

# ALU Assembly Instructions

The ALU is mostly built designed with surface-mount components (it was the only wat to fit this circuit in such a small HP footprint). These parts are relatively large (0805-size or equivalent) so they are definitely possible to solder by hand. But, it is probably much more cost effective to just have the fabrication house making the PCBs also assemble them. The KiCad files have fields for JLC part numbers, so you can easily export the needed materials to have JLCPCB manufacture the whole board thing. But equivalent parts should be available at any fab service.

## Components

See [general components notes](https://quinnfreedman.github.io/modular/docs/components) for more info about sourcing parts.

Interactive BOM: [front](https://quinnfreedman.github.io/fm-artifacts/Logic/logic_pcb_front_interactive_bom.html), [back](https://quinnfreedman.github.io/fm-artifacts/Logic/logic_pcb_back_interactive_bom.html)

### Through-hole components

| Board | Reference | Part | Value | Source  | Comment |
| ----- | --- | --- | --- | --- | --- |
| Front | J1-J12 | 3.5mm Jack | THONKICONN (a.k.a PJ398SM or PJ301M-12) | [Tayda](https://www.taydaelectronics.com/pj-3001f-3-5-mm-mono-phone-jack.html), [Thonk](https://www.thonk.co.uk/shop/thonkiconn/) | |
| Both  | J14-J15, J16-J17 | Pin headers | 1x7, 1x6 | Tayda ([Male](https://www.taydaelectronics.com/40-pin-2-54-mm-single-row-pin-header-strip.html), [Female](https://www.taydaelectronics.com/40-pin-2-54-mm-single-row-female-pin-header.html)), [Amazon](https://www.amazon.com/gp/product/B074HVBTZ4) | Cut headers down to size. Solder the two boards directly together using the male headers or make them detachable using a male/female pair. |
| Back  | J13 | IDC connector | 2x8 | [Tayda](https://www.taydaelectronics.com/16-pin-box-header-connector-2-54mm.html) | Eurorack power header |

### Surface-mount components

| Board | Reference | Part | Value | Footprint | JLCPCB part number |
| ----- | --- | --- | --- | --- | --- |
| Back  | C1-C4 | Capacitor | 330pF | 0805 | C376974 |
| Back  | C8-C16 | Capacitor | 100nF | 0805 | C29926 |
| Back  | C5-C6 | Capacitor | 10uF | 4x5.4 | C3343 |
| Back  | R14, R17-R18, R27-R29 | Resistor | 1kΩ | 0805 | C17513 |
| Back  | R30 | Resistor | 3.3kΩ | 0805 | C26010 |
| Back  | R3-R5, R8 | Resistor | 5.1kΩ | 0805 | C27834 |
| Back  | R1-R2, R7-R7, R9-R13, R15, R19-R26 | Resistor | 10kΩ | 0805 | C17414 |
| Back  | R16 | Resistor | 100kΩ | 0805 | C57246 |
| Back  | D1-D3 | Diode | 1N4148 | SOD-123 | C5443965 |
| Back  | U1-U2 | NAND gates | CD74HCT132E | SOIC-14 | C484714 |
| Back  | U3-U4 | Op-amp | LM324 | SOIC-14 | C7943 |
| Back  | U6 | Voltage regulator | LM4040C50FTA | SOT-23 | C156291 |
| Back  | U5 | Op-amp | TL072 | SOP-8 | C5310783 |

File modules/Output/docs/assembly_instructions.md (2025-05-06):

# Output Assembly Instructions

See [general assembly instructions](https://quinnfreedman.github.io/modular/docs/assembly)

Note: this design has 3 PCBs that are stacked into a sandwich. The small one (top) and the one with the large jacks (middle) both face UP, with their components facing the faceplate (as indicated by the silkscreen). The last PCB (bottom) faces down, with most of the components mounted on the side facing away from the faceplate. All three are connected together with a single pair of headers at the top and a set of screws or offsets at the bottom.

## Components

**Most** parts are available on Tayda ([cart link](https://www.taydaelectronics.com/savecartpro/index/savenewquote/qid/50242216928), [quick-order CSV](https://freemodular.org/modules/Output/fm_output_tayda_bom.csv)).

See [general components notes](https://quinnfreedman.github.io/modular/docs/components) for more info about acquiring parts.

Interactive BOM: [front](https://quinnfreedman.github.io/fm-artifacts/Output/output_pcb_front_interactive_bom.html), [middle](https://quinnfreedman.github.io/fm-artifacts/Output/output_pcb_middle_interactive_bom.html), [back](https://quinnfreedman.github.io/fm-artifacts/Output/output_pcb_back_interactive_bom.html)

| | Board | Reference | Part | Value | Source  | Comment |
| -- | ----- | --- | --- | --- | --- | --- |
| | Front | R1, R2 | Resistor | 100kΩ | | |
| | Back  | R3, R11, R19, R20 | Resistor | 20kΩ | | Some of these resistors overlap the mounting holes. I recommend putting in the standoff first and then putting the resistors over/around the bolt head. |
| | Back  | R4-R6, R12-R14, R21-R26 | Resistor | 10kΩ | | See above |
| | Back  | R7-R10, R15-R18 | Resistor | 10Ω | | Adds output impedance to headphone output; protects against shorts when plugging in headphones. |
| | Back  | R27-R30 | Resistor | 100Ω | | Output impedance for line level output. |
| | Middle| R31, R32 | Resistor | 22kΩ | | Controls the decay of the peak detector display. A lower value will make the display follow the audio signal more closely. A higher value will show signal peaks for longer. 20kΩ is fine here. |
| | Middle| R33 | Resistor | 33kΩ | | R33-R38 provide the voltage reference for the volume meter. To get an accurate meter, they all must be the exact values given at 1% tolerance. But, if you don't have all the correct values, only the display will be effected; not the audio. Alternatively, if you want to use a different scale for the meters, you could use your own choice of values here. They are arranged as a voltage divider ladder from 12v to 0v. |
| | Middle| R34 | Resistor | 2.2kΩ | | |
| | Middle| R35 | Resistor | 1.5kΩ | | |
| | Middle| R36 | Resistor | 2.4kΩ | | |
| | Middle| R37 | Resistor | 820Ω | | |
| | Middle| R38 | Resistor | 470Ω | | |
| | Middle| R39-R48 | Resistor | 10kΩ | | Controls LED brightness for display. Higher values mean dimmer LEDs. Different color LEDs might have slightly different brightnesses, so you might want to experiment tuning these values to make all your LEDs uniform. |
| | Front | C1, C2 | Capacitor | 150nF | | Combines with R1-R2 to make a high-pass filter for the input. 100nF is fine here too. |
| | Back  | C3, C4 | Capacitor | 10uF | | Power supply noise filtering capacitors. |
| | Back  | C5-C14, C19-C24 | Capacitor | 100nF | | Power supply noise filtering/decoupling capacitors. |
| | Middle| C15-C16, C25-C28 | Capacitor | 100nF | | Power supply noise filtering/decoupling capacitors. |
| | Front | C17, C18 | Capacitor | 100nF | | Power supply noise filtering/decoupling capacitors. |
| | Back  | C29, C30 | Capacitor | 100pF | | Op-amp feedback stabilizers. |
| | Middle| C31, C32 | Capacitor | 10uF | | |
| | Back  | C23, C34 | Capacitor | 100pF | | Op-amp feedback stabilizers. |
| | Middle| D1, D2 | Diode | 1N4148 | [Tayda](https://www.taydaelectronics.com/1n4148-switching-signal-diode.html) | |
| | Middle| D3, D8 | LED | RED (3mm) | [Tayda](https://www.taydaelectronics.com/leds/round-leds/3mm-leds/led-3mm-red.html) | Must have long enough leads to reach from middle PCB to faceplate (1 inch). When not illuminated, these LEDs are exposed to 12v reverse current. Technically, this is outside the spec of most LEDs and could result in damage to the LED over time. If you are worried about this, you could look for LEDs with high reverse-voltage tolerance, or add a Zener diode or other high reverse voltage diode in series with one of the legs of each LED. But, after testing this design for a while with the cheapest Amazon LEDs, it seems like they were totally unaffected, so I wouldn't worry about it. |
| | Middle| D4, D9 | LED | AMBER (3mm) | [Tayda](https://www.taydaelectronics.com/leds/round-leds/3mm-leds/led-3mm-orange.html) | See above |
| | Middle| D5-D7, D10-D12 | LED | GREEN (3mm) | [Tayda](https://www.taydaelectronics.com/leds/round-leds/3mm-leds/led-3mm-green.html) | See above |
| | Front | J1, J2 | 3.5mm Jack | THONKICONN (a.k.a PJ398SM or PJ301M-12) | [Tayda](https://www.taydaelectronics.com/pj-3001f-3-5-mm-mono-phone-jack.html), [Thonk](https://www.thonk.co.uk/shop/thonkiconn/) | |
| 🔴 | Middle| J3-J5 | 1/4in Jack | ACJS-MN-3 | [Mouser](https://www.mouser.com/ProductDetail/Amphenol-Audio/ACJS-MN-3?qs=c9RBuMmXG6ItVexVLzhiSw%3D%3D), [Tayda](https://www.taydaelectronics.com/hardware/6-35mm-1-4-plugs-jacks/6-35mm-1-4-stereo-phone-jack.html)* | The current version of the PCBs are designed for [ACJS-series](https://www.mouser.com/ProductDetail/Amphenol-Audio/ACJS-MN-3?qs=c9RBuMmXG6ItVexVLzhiSw%3D%3D) jacks. Any of the ACJS-MN-3, ACJS-MN-3S, ACJS-MN-5, ACJS-MV-3, ACJS-MV-3S or ACJS-MV-5 will work. The [PJ-629HAN sold on Tayda](https://www.taydaelectronics.com/hardware/6-35mm-1-4-plugs-jacks/6-35mm-1-4-stereo-phone-jack.html) can work but it isn't an exact fit. The blades are wider so they would need to be snipped/filed in order to fit into the holes in the PCB. I believe the polarity is also reversed (so left and right channels on the headphones would be flipped). I plan to make a future revision updated to use the cheaper Tayda jacks. |
| | Back  | J6 | IDC connector | 2x5 | [Tayda](https://www.taydaelectronics.com/10-pin-box-header-connector-2-54mm.html) | Eurorack power header. Can use two rows of male pin headers or a shrouded connector (recommended). |
| | Back  | J7 | Unused | - | | Expansion connector for future modules. Exposes an AC-coupled and buffered but unscaled copy of the input signal. |
| 🔴 | All | J11-J23 | Stacking Pin Headers | 1x10 | [Tayda](https://www.taydaelectronics.com/stackable-header-10-pins-2-54mm.html), [Amazon (double-sided)](https://www.amazon.com/dp/B0B3XBYL3J), [Amazon (single-sided)](https://www.amazon.com/gp/product/B074HVBTZ4) | All 3 PCBs are connected by a single set of headers. There are a few ways to do this. You could use a stacking male/female header on the middle and use standard male/female headers on the top and bottom, use double-sided male headers on the middle and standard female on the top and bottom, or just use extra-long male headers and solder everything in place. The only thing that matters is that the offset between the front and middle PCBs is the right distance to align the large and small jacks. |
| 🔴 | Front | RV1, RV2 | Potentiometer | B50kΩ Dual gang | [Thonk](https://www.thonk.co.uk/shop/alpha-9mm-pots-dshaft/) | Linear, dual gang. Any value is fine. |
| | Front | U1 | Op-amp | TL072 | [Tayda](https://www.taydaelectronics.com/tl072-low-noise-j-fet-dual-op-amp-ic.html), [DigiKey](https://www.digikey.com/en/products/filter/instrumentation-op-amps-buffer-amps/687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) | |
| | Back  | U2, U7 | Op-amp | TL074 | [Tayda](https://www.taydaelectronics.com/tl074-quad-operational-amplifier-j-fet-pdip-14-tl074cn.html), [DigiKey](https://www.digikey.com/en/products/detail/texas-instruments/TL074BCN/378416) | |
| | Back  | U3-U6, U8-U9 | Op-amp | NE5532P | [Tayda](https://www.taydaelectronics.com/ne5532-5532-ic-dual-low-noise-op-amp.html), [Mouser](https://www.mouser.com/ProductDetail/595-NE5532P) | The NE5532P is a low-noise, high output-drive Op-amp, used here for driving the headphones and line outputs. The NE5532AP is an extra low-noise version, although it's probably not worth the cost. The SA5532 is identical except it has a higher temperature range, which isn't necessary. If you have a particular op-amp you prefer, you can use it here instead (as long as it follows the standard TL072-style pinout). A TL072 should work fine too, although it might not have the best distortion characteristics or lifespan depending on what load you are hooking it up to. U5 and U6 are connected in parallel for extra driving power and distortion resistance on the headphone output. You can just leave them out if you don't need the extra power. |
| | Middle| U10-U12 | Op-amp | TL074 | [Tayda](https://www.taydaelectronics.com/tl074-quad-operational-amplifier-j-fet-pdip-14-tl074cn.html), [DigiKey](https://www.digikey.com/en/products/detail/texas-instruments/TL074BCN/378416) | |
| 🔴 | Back/Middle | - | Standoffs | 2x M2.5x20mm bolts or 14mm M2.5 standoffs |  | Connect the two rear PCBs together. The exact spacing depends on what configuration of stacking pin headers you use. If you can't find standoffs of the exact right dimension, just use some M2.5 bolts and a few nuts to hold everything in place. |

🔴 = Missing from Tayda BoM

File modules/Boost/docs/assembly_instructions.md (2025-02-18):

# Boost Assembly Instructions

## Components

Parts are available on Tayda ([cart link](https://www.taydaelectronics.com/savecartpro/index/savenewquote/qid/19841852897), [quick-order CSV](https://freemodular.org/modules/Boost/fm_boost_tayda_bom.csv)).

See [general components notes](https://quinnfreedman.github.io/modular/docs/components) for more info about acquiring parts.

[Interactive BOM](https://quinnfreedman.github.io/fm-artifacts/Boost/boost_pcb_interactive_bom.html)

| Reference | Part | Value | Source  | Comment |
| --- | --- | --- | --- | --- |
| R1, R4 | Resistor | 10kΩ | [Tayda](https://www.taydaelectronics.com/resistors/1-4w-metal-film-resistors/10-x-resistor-10k-ohm-1-4w-1-metal-film-pkg-of-10.html) | R4 controls the current flowing through the clipping diodes. Using a different value would give a slightly different tone, especially if you want to use different diodes.  |
| R2 | Resistor | 24kΩ | [Tayda](https://www.taydaelectronics.com/resistors/1-4w-metal-film-resistors/10-x-resistor-24k-ohm-1-4w-1-metal-film-pkg-of-10.html) | Should be 1/2 the resistance of RV1. If you want more gain, you can make it smaller, but you may encounter op-amp clipping. |
| R3 | Resistor | 2.4kΩ | [Tayda](https://www.taydaelectronics.com/resistors/1-4w-metal-film-resistors/resistor-2-4k-ohm-1-4w-1-metal-film-pkg-of-10.html) | Should be 1/10x R2. |
| R5 | Resistor | 2kΩ | [Tayda](https://www.taydaelectronics.com/resistors/1-4w-metal-film-resistors/resistor-2k-ohm-1-4w-1-metal-film-pkg-of-10.html) | |
| R6 | Resistor | 18kΩ | [Tayda](https://www.taydaelectronics.com/resistors/1-4w-metal-film-resistors/resistor-18k-ohm-1-4w-1-metal-film-pkg-of-10.html) | |
| R7 | Resistor | 750kΩ | [Tayda](https://www.taydaelectronics.com/resistors/1-4w-metal-film-resistors/resistor-750k-ohm-1-4w-1-metal-film-pkg-of-10.html) | |
| R8 | Resistor | 560kΩ | [Tayda](https://www.taydaelectronics.com/resistors/1-4w-metal-film-resistors/resistor-560k-ohm-1-4w-1-metal-film-pkg-of-10.html) | |
| R9 | Resistor | 15kΩ | [Tayda](https://www.taydaelectronics.com/resistors/1-4w-metal-film-resistors/resistor-750k-ohm-1-4w-1-metal-film-pkg-of-10.html) | This resistor sets the cutoff frequency for the high-shelf filter which determines which frequencies are boosted/cut by the Tone knob. Feel free to adjust the value or swap it out for a trim pot to dial it in by ear. Just don't turn it all the way down to a short. |
| R10, R11  | Resistor | 100kΩ | [Tayda](https://www.taydaelectronics.com/resistors/1-4w-metal-film-resistors/10-x-resistor-100k-ohm-1-4w-1-metal-film-pkg-of-10.html) | |
| R12 | Resistor | 1kΩ | [Tayda](https://www.taydaelectronics.com/resistors/1-4w-metal-film-resistors/10-x-resistor-1k-ohm-1-4w-1-metal-film-pkg-of-10.html) | |
| RV1, RV2  | Potentiometer | B50kΩ | [Tayda](https://www.taydaelectronics.com/potentiometer-variable-resistors/rotary-potentiometer/50k-ohm-linear-taper-potentiometer-d-shaft-pcb-9mm.html) | You can use another value if you have it available. Any value is fine for RV1 as long as you adjust R2 and R3 relative to RV1. Any value for RV2 is probably fine, but it might slightly change the response curve. Lower is probably better. I chose linear pots, but you could use an exponential pot for RV1 if you prefer, since it is setting an audio gain. |
| J1 | IDC connector | 2x6 | [Tayda](https://www.taydaelectronics.com/10-pin-box-header-connector-2-54mm.html) | Eurorack power header. Can use two rows of male pin headers or a shrouded connector (recommended). |
| J2, J3 | 3.5mm Jack | THONKICONN (a.k.a PJ398SM or PJ301M-12) | [Tayda](https://www.taydaelectronics.com/pj-3001f-3-5-mm-mono-phone-jack.html) | |
| D1, D2 | Diode | 1N4148 | [Tayda](https://www.taydaelectronics.com/1n4148-switching-signal-diode.html) | You can use any diodes or LEDs here. Different diodes will have different response curves and will sound different. You may want to adjust R4 and/or the gain amount of the gain stages (see schematic) to get the diode in its non-linear operating range. You will probably also want to need to adjust the post-clipping gain to get the signal back to Eurorack levels. |
| Q1 | Transistor | 2N3904 | [Tayda](https://www.taydaelectronics.com/2n3904-npn-general-propose-transistor.html) | |
| C1 | Capacitor | 470nF | [Tayda](https://www.taydaelectronics.com/capacitors/monolithic-ceramic-capacitor/0-47-uf-50v-multilayer-monolithic-ceramic-capacitor-multicomp.html) | This provides the AC coupling for the input stage. Replacing this with a short circuit will add a slight DC offset before clipping and allow you to add more by biasing the input, which will enable asymmetric clipping and maybe a richer, more interesting sound. But it may play less well with outboard gear or unipolar signals. |
| C2 | Capacitor | 10nF | [Tayda](https://www.taydaelectronics.com/capacitors/ceramic-disc-capacitors/10-x-0-01uf-50v-ceramic-disc-capacitor-pkg-of-10.html) | |
| C3 | Capacitor | 33pF | [Tayda](https://www.taydaelectronics.com/capacitors/ceramic-disc-capacitors/10-x-33pf-50v-ceramic-disc-capacitor-pkg-of-10.html) | |
| C4, C5 | Capacitor | 100nF | [Tayda](https://www.taydaelectronics.com/capacitors/ceramic-disc-capacitors/a-553-0-1uf-50v-ceramic-disc-capacitor-pkg-of-10.html) | |
| C6-C7 | Capacitor | 10uF | [Tayda](https://www.taydaelectronics.com/10uf-16v-85c-radial-electrolytic-capacitor.html) | **Optional.** Power supply noise filtering capacitors |
| U1 | Op-amp | TL074 | [Tayda](https://www.taydaelectronics.com/tl074-quad-operational-amplifier-j-fet-pdip-14-tl074cn.html) | When the boost is turned all the way up and the tone control is also boosting high frequencies, you can get some op-amp clipping on this module. The TL074 doesn't clip the way you might expect -- it will give a very harsh asymmetrical wave-wrapping effect when the voltage is pushed high enough. You could replace this with any rail-to-rail capable op-amp, but I chose to keep the TL074 because I like having a super harsh sound when you turn it all the way up. The cheaper TL084 would probably also be fine here. |

## Build Guide

See [general assembly instructions](https://quinnfreedman.github.io/modular/docs/assembly)

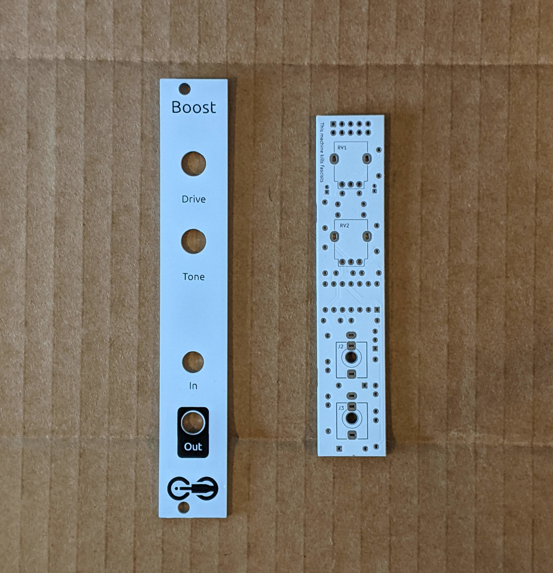
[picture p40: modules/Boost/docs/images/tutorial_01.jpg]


This module only has one PCB. It should be a very fast build.

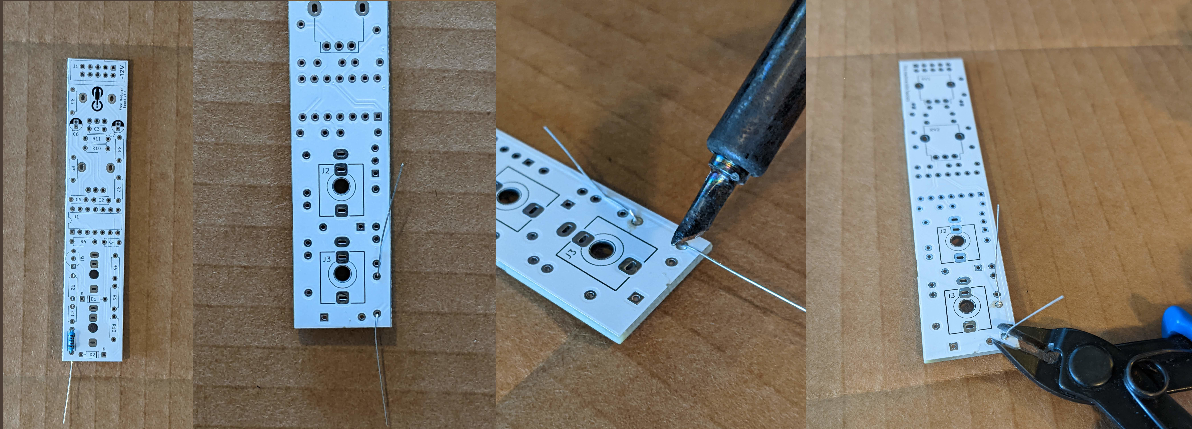
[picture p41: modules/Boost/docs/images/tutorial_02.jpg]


Start with the resistors. Bend the resistor legs back to hold them in place while you solder, then snip off the extra wire.

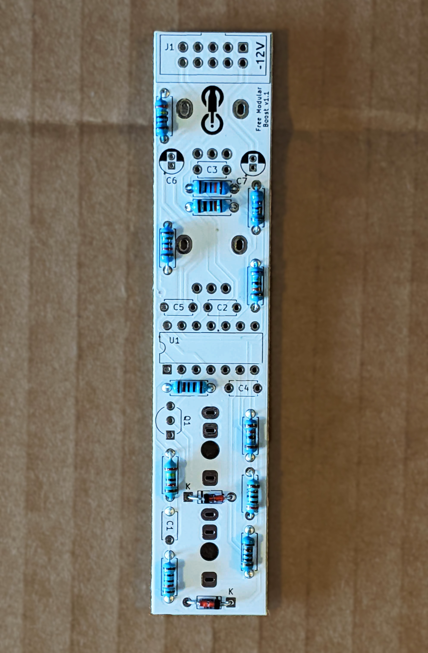
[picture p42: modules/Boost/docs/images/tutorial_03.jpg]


Repeat for all resistors. See bill of materials or the [interactive BOM](https://quinnfreedman.github.io/fm-artifacts/Boost/boost_pcb_interactive_bom.html) for which resistor goes where.

Add the diodes as well. The black line on the diode should align with the hole labelled "k".

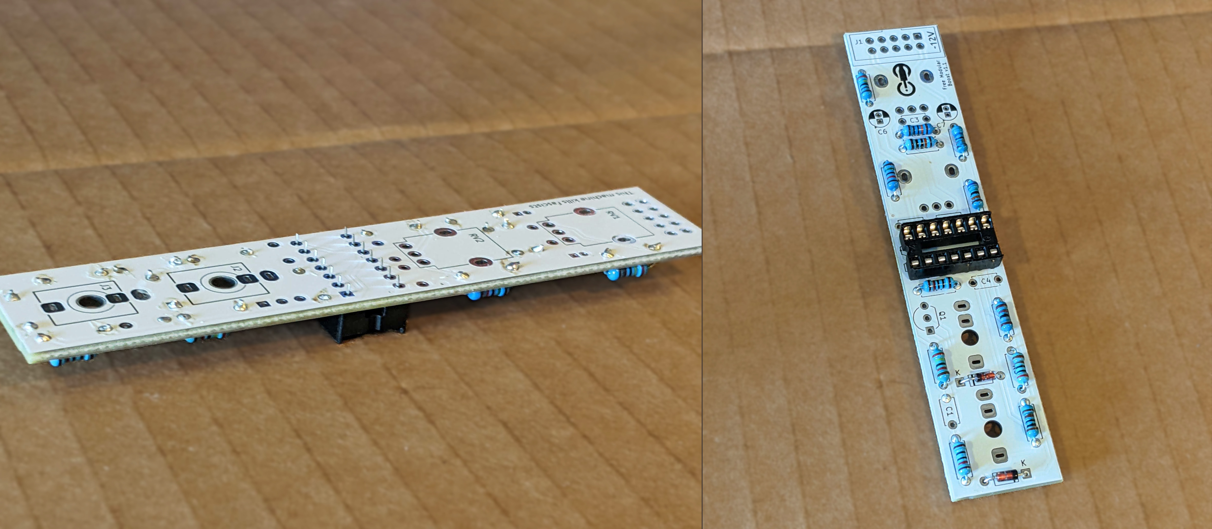
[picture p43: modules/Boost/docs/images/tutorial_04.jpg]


Add IC socket. Flip the board over and ballance it on the socket, then solder. If you don't have a socket, you can solder the chip directly to the board instead.

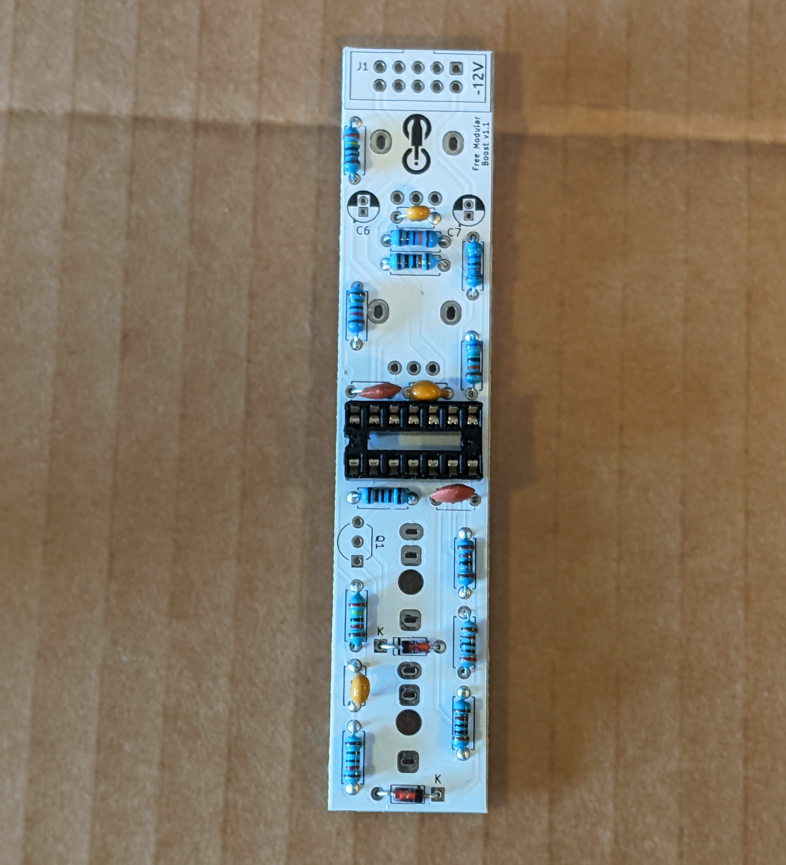
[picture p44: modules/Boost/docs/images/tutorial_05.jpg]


Add all the ceramic capacitors in the same way as the resistors.

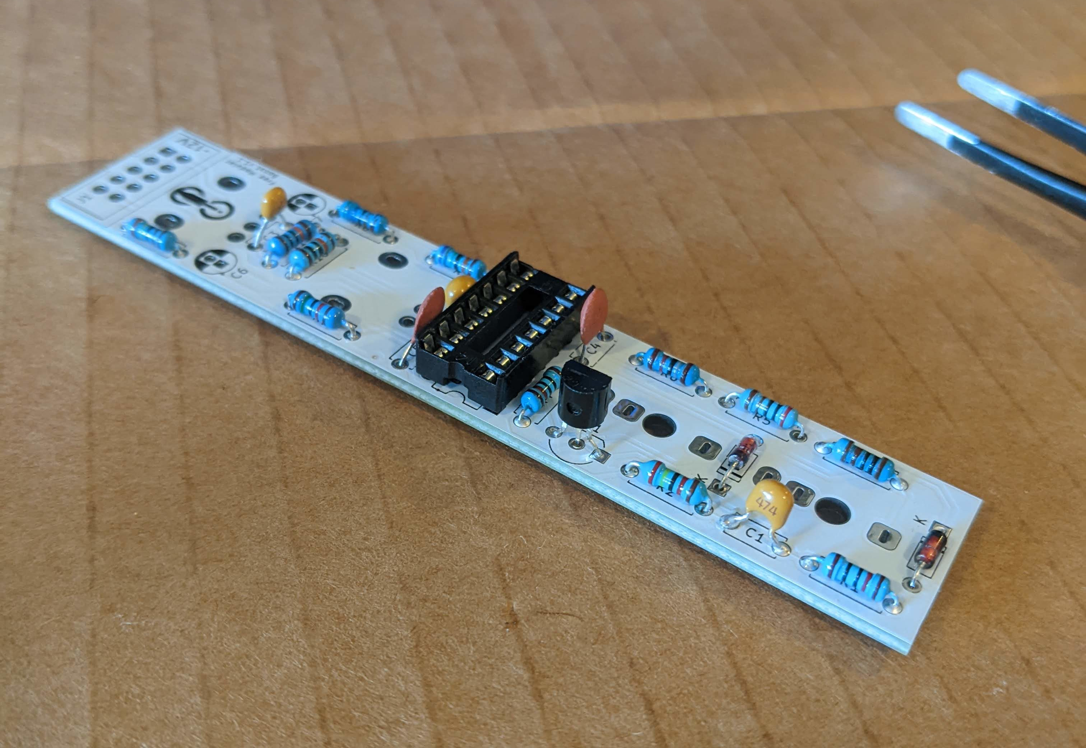
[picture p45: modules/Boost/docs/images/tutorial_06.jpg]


Add transistor. If you don't care about having a high-impedance input, you can omit the transistor. Instead, use a cutoff leg from one of the resistors to bridge pins 1 and 2 (the square pad and the middle hole). If you do, leave off R1 as well.

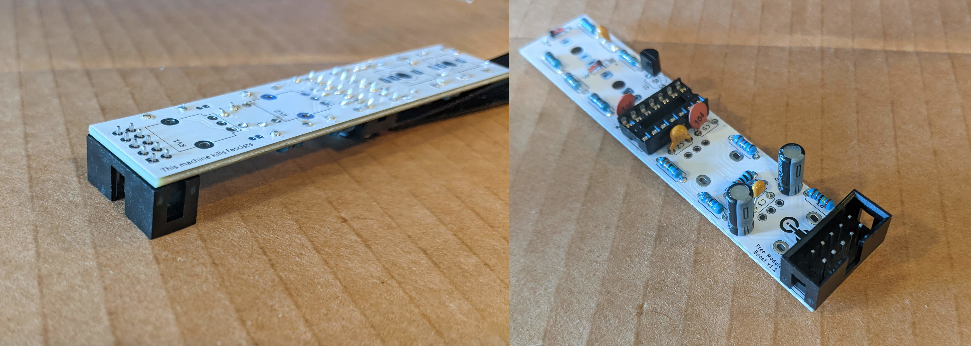
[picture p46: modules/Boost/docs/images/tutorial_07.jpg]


Add power header. Flip the board over and support the opposite end so it lays flat, then solder in the header. Add the large capacitors in the same way.

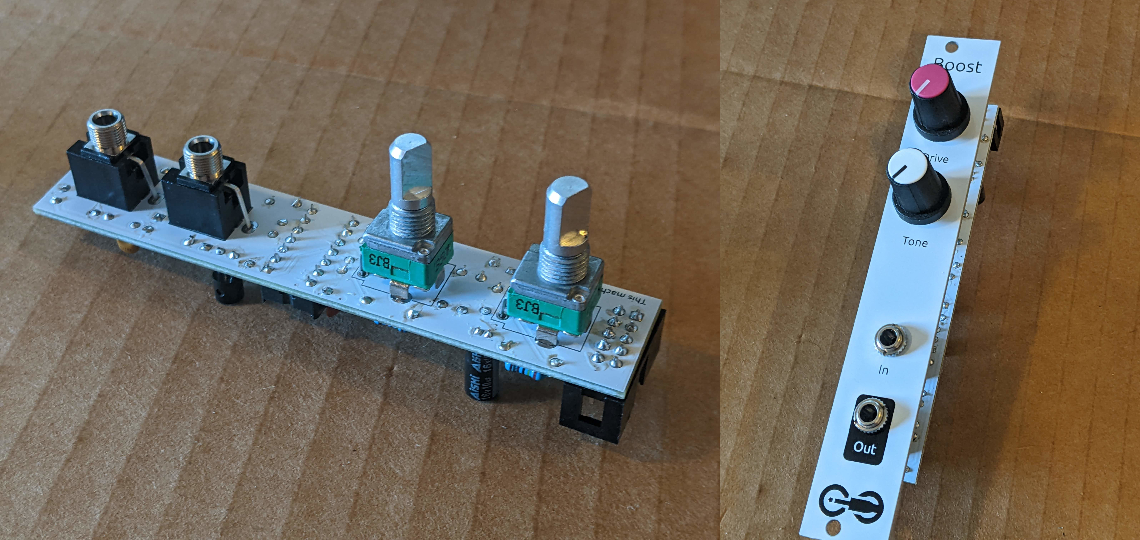
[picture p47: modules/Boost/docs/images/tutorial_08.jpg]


Add the jack sockets and potentiometers. Screw them tightly into the faceplate and make sure everything lines up squarely before soldering.

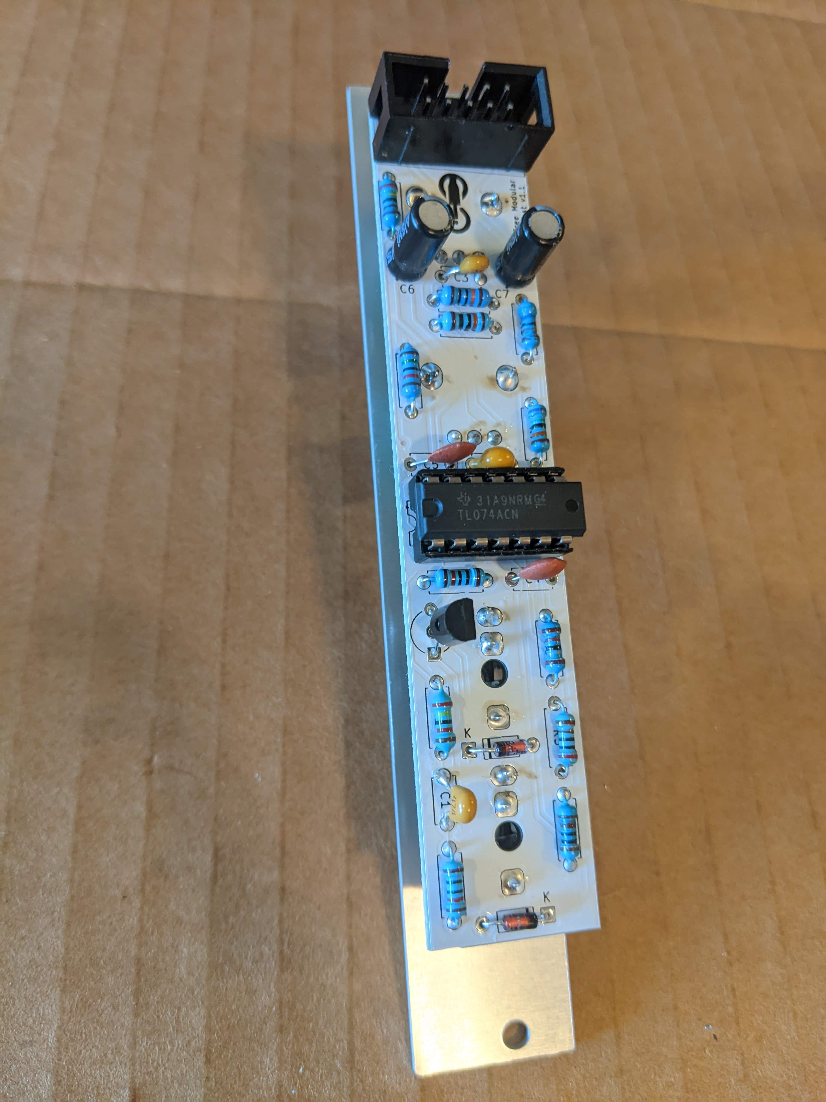
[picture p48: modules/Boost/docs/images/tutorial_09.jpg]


Lastly, put the op-amp IC into its socket. You may need to straighten the legs a little first to get it to fit. Make sure it is seated firmly.

Optionally, use a multimeter in continuity mode to check for short circuits. Probe the power connector and confirm that there is no continuity between +12V and GND, -12V and GND, or +12V and -12V.

Then you're good to go! Plug it into your rack and start boosting!

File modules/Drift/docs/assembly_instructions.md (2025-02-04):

# Drift Assembly Instructions

## Components

**Most** parts are available on Tayda ([quick-order CSV](https://freemodular.org/modules/Drift/fm_drift_tayda_bom.csv)).

See [general components notes](https://quinnfreedman.github.io/modular/docs/components) for more info about acquiring parts.

Interactive BOM: [front](https://quinnfreedman.github.io/fm-artifacts/Drift/drift_pcb_front_interactive_bom.html), [back](https://quinnfreedman.github.io/fm-artifacts/Drift/drift_pcb_back_interactive_bom.html)

| | Board | Reference | Part | Value | Source  | Comment |
| -- | ----- | --- | --- | --- | --- | --- |
| | Back  | R1 | Resistor | 1kΩ | [Tayda](https://www.taydaelectronics.com/10-x-resistor-1k-ohm-1-4w-1-metal-film-pkg-of-10.html) | Determines output impedance. Any value is fine. |
| | Back  | R2-R4 | Resistor | 24kΩ | [Tayda](https://www.taydaelectronics.com/resistors/1-4w-metal-film-resistors/10-x-resistor-24k-ohm-1-4w-1-metal-film-pkg-of-10.html) | R4 should be 1/2 RV3. |
| | Back  | R5 | Resistor | 1kΩ | | Controls LED brightness. |
| | Back  | R6, R7 | Resistor | 100kΩ | [Tayda](https://www.taydaelectronics.com/resistors/1-4w-metal-film-resistors/10-x-resistor-100k-ohm-1-4w-1-metal-film-pkg-of-10.html) | |
| | Back  | C1-C4 | Capacitor | 100nF | [Tayda](https://www.taydaelectronics.com/capacitors/ceramic-disc-capacitors/a-553-0-1uf-50v-ceramic-disc-capacitor-pkg-of-10.html) | Power filtering and decoupling |
| | Back  | C5-C7 | Capacitor | 10uF | [Tayda](https://www.taydaelectronics.com/10uf-16v-85c-radial-electrolytic-capacitor.html) | Power supply noise filtering capacitor |
| | Back  | C8 | Capacitor | 4.7nF | [Tayda](https://www.taydaelectronics.com/capacitors/ceramic-disc-capacitors/a-553-0-1uf-50v-ceramic-disc-capacitor-pkg-of-10.html) | **Optional:** This capacitor creates a 1.25kHz lowpass filter with R3 which is applied to the output to smooth out the relatively slow digital sample rate of this module. You can try different values for a smoother signal or leave this out entirely if you don't mind some high-frequency artifacts. |
| | Front | D1 | LED | 5mm diffuse orange | [Tayda](https://www.taydaelectronics.com/leds/round-leds/5mm-leds/led-5mm-yellow.html) | Any standard 5mm LED will work here. |
| | Front | J1-J3 | 3.5mm Jack | THONKICONN (a.k.a PJ398SM or PJ301M-12) | [Tayda](https://www.taydaelectronics.com/pj-3001f-3-5-mm-mono-phone-jack.html) | |
| | Both  | J4-J7 | Pin headers | 1x4, 1x6 | Tayda ([Male](https://www.taydaelectronics.com/40-pin-2-54-mm-single-row-pin-header-strip.html), [Female](https://www.taydaelectronics.com/40-pin-2-54-mm-single-row-female-pin-header.html)), [Amazon](https://www.amazon.com/gp/product/B074HVBTZ4) | Solder the two boards directly together using the male headers or make them detachable using a male/female pair. |
| 🔴 | Both  | - | Mounting screw | M2 | [McMaster-Carr](https://www.mcmaster.com/products/screws/socket-head-screws~/system-of-measurement~metric/thread-size~m2/) | **Optional:** add an M2 screw or standoff to hold the two PCBs firmly together. |
| | Back  | J9 | IDC connector | 2x8 | [Tayda](https://www.taydaelectronics.com/16-pin-box-header-connector-2-54mm.html) | Eurorack power header. Can use two rows of male pin headers or a shrouded connector (recommended). |
| | Front | RV1-RV3 | Potentiometer | B50kΩ | [Tayda](https://www.taydaelectronics.com/potentiometer-variable-resistors/rotary-potentiometer/linear/50k-ohm-linear-taper-potentiometer-d-shaft-pcb-9mm.html) | Any value is fine. Just match R4 accordingly. |
| | Back  | A1 | Arduino Nano | v3.0 | [Tayda](https://www.taydaelectronics.com/type-c-nano-3-0-controller-compatible-with-arduino-nano.html) | |
| 🔴 | Back  | U1 | DAC | MCP4922-E/P | [DigiKey](https://www.digikey.com/en/products/detail/microchip-technology/MCP4922-E-P/716251), [Mouser](https://mou.sr/4cwtePf) | |
| | Back  | U2 | Op-amp | TL072 | [Tayda](https://www.taydaelectronics.com/tl072-low-noise-j-fet-dual-op-amp-ic.html) | TL082 is probably fine too |
| | Back  | U3 | Op-amp | MCP6002 | [Tayda](https://www.taydaelectronics.com/mcp6002-single-supply-cmos-ic.html), [Mouser](https://mou.sr/4cwtePf) | |
| | Back  | SW1 | DIP switches | 1x2 | [Tayda](https://www.taydaelectronics.com/black-dip-switch-2-positions-gold-plated-contacts-top-actuated.html) | **Optional:** configuration switches to select noise algorithm. Leave unconnected for the default Perlin noise. You can solder a wire to bridge pairs 1 and/or 2 to select a different mode, or use pair of switches if you want to be able to change it later. See the manual for how to select algorithms. |

🔴 = Missing from Tayda BOM

## Build Guide

Once you have gathered all the components and the PCBs, I reccomend you start with the resistors on the rear PCB.

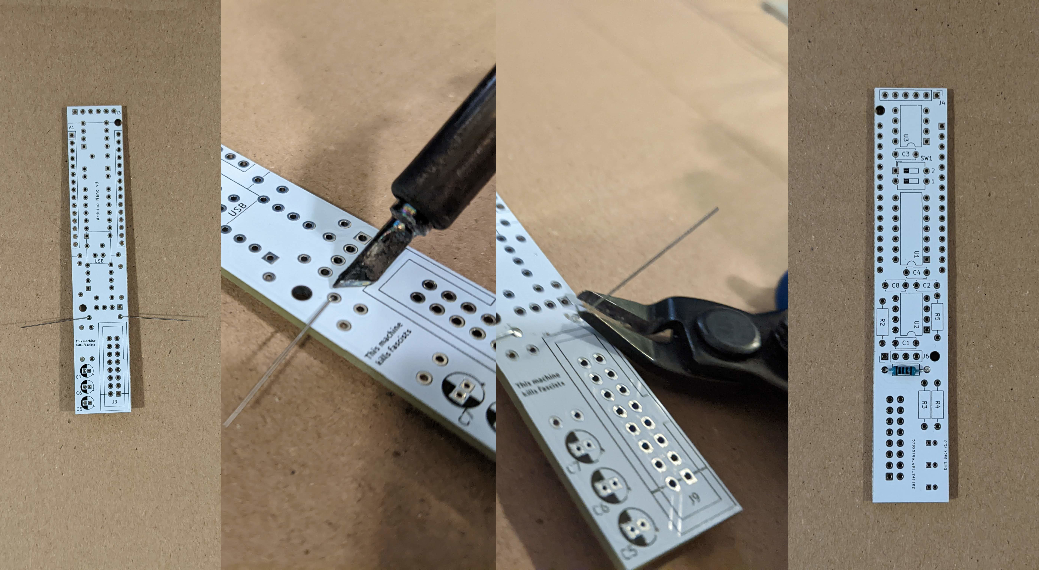
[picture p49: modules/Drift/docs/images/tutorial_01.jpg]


Bend the resistor legs back to hold them in place while you solder, then snip off the extra wire. Repeat for all resistors. 

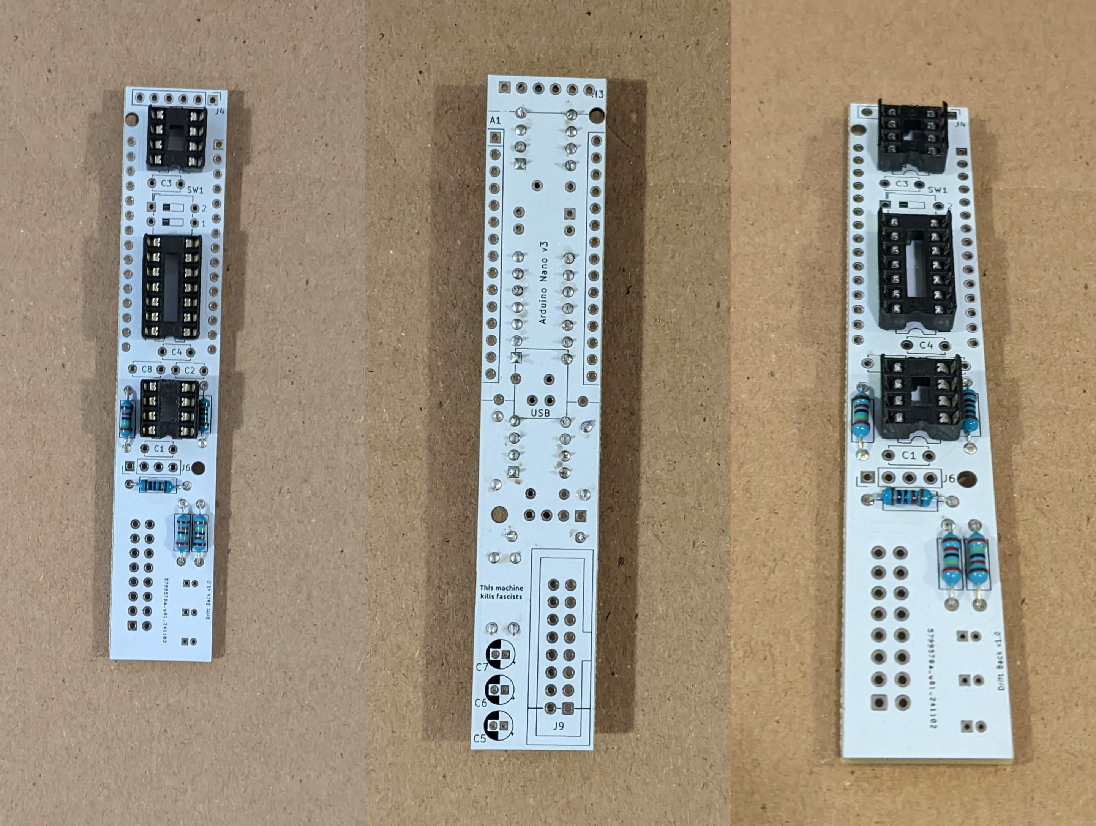
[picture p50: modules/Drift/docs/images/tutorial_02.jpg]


Next, add the sockets for the IC chips. If you don't have sockets, you can solder the chips directly to the PCB, but then you won't be able to move or swap them later if there is an error.

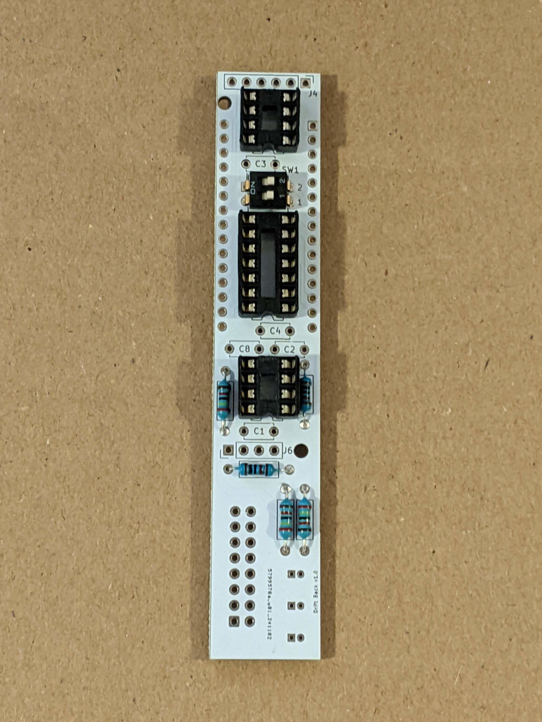
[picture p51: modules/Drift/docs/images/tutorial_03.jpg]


Optionally, add the DIP switch to be able to select differnt modes.

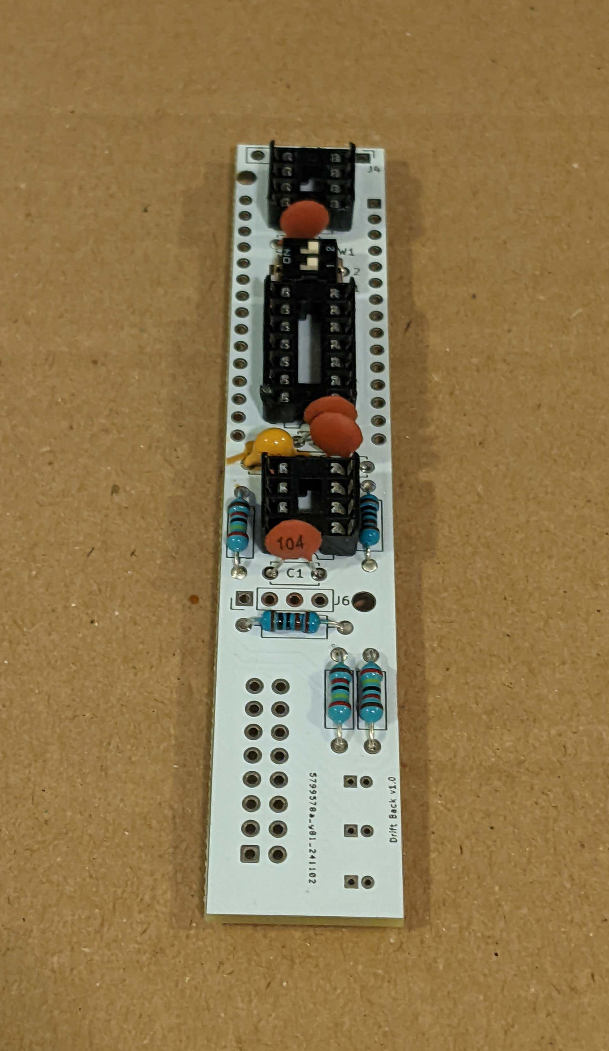
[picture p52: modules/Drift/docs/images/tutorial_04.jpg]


Add the ceramic capacitors in the same way as the resistors.

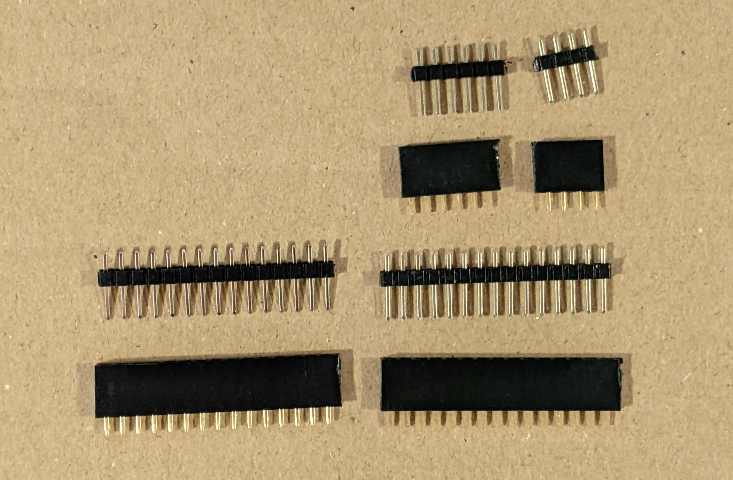
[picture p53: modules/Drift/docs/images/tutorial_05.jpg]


Cut the pin headers to size. There should be one strip of 4 pins, one of 6 pins, and two of 15 pins. Each strip should have a male and female side. You can put the male and female parts together now.

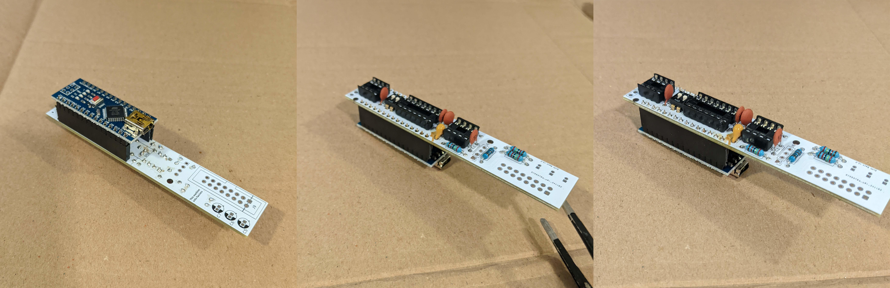
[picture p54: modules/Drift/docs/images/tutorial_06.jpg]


Add the Arduino to the opposite side of the rear PCB. Start by ballancing the Arduino on the pin headers to solder the Arduino side. Then, flip the whole thing over and solder the PCB side. You may need to support the PCB so everything will sit flush. After everything is soldered, you can remove the Arduino to make the next steps easier.

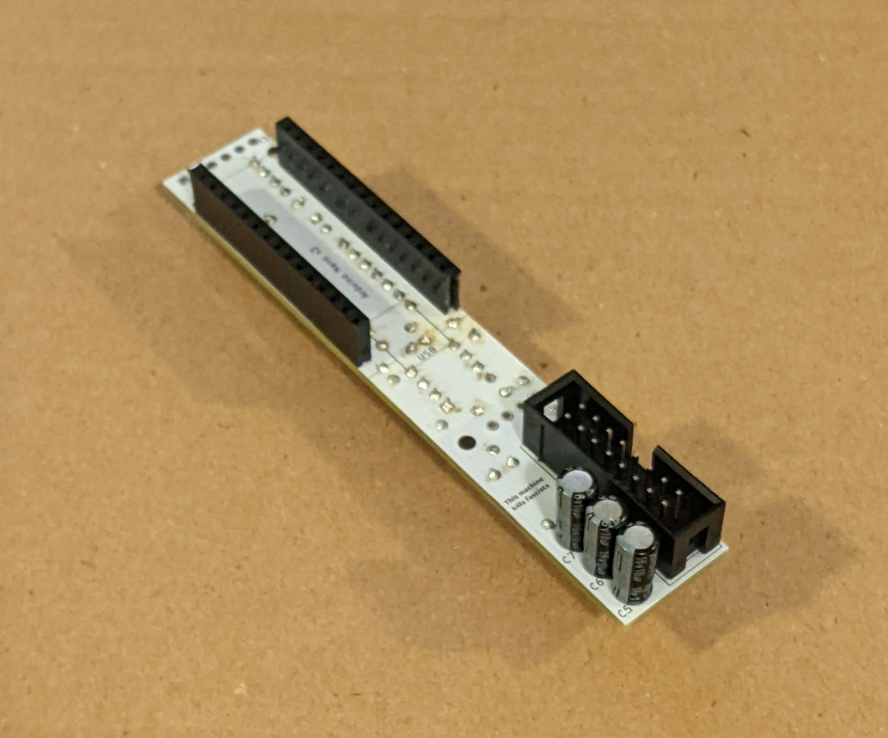
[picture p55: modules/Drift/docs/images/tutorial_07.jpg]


Add the power header and the electrolytic capacitors to the same side as the Arduino. Match the notch on the power header to the notch on the PCB silkscreen. The notch should face right with -12v at the bottom.

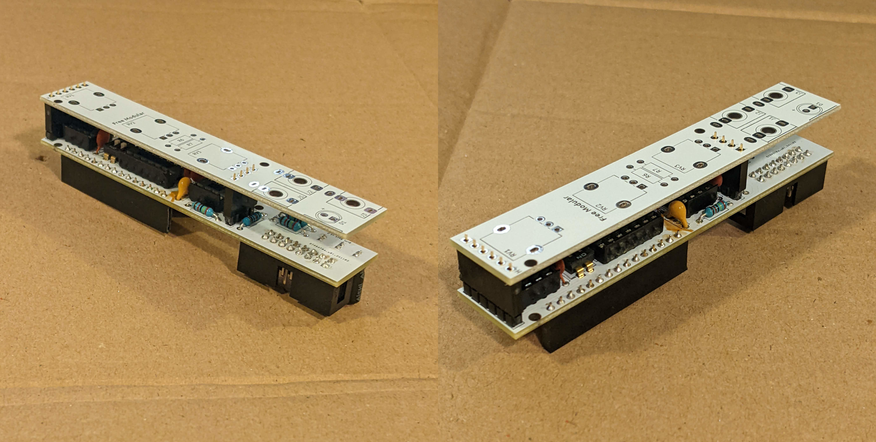
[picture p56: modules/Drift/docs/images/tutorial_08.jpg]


Put the two PCB boards together using the remaining two sets of pin headers. The ICs should be facing inward with the Arduino and the power header exposed on the back.

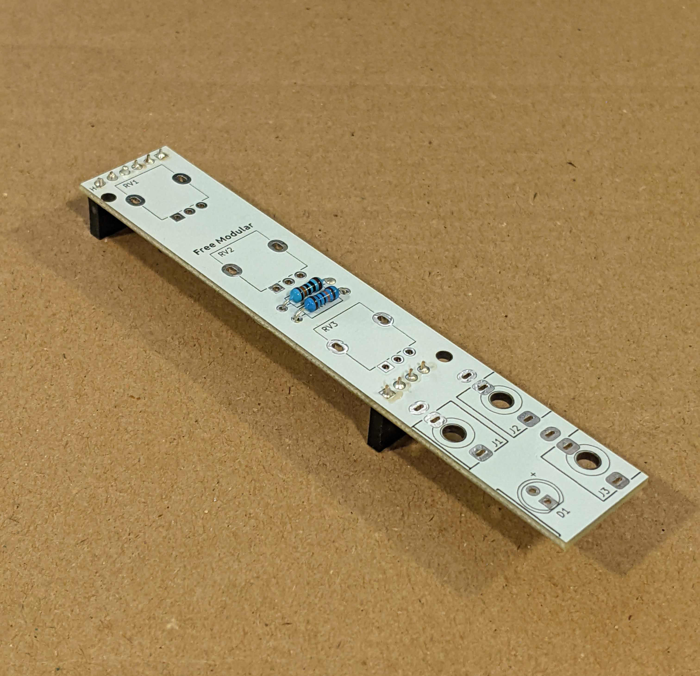
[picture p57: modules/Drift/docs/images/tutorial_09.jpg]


After the headers are soldered in place, you can separate them to work on the front PCB. Start by adding the resistors.

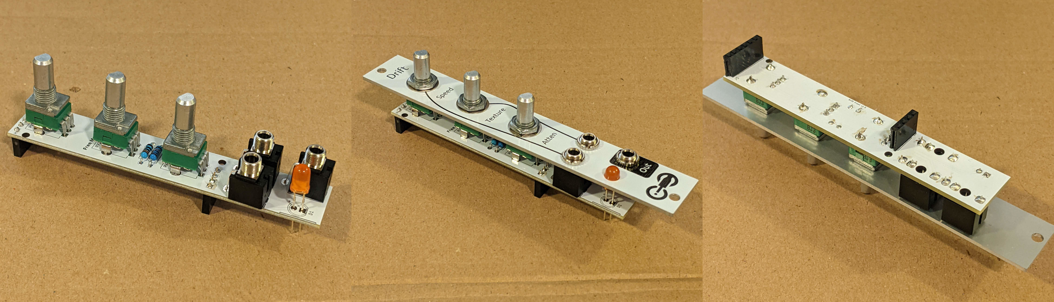
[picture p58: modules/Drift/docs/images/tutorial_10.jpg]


Add all the through-hole components. Before you solder them, screw everything tightly into the faceplate to make sure everything lines up. Make sure the long leg of the LED goes in the hole marked with the + sign and make sure the LED bulb is protruding the amount you want from the faceplate. Then flip the whole thing over and solder everything.



Put the IC chips in their sockets. You may need to straighten the legs a little bit to make them fit, then press hard till they are firmly seated.



Then put the two boards back together and fasten them with the M2 bolts.



Lastly, put the Arduino back in its socket and put the knobs on the potentiometers.

You might want to use a multimeter to check for short circuits between any of the power rails and ground. It's especially easy to make accidental solder bridges on the electrolytic capacitors since their legs are so narrowly spaced.



The last step is to flash the firmware to the Arduino. I recommend using [Avrdudess](https://github.com/ZakKemble/AVRDUDESS). See more details in the [general assembly instructions](https://quinnfreedman.github.io/modular/docs/assembly).

As soon as you flash the Arduino, the big front LED should come on and should start fluctuating. Turning the knobs should control the behavior of the LED. Once you plug the module into the case, you should see the same fluctuation in the output CV.

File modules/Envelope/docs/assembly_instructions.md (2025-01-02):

# Envelope Assembly Instructions

See [general assembly instructions](https://quinnfreedman.github.io/modular/docs/assembly)

Note how the output jacks J5-J8 partially hang off the board. See the note in the BoM.

## Components

**Most** parts are available on Tayda ([cart link](https://www.taydaelectronics.com/savecartpro/index/savenewquote/qid/36140668403), [quick-order CSV](https://freemodular.org/modules/Envelope/fm_envelope_tayda_bom.csv)).

See [general components notes](https://quinnfreedman.github.io/modular/docs/components) for more info about acquiring parts.

Interactive BOM: [front](https://quinnfreedman.github.io/fm-artifacts/Envelope/envelope_pcb_front_interactive_bom.html), [back](https://quinnfreedman.github.io/fm-artifacts/Envelope/envelope_pcb_back_interactive_bom.html)

| | Board | Reference | Part | Value | Source  | Comment |
| -- | ----- | --- | --- | --- | --- | --- |
| | Front | R1, R3, R5, R7 | Resistor | 100kΩ | [Tayda](https://www.taydaelectronics.com/10-x-resistor-100k-ohm-1-4w-1-metal-film-pkg-of-10.html) | |
| | Front | R2, R4, R6, R8 | Resistor | 200kΩ | [Tayda](https://www.taydaelectronics.com/resistor-200k-ohm-1-4w-1-metal-film-pkg-of-10.html) | |
| | Front | R9-R12 | Resistor | 2kΩ | [Tayda](https://www.taydaelectronics.com/resistors/1-4w-metal-film-resistors/test-group-2.html) | Should be 1/5 the value of the potentiometers. So if you are using 50kΩ pots, use 10kΩ resistors here instead. |
| | Back  | R13-R20 | Resistor | 100kΩ | | |
| | Back  | R21-R24 | Resistor | 10kΩ | [Tayda](https://www.taydaelectronics.com/10-x-resistor-10k-ohm-1-4w-1-metal-film-pkg-of-10.html) | Determines LED brightness. Any value between 220Ω-10kΩ might be appropriate depending on which LEDs you have and how bright you want them. Lower resistance values mean more current and brighter LEDs. |
| | Front | R25, R26 | Resistor | 1kΩ | [Tayda](https://www.taydaelectronics.com/10-x-resistor-1k-ohm-1-4w-1-metal-film-pkg-of-10.html) | Determines output impedance |
| | Front | RV1-RV4 | Potentiometer | B10kΩ | [Tayda](https://www.taydaelectronics.com/50k-ohm-linear-taper-potentiometer-d-shaft-pcb-9mm.html), [Thonk](https://www.thonk.co.uk/shop/alpha-9mm-pots-dshaft/) | Linear. A larger value is fine, although if the value is too large the response curve might be a little warped. Make sure to match R9-R12 accordingly. |
| 🔴 | Front | SW1 | Button | TL1105SP (e.g. TL1105SPF250Q) + 1RBLK | [DigiKey (switch)](https://www.digikey.com/en/products/detail/e-switch/TL1105SPF250Q/271559), [DigiKey (cap)](https://www.digikey.com/en/products/detail/e-switch/1RBLK/271579) | The caps for these switches need to be purchased separately. The caps I use are `#1RBLK`. The switches are available in different actuation forces and materials, so the last part of the part number might be a little different. Sometimes, the switches and caps will be sold together and the cap number is appended to the end of the part number. If you don't want to use these specific switches, any "6mm tactile switch" with a standard 4.5mm x 6.5mm mounting pattern like [this one](https://www.taydaelectronics.com/tact-switch-6-6mm-13mm-through-hole-spst-no.html) should work here. Those are a bit narrower, though, so you might want to adjust the faceplate accordingly. |
| | Front | J1-J8 | 3.5mm Jack | THONKICONN (a.k.a PJ398SM or PJ301M-12) | [Tayda](https://www.taydaelectronics.com/pj-3001f-3-5-mm-mono-phone-jack.html), [Thonk](https://www.thonk.co.uk/shop/thonkiconn/) | The bottom row of jacks (J5-J8) hangs one leg off the board. This is in order to keep the cost down, since boards <10cm tall can be printed for a cheaper flat rate. There is a pad labelled GND at the bottom of the module. Use a couple spare resistor legs or bit of wire to connect it to all 4 hanging legs. If you don't ground them, everything should still work fine, but it's good practice to do it for the best signal integrity. |
| | Front | D1-D4 | LED | 3mm | [Tayda](https://www.taydaelectronics.com/leds/round-leds/3mm-leds.html) | My design uses 4 colors (amber, blue, red, green) to match the 4 knob colors, but obviously use whatever colors you want. Different colors might have slightly different brightnesses so you could tune R20-R24 to make them uniform. |
| | Back  | Q1, Q2 | Transistor | 2N3904 | [Tayda](https://www.taydaelectronics.com/2n3904-npn-general-propose-transistor.html), [DigiKey](https://www.digikey.com/en/products/detail/onsemi/2N3904TA/973944) | |
| 🔴 | Back  | U1 | DAC | MCP4922-E/P | [DigiKey](https://www.digikey.com/en/products/detail/microchip-technology/MCP4922-E-P/716251) | |
| | Back  | U2 | Op-amp | MCP6004 | [Tayda](https://www.taydaelectronics.com/mcp6004-single-supply-cmos-ic.html), [DigiKey](https://www.digikey.com/en/products/detail/microchip-technology/mcp6004-i-p/523060) | |
| | Back  | C1 | Capacitor | 10uF | [Tayda](https://www.taydaelectronics.com/10uf-16v-85c-radial-electrolytic-capacitor.html) | Power supply noise filtering capacitor |
| | Back  | C2, C3 | Capacitor | 100nF | [Tayda](https://www.taydaelectronics.com/a-553-0-1uf-50v-ceramic-disc-capacitor-pkg-of-10.html) | Power supply noise filtering capacitor |
| | Back  | A1 | Arduino Nano | v3.0 | [Tayda](https://www.taydaelectronics.com/type-c-nano-3-0-controller-compatible-with-arduino-nano.html) | |
| | Both  | J10-J12 | Pin headers | 1x7, 1x8 | Tayda ([Male](https://www.taydaelectronics.com/40-pin-2-54-mm-single-row-pin-header-strip.html), [Female](https://www.taydaelectronics.com/40-pin-2-54-mm-single-row-female-pin-header.html)), [Amazon](https://www.amazon.com/gp/product/B074HVBTZ4) | Solder the two boards directly together using the male headers or make them detachable using a male/female pair (recommended). |
| | Back  | J13 | IDC connector | 2x8 | [Tayda](https://www.taydaelectronics.com/16-pin-box-header-connector-2-54mm.html) | Eurorack power header. Can use two rows of male pin headers or a shrouded connector (recommended). |
| | Back  | J14 | Configuration Jumper | | [Tayda](https://www.taydaelectronics.com/16-pin-box-header-connector-2-54mm.html) | See **Configuration** |

🔴 = Missing from Tayda BOM

## Configuration

The module has 3 pairs of holes on the reverse side of the back panel (J14). By bridging each pair (either by soldering a wire through both of them or by soldering on pins and using removable jumpers) you can effect the behavior of the module.

Jumpers 1 and 2 control the behavior of the "Aux" output

| Pair 1  | Pair 2  | Aux behavior |
| --- | --- | --- |
| Open | Open | **End-of-rise gate**: Will go high (5v) as soon as the attack stage ends, and will stay high until the cycle ends (output goes to 0) or returns to attack (if the envelope gets re-triggered) |
| Bridged | Open | **End-of-fall gate**: Will go high at end-of-cycle (after release) and will go low again as soon as the next cycle starts (or after the attack stage in ACRC Loop mode) |
| Open | Bridged | **Non-zero gate**: Will go high for the duration of the cycle (as long as the envelope is outputting a positive value) |
| Bridged | Bridged | **Gate-follower**: Will duplicate the Gate input |

Config jumper 3 is not currently used. If there is any behavior of the envelope that you would like to be able to customize, let me know!

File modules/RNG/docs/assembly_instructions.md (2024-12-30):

# RNG Assembly Instructions

See [general assembly instructions](https://quinnfreedman.github.io/modular/docs/assembly)

**Note:** this module does have one surface mount component. It is possible to do by hand but can be a little tricky. See U1/U6 in the bill of materials for details.

## Components

**Most** parts are available on Tayda ([cart link](https://www.taydaelectronics.com/savecartpro/index/savenewquote/qid/02840666568), [quick-order CSV](https://freemodular.org/modules/RNG/fm_rng_tayda_bom.csv)).

See [general components notes](https://quinnfreedman.github.io/modular/docs/components) for more info about acquiring parts.

Interactive BOM: [front](https://quinnfreedman.github.io/fm-artifacts/RNG/rng_pcb_front_interactive_bom.html), [back](https://quinnfreedman.github.io/fm-artifacts/RNG/rng_pcb_back_interactive_bom.html)

| | Board | Reference | Part | Value | Source  | Comment |
| -- | ----- | --- | --- | --- | --- | --- |
| | Front | R1, R20 | Resistor | 100kΩ | [Tayda](https://www.taydaelectronics.com/resistors/1-4w-metal-film-resistors/10-x-resistor-100k-ohm-1-4w-1-metal-film-pkg-of-10.html) | |
| | Front | R2, R3 | Resistor | 1kΩ | [Tayda](https://www.taydaelectronics.com/resistors/1-4w-metal-film-resistors/10-x-resistor-1k-ohm-1-4w-1-metal-film-pkg-of-10.html) | Determines output impedance. Any value is fine. |
| | Front | R4-R7 | Resistor | 10kΩ | [Tayda](https://www.taydaelectronics.com/resistors/1-4w-metal-film-resistors/10-x-resistor-10k-ohm-1-4w-1-metal-film-pkg-of-10.html) | Determines LED brightness. You may want to use a different value if you have different LEDs. A lower value means less resistance and brighter LEDs |
| | Front | RV1-RV3 | Potentiometer | B50kΩ | [Tayda](https://www.taydaelectronics.com/potentiometer-variable-resistors/rotary-potentiometer/50k-ohm-linear-taper-potentiometer-d-shaft-pcb-9mm.html), [Thonk](https://www.thonk.co.uk/shop/alpha-9mm-pots-dshaft/) | Linear. Any value is ok -- just match R13. |
| | Front | D1-D11 | LED | 3mm | [Tayda](https://www.taydaelectronics.com/led-3mm-red.html) | Any standard 3mm LED will work here. |
| | Front | SW1 | Rotary Encoder | EC11 series | [Tayda](https://www.taydaelectronics.com/rotary-encoder-11mm-20-detents-d-shaft-with-switch-vertical.html), [Amazon](https://www.amazon.com/dp/B07D3DF8TK) | |
| | Front | SW2, SW3  | Switch | TAIWAY 200CWMSP1T3B4M2 or equivalent | [Tayda](https://www.taydaelectronics.com/sub-mini-toggle-switch-2m-series-spdt-on-on-pcb-pins.html), [Love My Switches](https://lovemyswitches.com/taiway-sub-mini-spdt-on-on-switch-pcb-mount-long-shaft/), [Thonk](https://www.thonk.co.uk/shop/sub-mini-toggle-switches/) | SPDT ON-ON |
| | Front | J1-J6 | 3.5mm Jack | THONKICONN (a.k.a PJ398SM or PJ301M-12) | [Tayda](https://www.taydaelectronics.com/pj-3001f-3-5-mm-mono-phone-jack.html), [Thonk](https://www.thonk.co.uk/shop/thonkiconn/) | |
| | Both  | J8-J10 | Pin headers | 2x3, 1x8, 1x8 | Tayda ([Male](https://www.taydaelectronics.com/40-pin-2-54-mm-single-row-pin-header-strip.html), [Female](https://www.taydaelectronics.com/40-pin-2-54-mm-single-row-female-pin-header.html)), [Amazon](https://www.amazon.com/gp/product/B074HVBTZ4) | Solder the two boards directly together using the male headers or (recommended) make them detachable using a male/female pair. |
| | Back  | J7 | - | - | | Not used. Expansion points for future features |
| | Back  | J12 | IDC connector | 2x8 | [Tayda](https://www.taydaelectronics.com/16-pin-box-header-connector-2-54mm.html) | Eurorack power header. Can use two rows of male pin headers or (recommended) a shrouded connector. |
| | Back  | R8-R11, R14-R15, R21 | Resistor | 100kΩ | [Tayda](https://www.taydaelectronics.com/resistors/1-4w-metal-film-resistors/10-x-resistor-100k-ohm-1-4w-1-metal-film-pkg-of-10.html) | |
| | Back  | R12, R13, R16 | Resistor | 50kΩ | [Tayda](https://www.taydaelectronics.com/resistors/1-4w-metal-film-resistors/resistor-51k-ohm-1-4w-1-metal-film-pkg-of-10.html) | 51k is fine. R13 should be the same as RV2. |
| | Back  | R17 | Resistor | 1kΩ | [Tayda](https://www.taydaelectronics.com/resistors/1-4w-metal-film-resistors/10-x-resistor-1k-ohm-1-4w-1-metal-film-pkg-of-10.html) | Determines output impedance. Any value is fine. |
| | Back  | R18 | Resistor | 15kΩ | [Tayda](https://www.taydaelectronics.com/resistors/1-4w-metal-film-resistors/10-x-resistor-15k-ohm-1-4w-1-metal-film-pkg-of-10.html) | **R18 was incorrectly labelled as a 2nd R2 in one print run.** Controls the LED brightness for the 7-LED display. Unlike the bottom LEDs, which are in series with R4-R7 (at 5v), this resistor is just used as a current reference (at 5v) by the TLC5940. To match the current across all the LEDs (and therefore the brightness), R18 is calculated by R18 = 5 / ((5 - V_LED) / R4), where V_LED is the voltage drop across one of the LEDs (at the current they will receive). This can be measured or will probably be in the LED datasheet. Then, round to the nearest available resistor value; it doesn't have to be exact. |
| | Back  | R19 | Resistor | 15kΩ | | Controls the available current at the -5v ref regulator. You could probably go a little higher to be more power efficient, but if the -5v voltage sags you can decrease the value. |
| | Back  | C1-C5, C9 **OR** C10 | Capacitor | 100nF | [Tayda](https://www.taydaelectronics.com/capacitors/ceramic-disc-capacitors/a-553-0-1uf-50v-ceramic-disc-capacitor-pkg-of-10.html) | **Optional.** Power supply noise filtering/decoupling capacitors. C9 and C10 go with U6 and U1, respectively. You only need the one for the driver you are using (although there is no harm in adding both). |
| | Back  | C6-C8 | Capacitor | 10uF | [Tayda](https://www.taydaelectronics.com/10uf-16v-85c-radial-electrolytic-capacitor.html) | **Optional.** Power supply noise filtering capacitors |
| | Back  | A1 | Arduino Nano | v3.0 | [Tayda](https://www.taydaelectronics.com/type-c-nano-3-0-controller-compatible-with-arduino-nano.html) | |
| 🔴 | Back  | U1 **OR** U6 | LED driver | TLC5940NT **OR** TLC5940PWPR | [DigiKey (THT)](https://www.digikey.com/en/products/detail/texas-instruments/TLC5940NT/716896), [Octopart (THT)](https://octopart.com/tlc5941nt-texas+instruments-2340792), [Mouser (SMD)](https://mou.sr/3MNLObk) | TLC5940NT, the through-hole version of this part, has been discontinued and is getting somewhat hard to find at a reasonable price. The [surface-mount (HTSSOP) version of this part](https://mou.sr/3MNLObk) is still in production. It is a little harder to solder than the through-hole parts but not impossible to do by hand. See [this tutorial](https://www.youtube.com/watch?v=cp07EHngH4U). There are footprints on the PCB for both the through-hole **and** surface-mount parts. Either will work. **Use one or the other, not both**. The TLC5941NT (also obsolete, also through-hole) *should* be a drop-in replacement if that is easier to find, but I haven't tested it yet. |
| 🔴 | Back  | U2 | DAC | MCP4922-E/P | [DigiKey](https://www.digikey.com/en/products/detail/microchip-technology/MCP4922-E-P/716251), [Mouser](https://mou.sr/4cwtePf) | |
| | Back  | U3 | Op-amp | MCP6004 | [Tayda](https://www.taydaelectronics.com/mcp6004-single-supply-cmos-ic.html), [DigiKey](https://www.digikey.com/en/products/detail/microchip-technology/mcp6004-i-p/523060) | |
| | Back  | U4 | Op-amp | TL072 | [Tayda](https://www.taydaelectronics.com/tl072-low-noise-j-fet-dual-op-amp-ic.html), [DigiKey](https://www.digikey.com/en/products/filter/instrumentation-op-amps-buffer-amps/687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) | |
| 🔴 | Back  | U5 | Voltage regulator| LM4040BIZ-5 | [DigiKey](https://www.digikey.com/en/products/detail/rochester-electronics-llc/LM4040BIZ-5-0/12603438), [Mouser](https://mou.sr/3YNKT1K) | 5V, TO92-3 package. Alternatively, you can use the 10V version and double R9 and R14. |

🔴 = Missing from Tayda BOM

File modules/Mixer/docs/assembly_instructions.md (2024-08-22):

# Mixer Assembly Instructions

See [general assembly instructions](https://quinnfreedman.github.io/modular/docs/assembly)

## Components

All parts are available on Tayda ([cart link](https://www.taydaelectronics.com/savecartpro/index/savenewquote/qid/39240677892), [quick-order CSV](https://freemodular.org/modules/Mixer/fm_mixer_tayda_bom.csv)).

See [general components notes](https://quinnfreedman.github.io/modular/docs/components) for more info about acquiring parts.

[Interactive BOM](https://quinnfreedman.github.io/fm-artifacts/Mixer/mixer_pcb_interactive_bom.html)

| Reference | Part | Value | Source  | Comment |
| --- | --- | --- | --- | --- |
| R1-R9 | Resistor | 100kΩ | [Tayda](https://www.taydaelectronics.com/10-x-resistor-100k-ohm-1-4w-1-metal-film-pkg-of-10.html) | Any value is fine for these, as long as they are all the same, and are significantly higher than the output impedance of the sources you are mixing. |
| R10 | Resistor | 1kΩ | [Tayda](https://www.taydaelectronics.com/10-x-resistor-1k-ohm-1-4w-1-metal-film-pkg-of-10.html) | Determines output impedance. Any value is fine. |
| R11 | Resistor | 4.7kΩ | [Tayda](https://www.taydaelectronics.com/resistors/1-4w-metal-film-resistors/10-x-resistor-4-7k-ohm-1-4w-1-metal-film-pkg-of-10.html) | Determines LED brightness. You may want to use a different value if you have different LEDs. A lower value means less resistance and brighter LEDs. |
| C1,C2 | Capacitor | 100nF | [Tayda](https://www.taydaelectronics.com/a-553-0-1uf-50v-ceramic-disc-capacitor-pkg-of-10.html) | **[Optional]** Power supply noise filtering/decoupling capacitor |
| C3,C4 | Capacitor | 33pF | [Tayda](https://www.taydaelectronics.com/10-x-33pf-50v-ceramic-disc-capacitor-pkg-of-10.html) | **[Optional]** Amp stabilization. Anything in the 100pF-33pF range is probably fine. |
| C5,C6 | Capacitor | 10uF | [Tayda](https://www.taydaelectronics.com/10uf-16v-85c-radial-electrolytic-capacitor.html) | **[Optional]** Power supply noise filtering capacitor |
| RV1-RV4 | Potentiometer | A100kΩ | [Tayda](https://www.taydaelectronics.com/potentiometer-variable-resistors/rotary-potentiometer/100k-ohm-logarithmic-taper-potentiometer-d-shaft-pcb-9mm.html), [Thonk](https://www.thonk.co.uk/shop/alpha-9mm-pots-dshaft/) | Logarithmic is best if you primarily want to mix audio. Any value should work for these as long as they are significantly higher than the output impedance of the sources you are mixing. |
| SW1-SW5 | Switch | TAIWAY 200CWMSP1T3B4M2 | [Tayda](https://www.taydaelectronics.com/sub-mini-toggle-switch-2m-series-spdt-on-on-pcb-pins.html), [Thonk](https://www.thonk.co.uk/shop/sub-mini-toggle-switches/), [Love My Switches](https://lovemyswitches.com/taiway-sub-mini-spdt-on-on-switch-pcb-mount-long-shaft/) | Sub-mini SPDT ON-ON |
| J1-J6 | Jack Socket | PJ301M-12 | [Tayda](https://www.taydaelectronics.com/pj-3001f-3-5-mm-mono-phone-jack.html), [Thonk](https://www.thonk.co.uk/shop/thonkiconn/) | |
| J7 | Power header | IDC male 2x5 | [Tayda](https://www.taydaelectronics.com/10-pin-box-header-connector-2-54mm.html) | |
| J8, J9 | Jumper headers | | Tayda [1](https://www.taydaelectronics.com/connectors-sockets/wafer-housing-crimp-terminal/9376-dup-housing-connector-2-54mm-2-pins.html), [2](https://www.taydaelectronics.com/crimp-terminal-connector-xh-2-54mm.html), [3](https://www.taydaelectronics.com/connectors-sockets/wafer-housing-crimp-terminal/xh-connectors/2-pins-jst-xh-2-54-male-connector-straight-180-degree.html) | **[Optional]** Chain multiple modules together by connecting OUT to IN. |
| D1 | LED | 3mm | [Tayda](https://www.taydaelectronics.com/led-3mm-red.html) | Indicates output level. Optionally, you could use a bidirectional/bipolar LED here. Using a normal LED as shown in the design, with anode on top, will only illuminate when the mixer is outputting a positive voltage. |
| U1 | Op-amp | TL072 | [Tayda](https://www.taydaelectronics.com/tl072-low-noise-j-fet-dual-op-amp-ic.html) | |

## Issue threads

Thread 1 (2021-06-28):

Issues activating options

damwan, 2021-06-28:
Hello!
I reproduced your clock and I must say that it is by far the best I have seen so far for such a simple circuit. But I have some difficulty activating options.
Activating PAUSE_BUTTON_ENABLED or TAP_TEMPO_ENABLED returns the serial message "SSD1306 allocation failed"
And selecting a screen saver other than SS_BARS causes this compilation error:

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

Hoping that you can help me.
thanks a lot

QuinnFreedman, 2021-06-28:
Hi, thanks for giving it a try. Unfortunately, this is a known issue. The problem is that the Arduino Nano has a very limited amount of memory and just storing all the pixels for the screen takes up most of it. Enabling those options takes a few more bytes of memory which means that there is no room to allocate a buffer for the screen.

For now, if you want to enable some options, you will need to disable others. Disabling `CACHE_OUTPUTS_ENABLED` should be a free way to free up one extra byte, but you might have to disable swing or phase shift. I have been meaning to come back to this module to add a couple features and I may be able to optimize a few things slightly to make this better.

As for the screen saver issue, that sounds like a bug. I'll take a look at it as soon as I get a chance.

damwan, 2021-06-29:
Thank you for these explanations it is very clear.
I think I'll stick to the initial setup, I think the Swing and phase shifting will help me.
The clock works robustly and allowed me to synchronize, in addition to eurorack modules, pocket Operators without double trigger in slow tempo with the duty cycle adjustment.
Thanks for your work!

QuinnFreedman, 2021-07-02:
The issue with screensavers should be fixed now. `SS_PULSE` seems to use a lot of memory though. Not sure why.

Closed 2021-06-29.

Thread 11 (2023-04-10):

ENVELOPE: Update

QuinnFreedman, 2023-04-10:
* Rewrite firmware in Rust or temporarily add arduino project to build script
* Re-make faceplate with new components
* Re-make faceplate PCB from updated stencil
* Add module to build script
* Update README to new format
* Create manual
* Confirm working
* Move module to `modules` folder

QuinnFreedman, 2024-08-05:
21a4725958647848f4b11f5e69e87697ecf9b1a2

Closed 2024-08-05.

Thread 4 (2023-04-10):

LFO: Update

QuinnFreedman, 2023-04-10:
* Rewrite firmware in Rust or temporarily add arduino project to build script
* Re-make faceplate with new components
* Re-make faceplate PCB from updated stencil
* Add module to build script
* Update README to new format
* Create manual
* Confirm working
* Move module to `modules` folder

QuinnFreedman, 2024-08-20:
* Faceplate is done
* Hardware is working AFAIK
* 2 of 4 modes are mostly working
* Need to work on v/oct tracking math

Closed 2024-09-05.

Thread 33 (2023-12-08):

BOOST: Remake module

QuinnFreedman, 2023-12-08:
Convert the DiodeDistortion to a input module for line level signals

QuinnFreedman, 2024-09-28:
Hardware should be done. Just waiting for boards to ship so I can test it then it will be added to the site

QuinnFreedman, 2024-10-29:
Fixed minor issue with hardware. Everything is done just need to test before I publish

Closed 2024-11-01.

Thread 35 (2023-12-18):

Build & test Mixer final version

QuinnFreedman, 2023-12-18:

QuinnFreedman, 2023-12-18:
Make sure jack sockets aren't too close to the edge

Closed 2023-12-19.

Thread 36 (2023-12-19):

Adjust mixer pcb layout

QuinnFreedman, 2023-12-19:
Rotate pots to vertical and move jacks and switches slightly to the right

QuinnFreedman, 2023-12-20:
d56c52f6638de49ec85cac73821c0c383b1d94a4

Closed 2023-12-20.

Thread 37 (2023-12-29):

CLOCK: Update faceplate to fit a range of screens

QuinnFreedman, 2023-12-29:
The clock faceplate currently fits some SSD1603 modules I had but doesn't quite fit the latest batch I bought. I think I will replace the screw holes with vertical slots so it is adjustable

QuinnFreedman, 2023-12-30:
15e90fa

Closed 2023-12-30.

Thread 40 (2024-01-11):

RNG: Change PCB uni/bipolar gain and bias input

QuinnFreedman, 2024-01-11:
#31

QuinnFreedman, 2024-01-11:
0491c7f5bdb45521861988ffec70179202a15e1d

QuinnFreedman, 2024-01-11:
* Bias change done in hardware (still need to adapt firmware)
* bipolar gain circuit done in circuitjs, need to move to kicad

QuinnFreedman, 2024-01-17:
This ended up being a larger PCB refactor

Closed 2024-01-17.

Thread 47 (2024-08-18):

Add information about the current draw to each of the modules pages.

rl2939, 2024-08-18:
It would be good to list how much current each module draws on the +12 volt, the -12 volt, and the 5 volt rails.
This would be useful information for those who DIY their power supply.

QuinnFreedman, 2024-08-18:
This is on my list to do. I just recently got the equipment to be able to measure this. I should be able to add these in the next month.

For now, you can assume the current draw is pretty low on all of them. There is no particular analog circuit that would burn a lot of power, so I'd guess they are all probably under 50mA. A large portion of that is going to be on the 5v rail for the digital modules.

QuinnFreedman, 2024-09-05:
It looks like my new power supply can't actually measure this on all 3 channels. I'll buy an actual ammeter. For now it looks like everything is in the 10mA or less neighborhood per rail except for Output which is ~40mA on both rails.

roagm, 2024-09-26:
I have measured the current draw for the modules that I have built. Here is the information in case you find it useful.

**Offset/Atten**
- 12V: 6 mA
- -12V: 6mA
- 5V: N/A

**Clock**
- 12V: N/A
- -12V: N/A
- 5V:
  - 30mA typical
  - 45 mA max (idle, all-white screen)

**Envelope**

- 12V: N/A
- -12V: 1 mA
- 5V 21mA

**Drift**

- 12V: 5 mA
- -12V: 5 mA
- 5V: 25 mA

roagm, 2024-09-29:
**RNG**

- 12V: 5mA
- -12V: 5mA
- 5V: Bias knob seems to affect current draw the most. Probably because it affects how many LEDs in the row of 7 light up
  - 22 mA with Bias knob all the way CCW (all row off)
  - 40 mA with Bias knob all the way CW (all row on)

Closed 2024-10-03.

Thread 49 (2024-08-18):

(Request) Add A Semimodular System

rl2939, 2024-08-18:
Considering that this project attempts to make synthesis accessible to everyone, a semimodular system would be great for those who are new to modular synthesis but don't really know exactly what they want out of a system. It would also cover a lot of bases for those that also want to get started with an "all-in-one" device.

An example of a semimodular system could include:
- A sound source
- A way to shape that sound source (like a filter or wavefolder)
- A VCA
- An Envelope generator
- Some way to play or sequence the system

QuinnFreedman, 2024-08-18:
I'm not opposed to this, but I think this will be a while down the road. I have my next year or so of development filled with ideas for individual modules. Once I have designed each of these parts individually, I would look into combining them into a semimodular.

I'm closing this for now to keep my issues organized, but I appreciate the input

Closed 2024-08-18.

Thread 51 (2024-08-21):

compiled ino / hex file for the clock module

KeLaiFu, 2024-08-21:
I'm currently waiting for my PCBs for the output module to come back from jlc and in the torturous wait i decided to check your other modules.
The clock looks like another great option as I only have a square LFO as my current clock but as a noob with arduino, I dont see a file I can use to program the nano.
Is it there and I am just blind, or could you give me some advice on how to create it, if I need to.

Cheers

KeLaiFu, 2024-08-21:
doh! found it!

Closed 2024-08-21.

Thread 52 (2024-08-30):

output module footprints

KeLaiFu, 2024-08-30:
I have the PCBs for this back from our friends at jlc and all is looking great apart from the footprint for the 6.35mm jack. I have ordered 3 different brands of the jacks and they all have a large flatter pin than the footprint. It's not a major problem as i have plenty of files, but it may be worth revising the footprints so more hardware will fit.

QuinnFreedman, 2024-08-30:
I designed it for ACJS-MN-3 jacks, which do fit nicely, but that was before I found the PJ-629HAN which are much cheaper. In addition to having wider flat pins, the PJ's also have a different pinout - left and right are reversed. I'd be interested to know what pinout your jacks are using -- I wonder if there is a standard.

I should probably update the design to use the PJ's. I'll officially add this to my to-do list

QuinnFreedman, 2024-08-30:
For my future reference -- I'm also seeing the [L11xxx](https://www.mouser.com/datasheet/2/393/110x_m110x_series_cd-2942927.pdf) series which offer both "snap in" and "wide" tails and follow the ACJM pinout, and the [NYS232](https://www.mouser.com/ProductDetail/REAN/NYS232?qs=%252B86TLfaev2%252B2HlyJ9Lqz%2FA%3D%3D) which has wide terminals and doesn't seem to list a pinout.

I guess I need to just pick one model and go with it

KeLaiFu, 2024-08-30:
I better check the pinout before I file anything then, I just picked a bunch that looked the same style on taobao, wasnt aware there could be different pinouts.

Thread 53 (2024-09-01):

Add HTSSOP TLC5940 optional footprint to RNG

QuinnFreedman, 2024-09-01:
The TLC5490NT is discontinued and getting expensive. The HTSSOP version is still in production. I think I want to try to add both footprints to the board so you can populate either one based on availability

QuinnFreedman, 2024-09-28:
This is done in the [rng-smd](https://github.com/QuinnFreedman/modular/tree/rng-smd) branch. Just needs to be tested before merging to main

QuinnFreedman, 2024-10-24:
done 904e10a60a2d12b31272ea36500a8c71f34cd24f

Closed 2024-10-24.

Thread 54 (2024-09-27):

RNG: Values in loop not mutating

roagm, 2024-09-27:
The module always sends the same loop of CV values, regardless of the position of the Chance knob.

The Mutation Enabled LED does turn off when the Chance knob is at full CCW and it turns on when rotating it CW, but the values in the CV loop always remain the same. Turning the module off and on again changes the CV values in the loop, but the new sequence still does not mutate.

I have verified that my potentiometer is working correctly, and I have also made sure that the corresponding pin of the Arduino board is receiving the voltage changes. Additionally, I have tried using three different Arduino Nano boards, but that did not make any difference.

I am using the firmware hex file listed on the module's page

QuinnFreedman, 2024-09-27:
Oops! looks like the ability to actually update the buffer just got left out of the most recent firmware version. Surprised I didn't see that. Should be fixed momentarily.

dlakwi, 2024-09-28:
I can confirm that this fix resolves the issue of values not mutating. I built this module months ago but did not test it as thoroughly as roagm. Thank you roagm and Quinn.

Closed 2024-09-27.

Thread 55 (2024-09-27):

RNG: 7 LEDs not all working

roagm, 2024-09-27:
Some LEDs of the group of 7 at the top of the module do not light up at all.

I have verified that the LEDs work, and I have tried with three different TLC5940NT ICs. With each IC, the LEDs that do not light up are different. I made sure that my three LED driver ICs work properly by testing them with another circuit. I also checked the continuity between the IC and the LEDs and found nothing unusual. Additionally, I have tried using three different Arduino Nano boards and the result is the same.

I am using the firmware hex file found in the module's page.

QuinnFreedman, 2024-09-27:
That is odd. I haven't seen that before.

Do the same LEDs stay off if you twiddle the Time/Bias knobs? Sounds more likely to be a hardware than software issue if the dead LEDs depends on the IC used but just want to make sure.

I know you tested for continuity but is it possible that it's a connection problem between the two boards? I was just working on a module where the stacking headers would sometimes break continuity depending on how you held them.

The TLC5940NT is honestly a huge pain to work with and requires very precise timing. Its conceivable that a different batch of ICs and/or Arduinos with different tolerances could have revealed a timing issue I wasn't experiencing. I'll try some other ICs and see if I find anything.

roagm, 2024-09-27:
The row of LEDs seems to work in the sense that I can see the lights scrolling from right to left depending on the Bias knob, and the length of the loop is shown when adjusting the Time knob. The thing is that some LEDs in that row never turn on.

For instance, with one IC, the middle 3 LEDs never turn on, so I can see a light start scrolling from the right towards the left in time with the clock input. When the light gets to the 3 "dead" LEDs, they don't turn on, but when it is time for the light to move to the left of those 3 LEDs, it does and then it keeps scrolling to the next LED.
With that same IC, when I move the Time knob, I can only see when the loop has a length of 1, 2, or 32. I can still set it to 4, 8, or 16 by counting in my head how many steps I have turned the knob, I just can't see it indicated with the LEDs. The behavior is similar with the other TLC5940s that I have tried, but the "dead" LEDs are different with each IC.

I tried fiddling with the boards as you suggested, but I didn't notice any change in behavior.

I think it's more likely to be a timing issue as you mention rather than a hardware issue.

roagm, 2024-09-27:
I found the source of the problem. It is indeed a hardware issue.

The schematic for the back PCB has pin 19 of the TLC5940 (DCPRG) tied to GND. When I instead connect that pin to +5V, the LED row works properly.

Making that change in the schematic/Gerber files should probably be assessed

QuinnFreedman, 2024-09-27:
Wow, good detective work. I think I have gotten to the bottom of this issue.

The TLC5940 has the ability to add a per-LED correction factor to get a uniform brightness. It also gives you the ability to store those values to EEPROM (persistent storage). Pin 19 is DCPRG ("Dot correction programming"?). When DCPRG is grounded, it reads the correction values from EEPROM. When it is high, it uses the value that is currently in the dot correction register.

I never use this feature at all in the module, so I tied it low because all the chips I bought happened to have all high values in their EEPROM from the factory, so it effectively ignored this feature. But apparently they don't have to. Yours must have some random zeros in the storage from the factory.

Tying VPRG to 5V is probably the right way to go, but I want to double check that I'm not supposed to be writing some data to that register first and we don't get more undefined behavior. Alternatively, maybe I can fix this in firmware by just flashing the right values to the chips EEPROM on first time startup or something.

This is high on my priority now it should be not too bad of a fix one way the other

QuinnFreedman, 2024-09-27:
After looking at the datasheet some more, it looks like VPRG needs to be manipulated in order to write DC values, and I currently have it tied to ground, so I will need to change the PCB regardless. I will probably just tie DCPRG high, since that sounds easy. Also, the default DC register value is defined to be `0x3F` (the maximum value) so that should definitely work.

Thanks for your help tracking down this issue!

QuinnFreedman, 2024-10-24:
The version of the board with this fix was just merged into main after I finally got a chance to confirm it is all working

Closed 2024-10-24.

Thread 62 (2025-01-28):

OffsetAtten module LED resistors 100k / 10k

KeLaiFu, 2025-01-28:
On the OffsetAtten module, the first circuit has a 10k resistor in the opamp circuit for the LED, where as the second one has a 100k in the same place, Is this intentional?

Closed 2025-04-23.

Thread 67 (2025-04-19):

O/A: VPP output difference between channels

extremenerble, 2025-04-19:
Hello Quinn,

First, thanks for all your work and publishing your designs. They're a real joy to build.

I built 2 O/A's and I'm seeing an issue replicated on both of them. The voltage output peak-to-peak is lower on channel 2 by about 1.0-1.3vpp for AC signals and 0.5-0.7vpp for DC signals. Also, full inversion on channel 2 gives you a slightly higher vpp (almost 0.5vpp for AC).

Some background/troubleshooting:
- I sourced all of the parts from Tayda, Mouser (LM324N's), or Aliexpress (pots)
- I've verified the cap and resistor values
- I've swapped the op-amps around
- Reflowed everything twice more

Any input would be greatly appreciated!

QuinnFreedman, 2025-04-19:
Hi, that's definitely odd. I just did a little testing on my own copy to compare, and I found that my 2 channels behaved very consistently (within 20mV of each other).

I was testing a prototype v0.1 module with TL074's. It's possible I messed something up in the later revisions or that the LM324's are behaving differently. I can put a new module together and test it. My memory is a very minor bug fix was the only difference between those versions, though.

One big downside of the module is that the input is unbuffered (which is very silly. There are 2 unused op-amps in the design that I could easily use to buffer the input. I'll update that design soon). In my experience it behaves pretty precisely when the input is coming from a regulated source, but it gets very non-linear and weird when the input is coming from, e.g., a 100k pot bridging power and ground. I would be curious where the input you're testing with is coming from. If you can pass it through a buffered mult or use a regulated bench-top power supply as input that could remove a potential variable. Still, that doesn't explain why the second channel is consistently lower.

My only other idea is that R9 was incorrectly labelled in the schematic. It should be 10k (or the same as R16). It's listed correctly in the assembly instructions page, but it's listed as 100k in the schematic and interactive BoM. I fixed it in the project file but I guess I forgot to export and upload the fix. R9 *shouldn't* affect the output -- it just controls the LED brightness and the LM324's should have plenty of power to drive any value resistor there without sagging the output voltage at all, but if you have it as 100k it might be worth swapping down to 10k to see if that makes a difference.

extremenerble, 2025-04-19:
I did use the BOM in the building guide when I put them together, so the resistors are correct.

I'll test with running inputs through a buffered mult, and also swap in some TL074 and see if any of that makes a difference.

The inputs I'm testing with are Erica EDU VCO and a DIY Plaits, as well as triangle LFOs from a Zlob Skew-Fade and a CubuSynth 4VCLFO modules

Thanks for all of this info, it's really helpful!

extremenerble, 2025-04-19:
Ok so now I can't replicate the problem at all.

I piped in buffered signal and both modules were showing great on both channels. Then I went back to direct inputs and they're still behaving.

Might be dealing with a weird power issue. There are on my test skiff using a µZeus.

Thank you and looking forward to seeing your future designs!

Closed 2025-04-19.

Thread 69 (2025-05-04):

DRIFT possible modification for future rev

extremenerble, 2025-05-04:
Hi, love the Drift module and keep 2 of them in my rack. I wanted to suggest for a future revision to put the output LED after attenuation so you can get a better (relative) sense of the cv output.

An offset knob would also be super handy though maybe impractical design-wise.

Thanks for publishing your work! Looking forward to seeing new modules from you.

QuinnFreedman, 2025-05-06:
Thanks for the ideas! I'll take those into consideration for a future version!

Closed 2025-05-06.

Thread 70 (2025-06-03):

LED footprint: long lead through square pad?

daaaaaaaaaniel, 2025-06-03:
On my DIY build of the Output module, I placed all the LEDs with the longer lead going into the squared pad, and the shorter lead going into the round pad. When I powered on the module, the LEDs behaved in an unexpected way. With no signal, all the LEDs are lit up. As the signal gets louder, the green LEDs become unlit, starting with the bottommost one. As the signal nears maximum volume, the only LED that remains lit are the two red ones on top.

I am suspecting that I put the LEDs in backwards. But I have been under the impression that the long lead of an LED typically marks the positive side (cathode), which should conventionally go into the square pad on the PCB. Is this PCB designed the other way around?

I am using the Tayda LEDs linked in the provided BOM.

QuinnFreedman, 2025-06-03:
I think you're right that the LEDs are just in backwards. In my design, the cathode (shorter leg) goes in the square hole. If you look really closely the silkscreen is also supposed to have a flat edge on that side, but it's barely visible for the 3mm LEDs. (Much more clear for the 5mm ones.) I could make that more clear. As far as I know, that's standard, but I don't know if it's universal. It might be worth adding a little `+` marker to the anode.

Closed 2025-06-03.

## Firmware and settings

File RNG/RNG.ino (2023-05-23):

#include <stdint.h>
#include <SPI.h>
#include <Tlc5940.h>

/*
 * Pins
 */
const uint8_t BIAS_CV_PIN = A0;
const uint8_t CV_ENABLE_PIN = A1;
const uint8_t ENABLED_LED_PIN = A2;
const uint8_t TRIGGER_LED_PIN = A3;
const uint8_t ENCODER_BUTTON_PIN = A5;
const uint8_t GATE_TRIG_SWITCH_PIN = A6;
const uint8_t RANDOMNESS_CV_PIN = A7;

const uint8_t CLOCK_IN_PIN = 2;
//D3: LED Driver
const uint8_t ENCODER_PIN_B = 4;
const uint8_t ENCODER_PIN_A = 5;
const uint8_t GATE_PIN_B = 6;
const uint8_t GATE_PIN_A = 7;
const uint8_t DAC_CS_PIN = 8;
//D9-13: LED Driver

/*
 * Configuration
 */
// The physical number of LEDs you have attatched to the 
// TLC5940 chip.
const int NUM_LEDS = 7;
// Which LED is the "current" one, i.e. the one that shows the
// currently playing value and the one where randomness in added.
const uint16_t LED_OFFSET = 3;
// If in "trigger" mode, this is how many millisecons the trigger
// should stay on for.
const int TRIG_LENGTH_MS = 100;
// The maximum buffer size. AKA the maximul size of the looping
// sequence of random numbers. Can be more or less than NUM_LEDS but
// must allow enough digits to display the buffer size in binary
// plus one for a sign bit. So, if you have a max buffer size of
// 32, you need 2^(6)=32, 6+1=7 LEDs.
const int MAX_BUFFER_SIZE = 32;
// How many miliseconds to show the buffer size after changing it
// before going back to showing the buffer values
const int BUFFER_SIZE_SHOW_TIME = 1000;
// If true, holding down the buffer size dial will increment values
// in powers of two. If false, powers of two are the default and
// holding it down allows you to select other numbers
const int POW2_ON_HOLD = false;

// The max value for numbers in the buffer
// This is currently the max value that can be output by the DAC
// AND the max value that can be output to the LED controller.
// If one of those changes, the buffer values will have to be
// adjusted before writing to one or the other.
const uint16_t MAX_VALUE = (2 << 12) - 1;

// Max value from an analogRead()
// see: https://www.arduino.cc/reference/en/language/functions/analog-io/analogread/
const int MAX_READ_VALUE = 1023;

// If true, LEDs will only be on/off, depending on if the corresponding
// buffer value would trigger gate A or not. Otherwise, grayscale values
// for LED brightness are shown
const bool LED_BINARY = true;
// If true, LED brightness will be one of 4 discrete brightness levels
const bool LED_QUANTIZED = false;
// If true, the buffer values will appear to move left-to-right through
// the led display. Otherwise, values will move right-to-left
const bool LED_MOVE_LTR = true;

// The potentiometers can't go all the way to to 0 or 100%. These offsets adjust
// the input values from pots. Min input value from pots:
const uint16_t POT_ZERO_VALUE = 5;
// max input value from pots
const uint16_t POT_MAX_VALUE = MAX_READ_VALUE - 5;

#define DEBUG_ENABLED false
#define DEBUG_AUTOSTEP false

/*
 * Global variables
 */
volatile uint8_t bufferSize = 8;
volatile bool yoyo = false;
volatile uint16_t buffer[MAX_BUFFER_SIZE];
volatile uint16_t randomness = 0;
volatile uint32_t currentTime = 0;
volatile uint32_t lastStepTime = 0;
volatile uint32_t lastBufferLengthChangeTime = 0;
volatile bool encoderButtonDown = false;
volatile uint8_t ptr = 0;
volatile uint16_t outputValue = 0;

void setup() {
    #if DEBUG_ENABLED
    Serial.begin(9600);
    #endif
    // setup pins
    pinMode(BIAS_CV_PIN, INPUT);
    pinMode(CV_ENABLE_PIN, INPUT);
    pinMode(ENABLED_LED_PIN, OUTPUT);
    pinMode(TRIGGER_LED_PIN, OUTPUT);
    pinMode(ENCODER_BUTTON_PIN, INPUT_PULLUP);
    pinMode(GATE_TRIG_SWITCH_PIN, INPUT);
    pinMode(RANDOMNESS_CV_PIN, INPUT);
    pinMode(CLOCK_IN_PIN, INPUT);
    pinMode(ENCODER_PIN_B, INPUT_PULLUP);
    pinMode(ENCODER_PIN_A, INPUT_PULLUP);
    pinMode(GATE_PIN_B, OUTPUT);
    pinMode(GATE_PIN_A, OUTPUT);
    pinMode(DAC_CS_PIN, OUTPUT);

    digitalWrite(DAC_CS_PIN, HIGH);

    Tlc.init();
    Tlc.clear();
    Tlc.update();

    SPI.begin();
    SPI.setBitOrder(MSBFIRST);
    SPI.setDataMode(SPI_MODE0);

    for (int i = 0; i < MAX_BUFFER_SIZE; i++) {
        buffer[i] = random(MAX_VALUE);
    }

    showStartupLEDS();

    currentTime = millis();

    attachInterrupt(digitalPinToInterrupt(CLOCK_IN_PIN), stepInterruptWrapper, CHANGE);
    enableInterrupt(ENCODER_PIN_A);
}

void showStartupLEDS() {
    const uint8_t stepTime = 120;
    Tlc.clear();
    Tlc.update();
    delay(stepTime);
    uint32_t lastLedUpdate = millis();
    for (uint8_t i = 0; i <= NUM_LEDS / 2; i++) {
        Tlc.set(NUM_LEDS / 2 + i, MAX_VALUE);
        Tlc.set(NUM_LEDS / 2 - i, MAX_VALUE);
        Tlc.update();
        uint32_t now = millis();
        uint32_t delayTime = stepTime - (lastLedUpdate - now);
        lastLedUpdate = now;
        delay(delayTime);
    }
}


ISR(PCINT2_vect) {
    static_assert(ENCODER_PIN_A >= 0 && ENCODER_PIN_A <= 7 &&
                  ENCODER_PIN_B >= 0 && ENCODER_PIN_B <= 7, 
                  "This code assumes that the encoder pins are Arduino digital pins 0..7. Look up PCINT vec for more.");
    rotaryEncoderHandler();
}

/**
 * The loop function runs continuously. It just does preparation stuff like
 * always reading from the potentiometers so that when we get a signal from
 * the clock we already have up-to-date values for those things so we don't
 * have to waste time checking them.
 */
void loop() {
    float _randomness = analogReadPot(RANDOMNESS_CV_PIN) * MAX_VALUE;
    boolean freeze = _randomness == 0 || !digitalRead(CV_ENABLE_PIN);
    if (freeze) {
        _randomness = 0;
    }
    randomness = _randomness;
    uint16_t threshold = MAX_VALUE * analogReadPot(BIAS_CV_PIN);
    //TODO use interrupts for these boolean reads
    bool gatesAreTriggers = analogRead(GATE_TRIG_SWITCH_PIN) > MAX_READ_VALUE / 2;
    encoderButtonDown = !digitalRead(ENCODER_BUTTON_PIN);

    // Write the value to our DAC chip to output the main analog value
    static int16_t lastOutput = -1;
    if (lastOutput != outputValue) {
        MCP4922_write(DAC_CS_PIN, 0, buffer[ptr]);
        lastOutput = outputValue;
    }

    currentTime = millis();

    // Update the gate/trigger outputs
    bool inTriggerWindow = currentTime - lastStepTime < TRIG_LENGTH_MS;
    bool outputGateA = buffer[ptr] > threshold;
    bool outputGateB = !outputGateA;
    if (gatesAreTriggers && !inTriggerWindow) {
        outputGateA = false;
        outputGateB = false;
    }
    digitalWrite(GATE_PIN_A, outputGateA);
    digitalWrite(GATE_PIN_B, outputGateB);
    digitalWrite(ENABLED_LED_PIN, !freeze);
    digitalWrite(TRIGGER_LED_PIN, inTriggerWindow);

    // update display
    bool showBufferSize = encoderButtonDown || currentTime - lastBufferLengthChangeTime <= BUFFER_SIZE_SHOW_TIME;
    updateLeds(showBufferSize, threshold);

    #if DEBUG_AUTOSTEP
    if (currentTime - lastStepTime > 2000) {
        step();
    }
    #endif
}

/**
 * Little wrapper function to call the `step()` function on a CHANGE
 * interrupt from the clock pin. Maybe we should just bind step directly
 * to a RISE trigger but I have gotten less false positives with this
 * method
 */
void stepInterruptWrapper() {
    static int lastValue = digitalRead(CLOCK_IN_PIN);
    const int value = digitalRead(CLOCK_IN_PIN);
    if (lastValue == LOW && value == HIGH) {
        step();
    }
    lastValue = value;
}

/**
 * This function is called via an interrupt whenever the module gets a clock pulse.
 * It does all the core work of stepping through the ringbuffer, doing the random
 * stuff, and setting the LEDs.
 */
void step() {
    // maybe randomize the value at the cursor (ptr)
    if (random(MAX_READ_VALUE) < randomness) {
        buffer[ptr] = random(MAX_VALUE);
    }
    
    // Update the ptr/cursor to point to the next value in the buffer
    static bool reverse = false;
    if (!yoyo) {
        ptr = (ptr + 1) % bufferSize;
        reverse = false;
    } else {
        if (reverse) {
            if (ptr == 0) {
                reverse = false;
            } else {
                ptr--;
            }
        } else {
            if (ptr == bufferSize - 1) {
                reverse = true;
            } else {
                ptr++;
            }
        }
    }

    // record the time so we know when to turn off trigger pulses
    lastStepTime = currentTime;

    #if DEBUG_ENABLED
    Serial.println("step:");
    for (uint8_t i = 0; i < bufferSize; i++) {
        Serial.print(buffer[i], HEX);
        Serial.print(" ");
    }
    Serial.println();
    Serial.print("ptr ");
    Serial.println(ptr);
    Serial.print("randomness ");
    Serial.println(randomness);
    #endif
}

void onRotaryKnobTurned(int direction) {
    #if DEBUG_ENABLED
    Serial.print("onRotaryKnobTurned(");
    Serial.print(direction);
    Serial.println(")");
    #endif
    if (yoyo) {
        direction *= -1;
    }

    if (bufferSize == 1) {
        if (direction == -1) {
            yoyo = !yoyo;
        } else {
            bufferSize = 2;
        }
    } else if (encoderButtonDown == POW2_ON_HOLD) {
        uint16_t i = 1;
        while (true) {
            uint16_t powerOfTwo = (0x01 << i);
            #if DEBUG_ENABLED
            #endif
            if (powerOfTwo == bufferSize) {
                bufferSize = 0x01 << (i + direction);
                break;
            } else if (powerOfTwo > bufferSize) {
                if (direction == -1) {
                    bufferSize = 0x01 << (i - 1);
                } else {
                    bufferSize = powerOfTwo;
                }
                break;
            }
            i++;
        }
    } else {
        bufferSize += direction;
    }
    if (bufferSize > MAX_BUFFER_SIZE) {
        bufferSize = MAX_BUFFER_SIZE;
    }

    lastBufferLengthChangeTime = currentTime;
}

void updateLeds(bool showBufferSize, uint16_t threshold) {
    static uint16_t lastOutput[NUM_LEDS] = {0, 0, 0, 0, 0, 0, 0};
    uint16_t output[NUM_LEDS];
    if (showBufferSize) {
        for (uint8_t i = 0; i < NUM_LEDS - 1; i++) {
            bool ledOn = (bufferSize >> i) & 0x01;
            output[(NUM_LEDS - 1) - i] = ledOn ? MAX_VALUE : 0;
        }
        output[0] = yoyo ? MAX_VALUE : 0;
    } else {
        for (uint8_t led = 0; led < NUM_LEDS; led++) {
            uint8_t index = (ptr + (LED_MOVE_LTR ? -led + LED_OFFSET : led - LED_OFFSET)) % bufferSize;
            if (LED_BINARY) {
                output[led] = buffer[index] > threshold ? MAX_VALUE : 0;
            } else if (LED_QUANTIZED) {
                output[led] = ((buffer[index] >> 9) << 9) | 0b111111111;
            } else {
                output[led] = buffer[index];
            }
        }
    }
    // Only output to the TLC controller if the LEDs have changed
    if (memcmp(output, lastOutput, sizeof(output))) {
        for (uint8_t i = 0; i < NUM_LEDS; i++) {
            lastOutput[i] = output[i];
            Tlc.set(i, output[i]);
        }
        Tlc.update();
    }
}

/**
 * Handler function called on an interrupt when the rotary encoder is turned.
 */
void rotaryEncoderHandler() {
    static bool lastA = digitalRead(ENCODER_PIN_A);
    
    bool a = digitalRead(ENCODER_PIN_A);
    bool b = digitalRead(ENCODER_PIN_B);

    if (a && !lastA) {
        int8_t direction = a == b ? 1 : -1;
        onRotaryKnobTurned(direction);
    }

    lastA = a;
}

inline float clamp(const float x, const float min, const float max) {
    return x < min ? min : x > max ? max : x;
}

float analogReadPot(const uint16_t pin) {
    uint16_t rawValue = analogRead(pin);
    float x = ((float) rawValue - POT_ZERO_VALUE) / (POT_MAX_VALUE - POT_ZERO_VALUE);
    return clamp(x, 0, 1);
}

inline void enableInterrupt(byte pin) {
    *digitalPinToPCMSK(pin) |= bit (digitalPinToPCMSKbit(pin));  // enable pin
    PCIFR  |= bit (digitalPinToPCICRbit(pin)); // clear any outstanding interrupt
    PCICR  |= bit (digitalPinToPCICRbit(pin)); // enable interrupt for the group
}

void MCP4922_write(int cs_pin, byte dac, uint16_t value) {
    byte low = value & 0xff;
    byte high = (value >> 8) & 0x0f;
    dac = (dac & 1) << 7;
    digitalWrite(cs_pin, LOW);
    SPI.transfer(dac | 0x30 | high);
    SPI.transfer(low);
    digitalWrite(cs_pin, HIGH);
}

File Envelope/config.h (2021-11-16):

#ifndef __config_h__
#define __config_h__

#define MILLION 1000000
#define MIN_PHASE_DURATION_MICROS 1
#define MAX_PHASE_DURATION_MICROS (5 * MILLION)
const uint32_t ATTACK_MAX_DURATION_MICROS = MAX_PHASE_DURATION_MICROS;
const uint32_t ATTACK_MIN_DURATION_MICROS = MIN_PHASE_DURATION_MICROS;
const uint32_t DECAY_MAX_DURATION_MICROS = MAX_PHASE_DURATION_MICROS;
const uint32_t DECAY_MIN_DURATION_MICROS = MIN_PHASE_DURATION_MICROS;
//sustain time only used in TRAP mode
const uint32_t SUSTAIN_MAX_DURATION_MICROS = MAX_PHASE_DURATION_MICROS;
const uint32_t SUSTAIN_MIN_DURATION_MICROS = MIN_PHASE_DURATION_MICROS;
const uint32_t RELEASE_MAX_DURATION_MICROS = MAX_PHASE_DURATION_MICROS;
const uint32_t RELEASE_MIN_DURATION_MICROS = MIN_PHASE_DURATION_MICROS;
const uint32_t DELAY_MAX_DURATION_MICROS = MAX_PHASE_DURATION_MICROS;
const uint32_t DELAY_MIN_DURATION_MICROS = MIN_PHASE_DURATION_MICROS;

const float EXP_RATE_SCALE = 4;
const float EXP_FUNCTION_ZERO_THRESH = 0.0001;

const bool LOOP_HARD_SYNC_ON_PING = true;
const bool LOOP_WHEN_GATE_OFF = true;

const uint32_t LED_SHOW_MODE_TIME_MICROS = 2 * MILLION;

const uint16_t ANALOG_READ_MAX_VALUE = 1022;
const uint16_t ANALOG_READ_ZERO_VALUE = 5;

#define DEFAULT_MODE 0

#define GATE_PASSTHROUGH_ENABLED false
#define LED_MODE_INDICATOR_ENABLED false
#define EOR_TRIGGER_ENABLED false
#define EOF_TRIGGER_ENABLED false

#if EOR_TRIGGER_ENABLED || EOF_TRIGGER_ENABLED
const uint16_t TRIGGER_TIME_MICROS = 50000; // 5ms
#endif

//PINS
const uint16_t GATE_IN_PIN = 3;
const uint16_t RETRIG_IN_PIN = 2;
const uint16_t LED_PINS[4] = {5, 6, 7, 8};
const uint16_t DAC_CS_PIN = 9;
#define PCB_VERSION 6
#if PCB_VERSION < 6
#define CV_PIN_A A3
#define CV_PIN_D A1
#define CV_PIN_S A0
#define CV_PIN_R A2
#else
#define CV_PIN_A A3
#define CV_PIN_D A2
#define CV_PIN_S A0
#define CV_PIN_R A1
#endif
#define AUX_PIN_1 A4 
#define AUX_PIN_2 A5 

#define BUTTON_PIN 4

#if GATE_PASSTHROUGH_ENABLED
#define GATE_OUT_PIN AUX_PIN_1
#endif

#if LED_MODE_INDICATOR_ENABLED
#define LED_MODE_INDICATOR_PIN AUX_PIN_2
#endif

#if EOR_TRIGGER_ENABLED
#define EOR_TRIGGER_PIN AUX_PIN_1
#endif

#if EOF_TRIGGER_ENABLED
#define EOF_TRIGGER_PIN AUX_PIN_2
#endif

#endif // __config_h__

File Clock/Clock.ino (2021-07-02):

#include <stdint.h>
#include <Adafruit_GFX.h>
#include <Adafruit_SSD1306.h>

#include "config.h"

#if SWING_ENABLED && PHASE_SHIFT_ENABLED
#define MENU_SIZE 3
#elif SWING_ENABLED || PHASE_SHIFT_ENABLED
#define MENU_SIZE 2
#else
#define MENU_SIZE 1
#endif
 
typedef enum : uint8_t {NAVIGATE, EDIT_FAST, SUBMENU, SUBMENU_EDIT, SLEEP} MenuMode;
typedef enum : uint8_t {MULTIPLY, DIVIDE} ClockMode;

typedef struct {
    uint8_t multiplier;
    ClockMode mode;
    int8_t pulseWidth;
    #if PHASE_SHIFT_ENABLED
    int8_t offset;
    #endif
    #if SWING_ENABLED
    int8_t swing;
    #endif
} Clock;

typedef struct {
    uint8_t bpm;
    Clock clocks[NUM_OUTPUTS];
    int8_t cursor;
    int8_t submenuCursor;
    MenuMode mode;
    bool newInput;
} State;

State state;

Adafruit_SSD1306 display(SCREEN_WIDTH, SCREEN_HEIGHT, &Wire, OLED_RESET);

//The current time. Reccorded here because you can't get time in interrupt handlers
uint32_t lastRecordedTime;

#if CACHE_OUTPUTS_ENABLED
//Cache the values that we output to each clock channel so we don't have to
//call digitalWrite() as often, which takes time
//uint8_t outputCache[NUM_OUTPUTS] = {LOW, LOW, LOW, LOW, LOW, LOW, LOW, LOW};
#if !defined(NUM_OUTPUTS) || NUM_OUTPUTS > 64 || NUM_OUTPUTS <= 0
    static_assert(false, "NUM_OUTPUTS must be between 1 and 64");
#elif NUM_OUTPUTS > 32
    #define cache_t uint64_t 
#elif NUM_OUTPUTS > 16
    #define cache_t uint32_t 
#elif NUM_OUTPUTS > 8
    #define cache_t uint16_t 
#else
    #define cache_t uint8_t
#endif
cache_t outputCache = 0;
#endif

#if defined(__AVR__) && PORTS_ENABLED
static_assert(
    OUTPUT_PINS[0] == A3 &&
    OUTPUT_PINS[1] == 9 &&
    OUTPUT_PINS[2] == A2 &&
    OUTPUT_PINS[3] == 10 &&
    OUTPUT_PINS[4] == A1 &&
    OUTPUT_PINS[5] == 11 &&
    OUTPUT_PINS[6] == A0 &&
    OUTPUT_PINS[7] == 12,
    "Port code is writeen assuming the default output pins. If you change them, you will have to change the code (or don't use ports).");
    constexpr uint8_t PORTB_MASK = 0b11100001;
    constexpr uint8_t PORTC_MASK = 0b11110000;
    #define USE_PORTS
#endif

#if PAUSE_BUTTON_ENABLED
bool paused = false;
#else
const bool paused = false;
#endif

//The last time the rotary encoder button was pused down, or 0 if it is not down
uint32_t buttonLastDepressedTime = 0;

/*
 * Initialize variables, setup pins
 */
void setup() {
    pinMode(ENCODER_BUTTON_PIN, INPUT_PULLUP);
    pinMode(ENCODER_PIN_A, INPUT_PULLUP);
	pinMode(ENCODER_PIN_B, INPUT_PULLUP);
    
    attachInterrupt(digitalPinToInterrupt(ENCODER_PIN_A), rotaryEncoderHandler, CHANGE);
    enableInterrupt(ENCODER_BUTTON_PIN);
    
    #if PAUSE_BUTTON_ENABLED
    pinMode(PAUSE_BUTTON_PIN, INPUT_PULLUP);
    pinMode(PAUSED_LED_PIN, OUTPUT);
    enableInterrupt(PAUSE_BUTTON_PIN);
    #endif

    #if TAP_TEMPO_ENABLED   
    pinMode(CLOCK_INPUT_PIN, INPUT);
    enableInterrupt(CLOCK_INPUT_PIN);
    // attachInterrupt(digitalPinToInterrupt(ENCODER_BUTTON_PIN), rotaryButtonChangeHandler, CHANGE);
    #endif

    display.setRotation(2);
    
    if(!display.begin(SSD1306_SWITCHCAPVCC, SCREEN_I2C_ADDRESS)) {
        Serial.begin(9600);
        Serial.println(F("SSD1306 allocation failed"));
        // Loop forever
        while (true) {
            const uint8_t pin = pgm_read_byte(&OUTPUT_PINS[0]);
            pinMode(pin, OUTPUT);
            digitalWrite(pin, HIGH);
            delay(400);
            digitalWrite(pin, LOW);
            delay(400);
        }
    }

    state.bpm = DEFAULT_BPM;
    state.cursor = -1;
    state.submenuCursor = 0;
    state.mode = NAVIGATE;
    state.newInput = true;

    for (uint8_t i = 0; i < NUM_OUTPUTS; i++) {
        pinMode(pgm_read_byte(&OUTPUT_PINS[i]), OUTPUT);
        const int8_t val = pgm_read_byte(&(DEFAULT_CLOCK_VALUES[i]));
        Clock* clock = &state.clocks[i];

        clock->mode = val < 0 ? DIVIDE : MULTIPLY;
        clock->multiplier = abs(val);
        clock->pulseWidth = 50;
        #if PHASE_SHIFT_ENABLED
        clock->offset = 0;
        #endif
        #if SWING_ENABLED
        clock->swing = 0;
        #endif
    }
    
    lastRecordedTime = micros();
}


void loop() {
    static uint32_t beatStart = micros();
    static uint32_t lastInputTime = micros();

    const uint32_t NOT_PAUSED = 0xffffffff;
    static uint32_t pausedTime = NOT_PAUSED;

    /*  
     * Keep track of time
     */
    static uint32_t numBeats = 0;
    const uint32_t beatMicros = 60000000 / state.bpm;
    const uint32_t currentTime = micros();
    lastRecordedTime = currentTime;

    // If the clock was just un-paused, restore the saved time
    if (!paused && pausedTime != NOT_PAUSED) {
        beatStart = currentTime - pausedTime;
        pausedTime = NOT_PAUSED;
    }

    const bool justPaused = paused && pausedTime == NOT_PAUSED;

    /*
     * Handle the clock outputs
     */
    float elapsedFraction;
    if (!paused || justPaused) {
        uint32_t elapsed = currentTime - beatStart;
        while (elapsed >= beatMicros) {
            elapsed -= beatMicros;
            beatStart = currentTime - elapsed;
            numBeats++;
        }

        // If the pause button was just pressed, reccord how far into
        // the current cycle we are
        if (justPaused) {
            pausedTime = elapsed;
        }    
        
        elapsedFraction = ((float) elapsed) / ((float) beatMicros);
    
        /*
         * Send signals to output pins
         */
        #ifdef USE_PORTS
        uint8_t outputAllPins = 0;
        #endif
        for (int i = 0; i < NUM_OUTPUTS; i++) {
            const Clock clock = state.clocks[i];

            float elapsed = getElapsedFractionForClock(&clock, elapsedFraction, numBeats);
            
            const bool output = elapsed < (float) clock.pulseWidth / (float) 100;
            #ifdef USE_PORTS
            bitWrite(outputAllPins, i, output);
            #elif CACHE_OUTPUTS_ENABLED
            if (output != bitRead(outputCache, i)) {
                bitWrite(outputCache, i, output);
                digitalWrite(pgm_read_byte(&OUTPUT_PINS[i]), output);
            }
            #else
                digitalWrite(pgm_read_byte(&OUTPUT_PINS[i]), output);
            #endif
        }
        #ifdef USE_PORTS
        {
            uint8_t B_OUT = 0;
            B_OUT |= bitRead(outputAllPins, 1) << 1;
            B_OUT |= bitRead(outputAllPins, 3) << 2;
            B_OUT |= bitRead(outputAllPins, 5) << 3;
            B_OUT |= bitRead(outputAllPins, 7) << 4;
            uint8_t C_OUT = 0;
            C_OUT |= bitRead(outputAllPins, 6) << 0;
            C_OUT |= bitRead(outputAllPins, 4) << 1;
            C_OUT |= bitRead(outputAllPins, 2) << 2;
            C_OUT |= bitRead(outputAllPins, 0) << 3;
            cli();
            PORTB = (PORTB & PORTB_MASK) | B_OUT;
            PORTC = (PORTC & PORTC_MASK) | C_OUT;
            sei();
        }
        #endif
    } else {
        elapsedFraction = ((float) pausedTime) / ((float) beatMicros);
    }
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

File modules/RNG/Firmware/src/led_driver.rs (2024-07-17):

use core::{arch::asm, cell::Cell};

use arduino_hal::{
    hal::port::{PB1, PB2, PD3},
    port::{mode::Output, Pin},
    prelude::*,
    spi::ChipSelectPin,
    Spi,
};
use embedded_hal::digital::v2::OutputPin;
use fm_lib::asynchronous::unsafe_access_mutex;

/**
Determines how long each PWM period should be, in clocks.
f_PWM = f_osc/(2 * TLC_PWM_PERIOD) Hz
TLC_PWM_PERIOD = f_osc/(2 * f_PWM)

TLC_PWM_PERIOD = ((TLC_GSCLK_PERIOD + 1) * 4096)/2
The default of 8192 means the PWM frequency is 976.5625Hz
*/
const TLC_GSCLK_PERIOD: u8 = 3;
const TLC_PWM_PERIOD: u16 = 8192; // Doubled because it counts up and down

#[allow(dead_code)]
static WAITING_FOR_XLAT: avr_device::interrupt::Mutex<Cell<bool>> =
    avr_device::interrupt::Mutex::new(Cell::new(false));

/**
This struct is responsible for driving the TLC5940. The pins used are not configurable
because they are all special pins that are internally connected to the ATmega's timers
PWM outputs. A lot of this implementation is very hardware-specific and so it will not
work on anything except an ATmega328P

The TLC5940 doesn't have any internal oscillator so it must receive constant clock
triggers from the microcontroller. It requires 3 different clock signals in addition
to the SPI data and clock lines.

BLANK can be held HIGH to turn off the output. But, on the falling edge, it also
triggers a new PWM cycle. During normal operation, BLANK must be pulsed at the
desired PWM frequency. BLANK is connected to pin D10 (aka PB2) which is internally
connected to OC1B (the 2nd PWM output channel of the ATmega's Timer 1).

GSLK is the high-resolution clock. Each pulse of BLANK, all outputs are enabled and
all counters are reset. Each pulse on GSLK, each counter is decremented and any
outputs are turned off if their counter hits zero. GSLK should pulse 4096 times
per BLANK pulse if you want the full pulse width resolution. GSLK is connected to
D3 (PD3) which is the output of Timer 2.

The TLC5940 does not have a chip-select pin for the SPI protocol. Instead, it is
constantly reading SPI input into a shift register. You can send a pulse to the latch
(XLAT) pin to lock the current contents of the shift register into the device's
memory. You can write SPI data at any time, but you can only latch it between PWM
cycles while the BLANK input is held high. BLANK must be set high first, then XLAT
brought high, and then both brought low in the reverse order, with some time in
between. To achieve this, the XLAT pin is connected to D9 (PB1) which is the other
PWM output of Timer 1 which controls the BLANK pin. The timer is configured in
"Phase and Frequency Correct PWM Mode", which means that the shorter XLAT duty cycle
will be centered in the BLANK pulse. The output on OC1A (PB1) is disabled at startup.
When data is written to the SPI bus, a flat is set and then the output trigger is
enabled. Additionally, the interrupt handler for Timer 1 is enabled. The next time
the timer loops, it will pulse the XLAT pin with the correct timing and then call
the interrupt. The interrupt clears the flag, disables the XLAT pulses, and also
disables the interrupt itself.

This implementation is heavily based on the [SparkFun Arduino Library](https://github.com/sparkfun/SparkFun_TLC5940_Arduino_Library)
as well is [Paul Stoffregen's version](https://github.com/PaulStoffregen/Tlc5940)
which is very similar. However, it is made somewhat simpler by only supporting
a single architecture and ignoring the TCL5940's dot correction mode, error reporting
mode, and other features.
*/
pub struct TLC5940<const NUM_OUTPUTS: usize> {
    _xlatch: Pin<Output, PB1>,
    _blank: ChipSelectPin<PB2>,
    _pwm_ref: Pin<Output, PD3>,
    tc1: arduino_hal::pac::TC1,
    _tc2: arduino_hal::pac::TC2,
}

pub const fn get_u12_payload_size(num_u16s: usize) -> usize {
    usize::div_ceil(num_u16s * 3, 2)
}

impl<const NUM_OUTPUTS: usize> TLC5940<NUM_OUTPUTS>
where
    [(); get_u12_payload_size(NUM_OUTPUTS)]: Sized,
{
    /**
    Initializes the TLC5940 device; Takes ownership of the pins and timers
    used to drive the device since they shouldn't be used for other purposes
    while controlling the device. Only one instance of the driver should
    exist at a time.
    */
    pub fn new(
        spi: &mut Spi,
        pwm_ref: Pin<Output, PD3>,
        mut blank: ChipSelectPin<PB2>,
        mut xlatch: Pin<Output, PB1>,
        tc1: arduino_hal::pac::TC1,
        tc2: arduino_hal::pac::TC2,
    ) -> Self {
        blank.set_high().ok();
        xlatch.set_low();

        // The TPS5940 GS operating mode and shift register values are not defined
        // after power up. One solution is to switch to DC mode first and then back
        // to PWM mode, but that requires an extra IO pin. The other solution is to
        // overflow the input shift register with 193 bits of dummy data and latch
        // it while the TLS540 is in GS PWM mode.
        for _ in 0..193 {
            nb::block!(spi.send(0)).unwrap_infallible();
        }
        xlatch.set_high();
        xlatch.set_low();

        // write initial values
        for _ in 0..get_u12_payload_size(NUM_OUTPUTS) {
            nb::block!(spi.send(0)).unwrap_infallible();
        }
        xlatch.set_high();
        xlatch.set_low();

        unsafe_access_mutex(|cs| WAITING_FOR_XLAT.borrow(cs).set(false));

        // Timer 1: BLANK and XLAT
        // Clear OC1B on compare match when up-counting. Set OC1B on compare match when down counting
        tc1.tccr1a.write(|w| w.com1b().match_clear());
        // phase and frequency correct PWM with ICR1 TOP
        tc1.tccr1b.write(|w| w.wgm1().bits(0b10));
        // pulse width for XLAT
        tc1.ocr1a.write(|w| w.bits(1));
        // pulse width for BLANK (> XLAT)
        tc1.ocr1b.write(|w| w.bits(2));
        // set frequency for blank and xlat
        tc1.icr1.write(|w| w.bits(TLC_PWM_PERIOD));

        // Timer 2: GSCLK
        tc2.tccr2a.write(|w| {
            w
                // Clear OC2B on compare match
                .com2b()
                .match_clear()
                // Fast PWM mode with OCRA TOP
                .wgm2()
                .pwm_fast()
        });
        // Reset PWM on TOP instead of MAX (set by OCR2A) (allows for freq control)
        tc2.tccr2b.write(|w| w.wgm22().set_bit());
        // Lowest possible PWM (clear OC2B immediately)
        tc2.ocr2b.write(|w| w.bits(0));
        // Controls PWM frequency
        tc2.ocr2a.write(|w| w.bits(TLC_GSCLK_PERIOD));

        // Start PWM output 2 with no prescale
        tc2.tccr2b
            .modify(|r, w| unsafe { w.bits(r.bits()) }.cs2().direct());
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

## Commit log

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2020-03-13 added gate/trig switch + reverse feature
    [RNG.ino]
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2020-05-22 working on hardware schematic
    [clock_back_pcb.fzz, clock_front_pcb.fzz]
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2020-07-03 basic clock working w/ PCB
    [clock_back_pcb.fzz, clock_front_pcb.fzz]
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2020-07-04 fixe clock faceplate & long hold responsiveness
    [clock_front_pcb.fzz]
2020-07-05 working on RNG PCB
    [rng_back.fzz, rng_front.fzz]
2020-07-07 WIP working of RNG faceplate
    [rng_back.fzz, rng_front.fzz]
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2020-07-16 exported PCBs for printing
    [Simplex PCB middle.fzz, rng_back.fzz, rng_front.fzz]
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2020-07-25 fixed mistake swithcing +5/+12 power rails
    [Simplex PCB back.fzz]
2020-08-20 fixed logo and copper fill
    [Simplex PCB back.fzz, Simplex PCB front.fzz, Simplex PCB middle.fzz]
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2020-09-24 fixed logo
    [clock_back_pcb.fzz]
2020-09-24 oa ready for printing
    [oa_back.fzz, oa_front.fzz]
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2020-09-24 fixed ground fill bug
    [Simplex PCB front.fzz, clock_front_pcb.fzz, oa_front.fzz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]
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2020-10-15 fixed bug in PCB
    [oa_back.fzz, oa_front.fzz]
2020-10-17 added PCB version labels
    [oa_back.fzz, oa_front.fzz, rng_back.fzz]
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2020-10-26 added aux connections to envelope back
    [envelope_back.fzz]
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2020-11-07 started working on sequencer
    [sequencer_pcb_back.fzz, sequencer_pcb_front.fzz]
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2020-11-12 fixed EOR/EOF, fixed edge cases so envelope can work with 0 CV values
    [envelope_back.fzz]
2020-11-12 working on seq pcb
    [sequencer_pcb_back.fzz, sequencer_pcb_front.fzz]
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2020-11-14 fliped op amp and added caps
    [mixer_pcb.fzz, sequencer_pcb_back.fzz, sequencer_pcb_front.fzz]
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2020-11-24 fixed jack alignment for envelope
    [envelope_front.fzz]
2020-11-24 tweaking sequencer faceplate and PCB
    [sequencer_pcb_back.fzz, sequencer_pcb_front.fzz]
2020-11-26 fixed mixer layout
    [mixer_pcb.fzz]
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2020-11-26 tweaked jack positions in sequencer
    [sequencer_pcb_front.fzz]
2020-11-29 added daisy chaining ports to mixer; moved resistors to back
    [mixer_pcb.fzz]
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2020-11-29 fixed mixer stripboard layout
    [mixer_pcb.fzz]
2020-11-29 fixed clock faceplate
    [clock_front_pcb.fzz]
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2020-12-08 fixed RNG
    [rng_back.fzz]
2020-12-08 removed external pullup resistors
    [rng_back.fzz]
2020-12-08 fixed minor PCB bug
    [rng_back.fzz]
2020-12-29 fixed PCB bug
    [mixer_pcb.fzz]
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2021-01-05 fixed CV bug in RNG
    [RNG.ino]
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2021-01-19 fixed quantizer trigger circuit
    [quantizer_back.fzz]
2021-01-20 fixed missing ground connection
    [sequencer_pcb_back.fzz]
2021-01-22 remvoved pulldown resistors, added current limiting resistors
    [sequencer_pcb_back.fzz]
2021-01-22 fixed flipped leds in faceplate
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2021-01-25 Sequencer LEDs are working
    [sequencer_pcb_back.fzz, sequencer_pcb_front.fzz]
2021-01-30 removed current limiting resistors, cleaned up PCB
    [quantizer_back.fzz, quantizer_front.fzz, rng_back.fzz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]
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2021-02-16 updated buttons w/ resistor
    [sequencer_pcb_front.fzz]
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2021-03-20 removed interrupts to fix race condition
    [Envelope.ino, envelope.c]
2021-03-29 Changed CV input circuits
    [envelope_back.fzz, envelope_front.fzz]
2021-04-09 improved quantizer button debouncing
    [quantizer_front.fzz]
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2021-04-13 moved sequencer to wip
    [sequencer_pcb_back.fzz, sequencer_pcb_front.fzz]
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2021-06-17 fixed updating when deselecting current note
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2021-08-01 moved envelope to kicad
    [envelope_back_pcb.kicad_pcb, envelope_back_pcb.sch, envelope_front_pcb.kicad_pcb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]
2021-08-01 fixed Quantizer PCB
    [quantizer_back_pcb.kicad_pcb, quantizer_back_pcb.sch]
2021-08-01 fixed atten pot on RNG
    [RNG.ino]
2021-10-19 fixed quantizer
    [quantizer_back_pcb.kicad_pcb, quantizer_back_pcb.sch, quantizer_front_pcb.kicad_pcb]
2021-10-19 updated quant gerbers; everything seems to be working
    [quantizer_back.fzz, quantizer_front.fzz]
2021-10-19 redesigned simplex pcb
    [Simplex PCB back.fzz, Simplex PCB front.fzz, Simplex PCB middle.fzz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]
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2021-11-16 minor cosmetic changes to envelope PCB (reordered & renamed some pins)
    [envelope_back.fzz, envelope_back_pcb.kicad_pcb, envelope_back_pcb.sch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]
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2023-04-08 post-processed faceplate for kicad import and added distortion faceplate
    [DiodeDistortion.kicad_pcb, DiodeDistortion.kicad_sch, faceplate.kicad_pcb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]
2023-04-10 updated and converted simplex to new kicad version
    [simplex_pcb_back.kicad_pcb, simplex_pcb_back.kicad_sch, simplex_pcb_back.sch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]
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2023-04-25 Fix some issues with RNG and DD PCBs (closes #6)
    [DiodeDistortion.kicad_pcb, faceplate.kicad_pcb, rng_pcb_back.kicad_pcb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]
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2023-08-25 Fix some bugs in the new Mixer PCB
    [mixer_pcb.kicad_pcb, mixer_pcb.kicad_sch]
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2023-10-18 Fix stack overflow and long press bug
    [main.rs, menu_logic.rs]
2023-10-21 correct rendering of menu values
    [menu_logic.rs]
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2023-12-18 added comments and fixed pin assignments
    [main.rs]
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2024-01-18 switch pw/swing to 64 scale; fix minor units bug
    [menu_logic.rs]
2024-01-19 fixed tricky race condition bug in timer
    [main.rs]
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2024-02-05 added comments and fixed some bugs in led driver
    [led_driver.rs, main.rs]
2024-02-05 fixed some more bugs in the led driver; still need to figure out endian-ness related bug
    [led_driver.rs, main.rs]
2024-02-05 fixed more bugs in led driver; seems to be working now
    [led_driver.rs, main.rs]
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2024-02-05 fix flickering in LED driver
    [led_driver.rs, main.rs]
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2024-02-05 Fix build after rebase
    [main.rs]
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2024-02-09 fix some race condition bugs; fill out RNG main loop
    [main.rs]
2024-02-11 fix -5v ref in rng pcb
    [rng_pcb_back.kicad_pcb, rng_pcb_back.kicad_sch]
2024-02-27 add missing output resistor
    [rng_pcb_back.kicad_pcb, rng_pcb_back.kicad_sch]
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2024-02-29 flip silkscreen for pin header
    [rng_pcb_back.kicad_pcb, rng_pcb_front.kicad_pcb, rng_pcb_front.kicad_sch]
2024-03-01 minor tweaks for return path and inductance for output PCB
    [output_pcb.kicad_pcb]
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2024-03-20 fix polarity mismatch bugs in output pcb
    [hp_amp.kicad_sch, io_board.kicad_sch, line_amp.kicad_sch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]
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2024-04-09 fix another error in output pcb
    [output_pcb.kicad_pcb]
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2024-05-01 Fix O/A power polarity
    [interface.kicad_sch, main.kicad_sch, offset_atten_pcb.kicad_pcb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]
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2024-05-08 Fix errors in output PCB
    [hp_amp.kicad_sch, io_board.kicad_sch, line_amp.kicad_sch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]
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2024-07-15 Fix minor error and improve routing
    [envelope_pcb.kicad_pcb, main.kicad_sch]
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2024-07-15 fix gate inputs for envelope
    [envelope_pcb.kicad_pcb, envelope_pcb.kicad_sch, interface.kicad_sch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]
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2024-07-15 add drift module pcb
    [drift_pcb.kicad_pcb, drift_pcb.kicad_sch, interface.kicad_sch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]
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2024-07-15 add drift faceplate pcb
    [drift_faceplate.kicad_pcb, drift_faceplate.kicad_sch]
2024-07-15 build drift
    [drift_pcb.kicad_pcb]
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2024-08-05 Add envelope assembly instructions; shut off unused DAC
    [envelope_pcb.kicad_pcb]
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2024-08-09 EEPROM saving evelope mode works (but still too slow)
    [main.rs]
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2024-08-14 Basic PWM LED test for Drift
    [main.rs]
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2024-08-21 Add Tayda sources to BoMs and update some Tayda BoMs (#48)
    [fm_clock_tayda_bom.csv, fm_envelope_tayda_bom.csv, fm_rng_tayda_bom.csv]
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2024-08-21 Fixed error in OA BoM
    [fm_oa_tayda_bom.csv]
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2024-08-22 Added 1v/oct tracking for drift; working on bezier texture
    [shared.rs]
2024-08-25 Add Brownian motion Drift mode
    [main.rs]
2024-08-28 Fix broken faceplate GERBER links
2024-08-29 Added missing items to RNG bom
    [fm_rng_tayda_bom.csv]
2024-08-29 First draft of perlin noise
    [main.rs, shared.rs]
2024-09-02 Improved performance of perlin noise
    [main.rs]
2024-09-03 Adjust sample rate and add low pass filter to output
    [drift_pcb.kicad_pcb, main.kicad_sch]
2024-09-03 Add LED gamma correction
    [main.rs, shared.rs]
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2024-09-03 Load different algorithm depending on config switches; minor refactor
    [main.kicad_sch]
2024-09-04 Add Drift BoM
    [fm_drift_tayda_bom.csv]
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2024-09-05 Added CV control for Drift
    [drift_pcb.kicad_pcb]
2024-09-06 Fixed copy-paste error for resistor values
    [fm_drift_tayda_bom.csv]
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2024-10-01 Fix typo
    [clock_faceplate_pcb.kicad_pcb]
2024-10-02 Add reset to clock
    [main.rs]
2024-10-03 Remove vestigial connection to reduce AUX output current -- totally backwards compatible
    [envelope_pcb.kicad_pcb, main.kicad_sch]
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2024-10-11 Add back in some components that got accidentally removed from Envelope
    [envelope_pcb.kicad_pcb]
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2024-10-11 Update clock faceplate PCB to match button hole size changes
    [clock_faceplate_pcb.kicad_pcb]
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2024-10-13 Fix Boost jack socket alignment
    [Boost.kicad_pcb]
2024-10-16 Add second mounting hole to Drift
    [drift_pcb.kicad_pcb, drift_pcb.kicad_sch]
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2024-10-19 Add back board labels that got removed accidentally
    [output_pcb.kicad_pcb]
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2024-10-22 Flip boost pots
    [Boost.kicad_pcb, Boost.kicad_sch]
2024-10-23 Add SMD option for LED driver on RNG
    [led_driver.kicad_sch, rng_pcb_back.kicad_pcb, rng_pcb_back.kicad_sch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]
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2024-10-23 Fix boost format
    [boost_faceplate.kicad_pcb, boost_faceplate.kicad_sch, boost_pcb.kicad_pcb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]
2024-10-23 Fix #55 and add decoupling capacitors
    [led_driver.kicad_sch, rng_pcb_back.kicad_pcb, rng_pcb_back.kicad_sch]
2024-10-24 Fix wrong resistor designators on RNG
    [led_driver.kicad_sch, rng_pcb_back.kicad_pcb]
2024-10-24 Fix issues from git merge
    [Boost.kicad_pcb, Boost.kicad_sch, boost_pcb.kicad_pcb]
2024-10-24 Update BOM links assembly_instructions.md
    Correcting the links to the BOM URLs for Clock module
2024-10-30 Fix edge cuts discontinuity
    [boost_pcb.kicad_pcb]
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2024-11-12 Fix output faceplate solder mask side
    [output_faceplate.kicad_pcb]
2024-12-30 Add missing resistors to RNG BOM
2025-01-01 Update kicad files to reflect 8-pin connections instead of 6-pin.
    [rng_pcb_front.kicad_pcb, rng_pcb_front.kicad_sch]
2025-02-04 Working on ideas for oscillator voice
    [main.rs]
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2025-03-09 Changed which board the 1/4 jacks are soldered to. (#66)
    * Changed which board the 1/4 jacks are soldered to.
    * Updated references to resistor values of 2k2 to 2.2k
    * Updated values of resistors that appear to be formatted incorrectly.
    [output_pcb.kicad_pcb, volume_meter.kicad_sch]
2025-03-09 Add link to stacking pin headers on Tayda in Output module BOM and assembly guide (#64)
    [fm_output_tayda_bom.csv]
2025-04-18 Replace ONCE mode with STOP mode for clock channels
    [main.rs, menu_logic.rs]
2025-04-23 Add buffer to O/A; (see #67) closes #62
    [interface.kicad_sch, main.kicad_sch, offset_atten_pcb.kicad_pcb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]
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2025-05-11 Fix mistake in quantizer schematic; add to build script
    [quantizer_pcb.kicad_pcb, rear_panel.kicad_sch]
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2025-05-11 Fix bad connection
    [quantizer_pcb.kicad_pcb]
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2025-05-11 Add ability to switch between channels in UI
    [front_panel.kicad_sch, quantizer_pcb.kicad_sch, rear_panel.kicad_sch]
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2025-05-11 Switch to non-inverting op-amp output
    [front_panel.kicad_sch, rear_panel.kicad_sch]
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2025-05-11 Implement glide, switch to fixed sample rate
    [main.rs]
2025-05-11 Fixed some errors in PCB
    [quantizer_pcb.kicad_pcb]
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2025-05-11 fix scale shift bug
    [main.rs]
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2025-05-25 add blank pullup (bump PCB to v1.0) and add trigger delay
    [front_panel.kicad_sch, quantizer_pcb.kicad_pcb, quantizer_pcb.kicad_sch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]
2025-06-02 Fix quant not writing to second DAC channel
    [main.rs]
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2025-06-02 Add tutorial and re-add test points to PCB
    [quantizer_pcb.kicad_pcb, rear_panel.kicad_sch]
2025-06-04 Fix panic at max output
    [main.rs]
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2025-06-04 Fix some DRC errors
    [front_board.kicad_sch, logic_pcb.kicad_pcb, logic_pcb.kicad_sch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]
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2025-06-04 Fix wrong pin ordering on logic front; bump both boards to v1.0
    [analog.kicad_sch, front_board.kicad_sch, logic.kicad_sch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]
2025-06-04 Restore changes to quantizer PCB that got accidentally squashed in merge
    [quantizer_pcb.kicad_pcb, rear_panel.kicad_sch]
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2025-06-25 Fix O/A typo
    [main.kicad_sch]
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2025-10-30 Rearrange biodata PCB to allow mounting bolt; update CV algorithm
    [biodata_pcb.kicad_pcb, biodata_pcb.kicad_sch, front_board.kicad_sch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]
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2025-10-30 Fix broken links
    [fm_biodata_tayda_bom.csv]
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
